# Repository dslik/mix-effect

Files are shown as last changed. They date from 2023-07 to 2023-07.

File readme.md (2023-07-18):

## Project Overview
An open-hardware moduar control surface for vision mixers, such as OBS and ATEM.

Modules include:

* 2810A/2811A Source Selectors
* 2820A/2821A Transtion Controllers
* 2850A/2851A Source Meters
* 2860A Level Controller
* 2880A Touch Screen Controller
* 2890A Power Controller

All modules fit into a standard Eurorack chassis (but do not use Eurorack power), allowing you to create your own layouts with as many sources and M/E channels as needed. This also allows additional custom and use-specific modules are easily added.

## Project Goals
* Modular: Combine functional blocks that way you need and the way you want.
* Extensible: Easy to add new functionality and modules.
* Open source: Available for use and extension with minimal restrictions. See the [license](./license.md) for more details.
* Low-cost: Each module's BOM costs under $100, with some modules costing under $50.

## Components

Part # | Name | Status | BOM Cost | OSHWA | Cert # |
|-|-|-|-|-|-|
| 2810A v1.4 | Four-channel Source Selector | Coming Soon | | Not OSHWA Certified | |
| 2811A v1.4 | Two-channel Source Selector with Shift | Coming Soon | | Not OSHWA Certified | |
| 2820A v0.2 | Transition Controller | Coming Soon | | Not OSHWA Certified | |
| 2821A v0.1 | Transition Controller Expansion | Coming Soon | | Not OSHWA Certified | |
| 2850A v1.0 | Four-channel Source Meters | Coming Soon | | Not OSHWA Certified | |
| 2851A v1.0 | Two-channel Source Meters with Shift | Coming Soon | | Not OSHWA Certified | |
| 2860A v0.2 | Source Level Controller | Coming Soon | | Not OSHWA Certified | |
| 2880A v0.2 | Touch Screen Controller | Coming Soon | | Not OSHWA Certified | |
| 2890A v0.1 | Power Controller | Coming Soon | | Not OSHWA Certified | |

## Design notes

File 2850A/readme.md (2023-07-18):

# Source Meters Module

Four-channel program audio monitor for input sources.

Initial features include:
- Four source inputs
- Stereo PPM meters per input source
- Select/mute button for source audio control
- Channel gain adjust when used with 2850A
- Compatible with mixers and DAWs that support Mackie Control Universal over MIDI

The many small LEDs on the 2850-0301 LED board are difficult to reliably hand-assembly, so this board is best ordered pre-assembled from your PCB house. BOM and component placement files are provided for this board (2850-0301).

Full assembly instructions will be uploaded soon.

# Build Journal

_Feel free to ask questions by opening an issue!_

## 2023-07-18

Here's what this module looks like fuly assembled:



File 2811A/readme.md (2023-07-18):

The 2811A uses the same boards as the 2810A, with the exception of the front panel.

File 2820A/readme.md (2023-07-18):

The Transition Controller is not fully completed or tested.

Specifically, the 2820-0401 board has known errata and needs to be updated.

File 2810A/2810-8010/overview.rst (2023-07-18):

********
Overview
********

This document describes the materials, processes, outcomes and verifications required to successfully assemble and test a 2810A Source Selector module, a sub-component of the Eurorack Mix/Effects Control Surface.

A first-time reader should carefully review section 2 - prerequisites, and section 3 - preparation before beginning the assembly process.

This document serves both as instructions and as a record of the assembly of the product. When you finish each step in this document, sign your name (or apply your stamp) in the "Signature/Stamp" box on the right to provide a record of completion.

When things go wrong, this document provides guidance for common issues that have been encountered in the past. When this document does not provide guidance, please contact your quality management representative, who will help you fill out an exception report. These reports help improve process quality and product quality, and these reports are incorporated into future revisions of this document.

Always remember: If you are unable to successfully complete these instructions, that means the processes supporting you (including this document) have failed you. Our processes are built for your success, and by improving our processes, we help everyone succeed.

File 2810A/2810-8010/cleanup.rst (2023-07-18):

********
Clean-up
********

Consumables
***********

This packaging process takes 5 minutes.

.. tabularcolumns:: |>{\raggedright\arraybackslash}\Y{0.10}
                    |>{\raggedright\arraybackslash}\Y{0.70}
                    |>{\raggedright\arraybackslash}\Y{0.20}|

.. _tbl_2810_cleanup_consumables:

.. list-table:: Consumables cleanup
    :class: longtable
    :header-rows: 1
    :align: center 

    * - Step #
      - Description
      - Signature
    * - 7.1.1
      - If the ESD gloves have contacted solder paste, or are soiled, they shall be disposed of in the standard waste bin.
      - 
        .. raw:: latex

          \includegraphics[align=t,scale=1]{../../images/doc_stamp.pdf}
    * - 7.1.2
      - If there is unused solder paste in the syringe, it shall be returned to stores.
      - 
        .. raw:: latex

          \includegraphics[align=t,scale=1]{../../images/doc_stamp.pdf}
    * - 7.1.3
      - If there is unused solder wire on the spool, it shall be returned to stores.
      - 
        .. raw:: latex

          \includegraphics[align=t,scale=1]{../../images/doc_stamp.pdf}
    * - 7.1.4
      - The Scott shop title shall be disposed of in the standard waste bin.
      - 
        .. raw:: latex

          \includegraphics[align=t,scale=1]{../../images/doc_stamp.pdf}
    * - 7.1.5
      - Reel tape cuttings and loose component packaging shall be disposed of in the standard waste bin.
      - 
        .. raw:: latex

          \includegraphics[align=t,scale=1]{../../images/doc_stamp.pdf}

Tools
*****

This cleanup process takes 5 minutes.

.. tabularcolumns:: |>{\raggedright\arraybackslash}\Y{0.10}
                    |>{\raggedright\arraybackslash}\Y{0.70}
                    |>{\raggedright\arraybackslash}\Y{0.20}|

.. _tbl_2810_cleanup_tools:

.. list-table:: Tools cleanup
    :class: longtable
    :header-rows: 1
    :align: center 

    * - Step #
      - Description
      - Signature
    * - 7.2.1
      - All tools shall be returned to the "M/E Assembly Tools" container, and returned to the stores supply shelf.

        .. raw:: latex

          \vspace*{1ex}

        If any tools are damaged or worn, return the container to stores, and let the manager know which tool is damaged or worn.
      - 
        .. raw:: latex

          \includegraphics[align=t,scale=1]{../../images/doc_stamp.pdf}
    * - 7.2.2
      - Remove this document from the springback binder.
      - 
        .. raw:: latex

          \includegraphics[align=t,scale=1]{../../images/doc_stamp.pdf}
    * - 7.2.3
      - Print a new copy of this document, and insert it into the springback binder that this document was originally in.
      - 
        .. raw:: latex

          \includegraphics[align=t,scale=1]{../../images/doc_stamp.pdf}
    * - 7.2.4
      - Return the springback binder with the newly printed document to the 2810A section of the store supply shelf.
      - 
        .. raw:: latex

          \includegraphics[align=t,scale=1]{../../images/doc_stamp.pdf}

.. raw:: latex

          \newpage

Workspace
*********

This packaging process takes 5 minutes.

.. tabularcolumns:: |>{\raggedright\arraybackslash}\Y{0.10}
                    |>{\raggedright\arraybackslash}\Y{0.70}
                    |>{\raggedright\arraybackslash}\Y{0.20}|

.. _tbl_2810_cleanup_workspace:

.. list-table:: Workspace cleanup
    :class: longtable
    :header-rows: 1
    :align: center 

    * - Step #
      - Description
      - Signature
    * - 7.3.1
      - Make sure that the workspace is clean and as it was when you started the assembly.

        .. raw:: latex

          \vspace*{1ex}

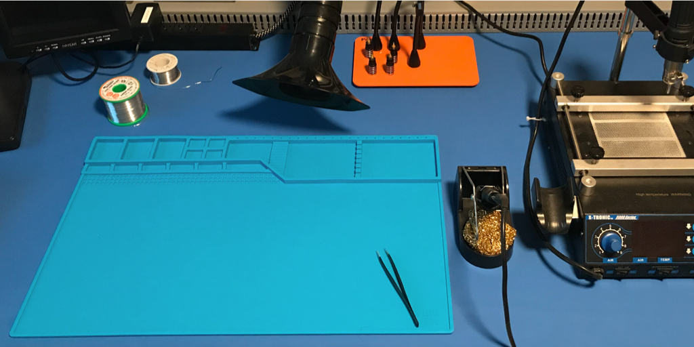
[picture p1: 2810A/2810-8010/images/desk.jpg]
        
           
            Clean assembly workstation
      - 
        .. raw:: latex

          \includegraphics[align=t,scale=1]{../../images/doc_stamp.pdf}

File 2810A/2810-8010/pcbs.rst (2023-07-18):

**********************
Printed Circuit Boards
**********************

2810-0101 PCB
--------------

.. tabularcolumns:: |>{\raggedright\arraybackslash}\Y{1}|

.. _tbl_pcb_2810_0101:

.. list-table:: 2810-0101 PCB
    :class: longtable
    :header-rows: 1
    :align: center 

    * - 2810-0101 PCB
    * - 
        .. _fig_2810_0101_front:

        

            2810-0101 PCB Front
    * - 
        .. _fig_2810_0101_rear:

        

            2810-0101 PCB Rear

.. raw:: latex

          \newpage

2810-0201 PCB
--------------

.. tabularcolumns:: |>{\raggedright\arraybackslash}\Y{1}|

.. _tbl_pcb_2810_0201:

.. list-table:: 2810-0201 PCB
    :class: longtable
    :header-rows: 1
    :align: center 

    * - 2810-0201 PCB
    * - 
        .. _fig_2810_0201_front:

        

            2810-0201 PCB Front
    * - 
        .. _fig_2810_0201_rear:

        

            2810-0201 PCB Rear

.. raw:: latex

          \newpage

2810-0301 PCB
--------------

.. tabularcolumns:: |>{\raggedright\arraybackslash}\Y{1}|

.. _tbl_pcb_2810_0301:

.. list-table:: 2810-0301 PCB
    :class: longtable
    :header-rows: 1
    :align: center 

    * - 2810-0301 PCB
    * - 
        .. _fig_2810_0301_front:

        

            2810-0301 PCB Front
    * - 
        .. _fig_2810_0301_rear:

        

            2810-0301 PCB Rear

.. raw:: latex

          \newpage

2810-0401 PCB
--------------

.. tabularcolumns:: |>{\raggedright\arraybackslash}\Y{1}|

.. _tbl_pcb_2810_0401:

.. list-table:: 2810-0401 PCB
    :class: longtable
    :header-rows: 1
    :align: center 

    * - 2810-0401 PCB
    * - 
        .. _fig_2810_0401_front:

        

            2810-0401 PCB Front
    * - 
        .. _fig_2810_0401_rear:

        

            2810-0401 PCB Rear

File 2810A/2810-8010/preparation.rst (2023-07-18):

***********
Preparation
***********

Workspace
*********

Before starting assembly, check out an assembly desk for a minimum of two hours. A single unit can be assembled in two hours, with an additional hour per additional unit.

.. _fig_assembly_desk:


   
    Assembly Desk

.. tabularcolumns:: |>{\raggedright\arraybackslash}\Y{0.10}
                    |>{\raggedright\arraybackslash}\Y{0.70}
                    |>{\raggedright\arraybackslash}\Y{0.20}|

.. _tbl_prep_workspace:

.. list-table:: Prepare workspace
    :class: longtable
    :header-rows: 1
    :align: center 

    * - Step
      - Description
      - Signature/Stamp
    * - 3.1.1
      - Verify that the workspace has a clean assembly mat and anti-static mat, and that the cleaning record has been signed since last use.
      - 
        .. raw:: latex

          \includegraphics[align=t,scale=1]{../../images/doc_stamp.pdf}

    * - 3.1.2
      - Verify that the HEPA fume extractor turns on, and you can feel air suction from the nozzle.
      - 
        .. raw:: latex

          \includegraphics[align=t,scale=1]{../../images/doc_stamp.pdf}

    * - 3.1.3
      - Verify that the 5040-XTS rework station soldering iron tip is not worn down. If it is worn down, obtain a new 900M-T-I tip from the stores department.
      - 
        .. raw:: latex

          \includegraphics[align=t,scale=1]{../../images/doc_stamp.pdf}

Project consumables
*******************

Obtain each of the below consumable items from the stores department:

.. tabularcolumns:: |>{\raggedright\arraybackslash}\Y{0.10}
                    |>{\raggedright\arraybackslash}\Y{0.70}
                    |>{\raggedright\arraybackslash}\Y{0.20}|

.. _tbl_2810_consumables:

.. list-table:: Assembly consumables
    :class: longtable
    :header-rows: 1
    :align: center 

    * - Item #
      - Description
      - Signature/Stamp
    * - 3.2.1
      - 
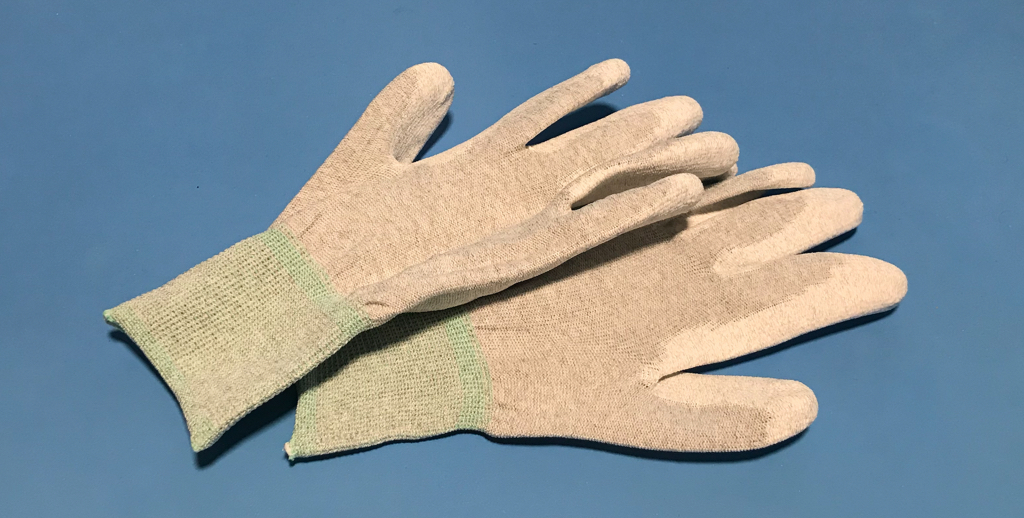
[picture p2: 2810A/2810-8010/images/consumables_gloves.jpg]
        
           
            1 pair ESD gloves

        If you prefer to use your own pair of ESD gloves, make sure they are tested before use.
      - 
        .. raw:: latex

          \raisebox{15\height}{\includegraphics[align=t,scale=1]{../../images/doc_stamp.pdf}}

    * - 3.2.2
      - 
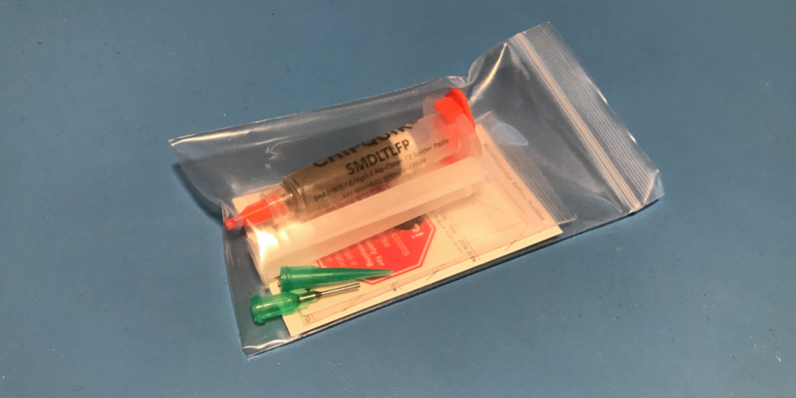
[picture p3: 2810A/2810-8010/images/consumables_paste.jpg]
        
           
            1 syringe of Chip Quik SMDLTLFP Solder Paste Sn42/Bi57.6/Ag0.4 No-Clean Lead Free
      - 
        .. raw:: latex

          \raisebox{15\height}{\includegraphics[align=t,scale=1]{../../images/doc_stamp.pdf}}

    * - 3.2.3
      - 
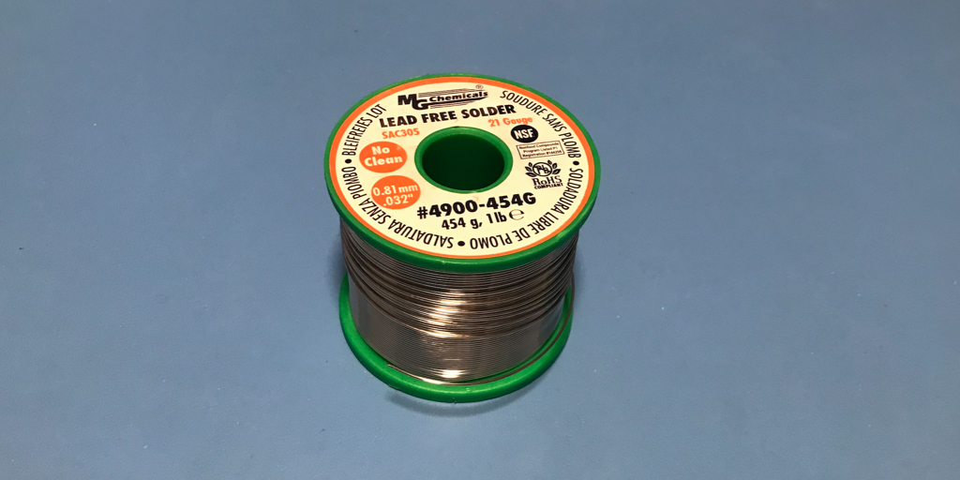
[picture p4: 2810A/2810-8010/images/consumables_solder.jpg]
        
           
            1 spool MG Chemicals 4900 Lead Free No-Clean Wire Solder Sn96.2Ag2.8Cu0.4 (96.2/2.8/0.4) 20 AWG
      - 
        .. raw:: latex

          \raisebox{15\height}{\includegraphics[align=t,scale=1]{../../images/doc_stamp.pdf}}

    * - 3.2.4
      - 
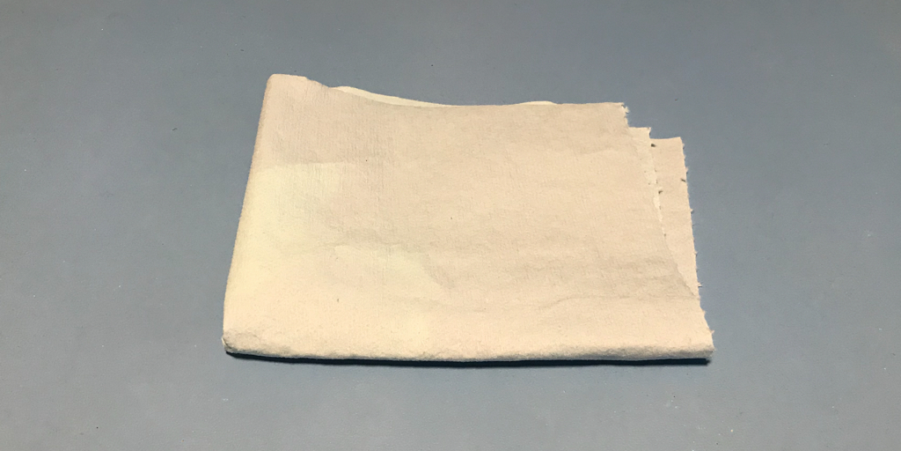
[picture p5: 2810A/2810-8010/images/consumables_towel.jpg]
        
           
            1 square of Scott Shop Towel
      - 
        .. raw:: latex

          \raisebox{15\height}{\includegraphics[align=t,scale=1]{../../images/doc_stamp.pdf}}

.. raw:: latex

          \newpage

Project tools
*************

Obtain a tools container labelled "28XX Assembly Tools" from the 28XX section of the stores supply shelf. At your assembly desk, use :numref:`tbl_2810_tools` to verify that all the required tools are present.

If any required tools are missing, return all tools and the tools container to the stores department, and obtain another tools container.

.. _fig_assembly_tools:

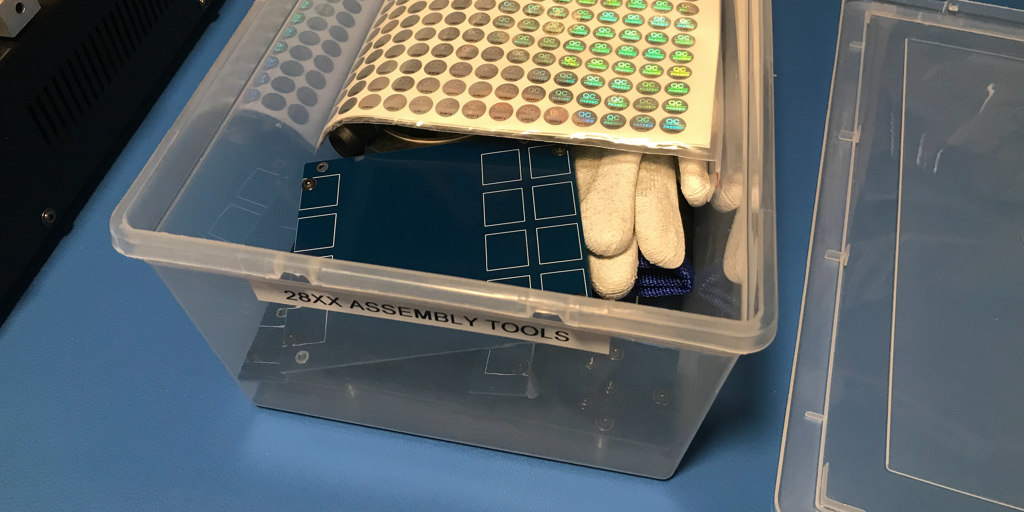
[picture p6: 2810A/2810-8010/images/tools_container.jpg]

   
    Tools Container

Remove each of the following tools from the tools container, and place them on the anti-static mat of the assembly desk:

.. tabularcolumns:: |>{\raggedright\arraybackslash}\Y{0.10}
                    |>{\raggedright\arraybackslash}\Y{0.70}
                    |>{\raggedright\arraybackslash}\Y{0.20}|

.. _tbl_2810_tools:

.. list-table:: Assembly tools
    :class: longtable
    :header-rows: 1
    :align: center 

    * - Item #
      - Description
      - Signature/Stamp
    * - 3.3.1
      - 
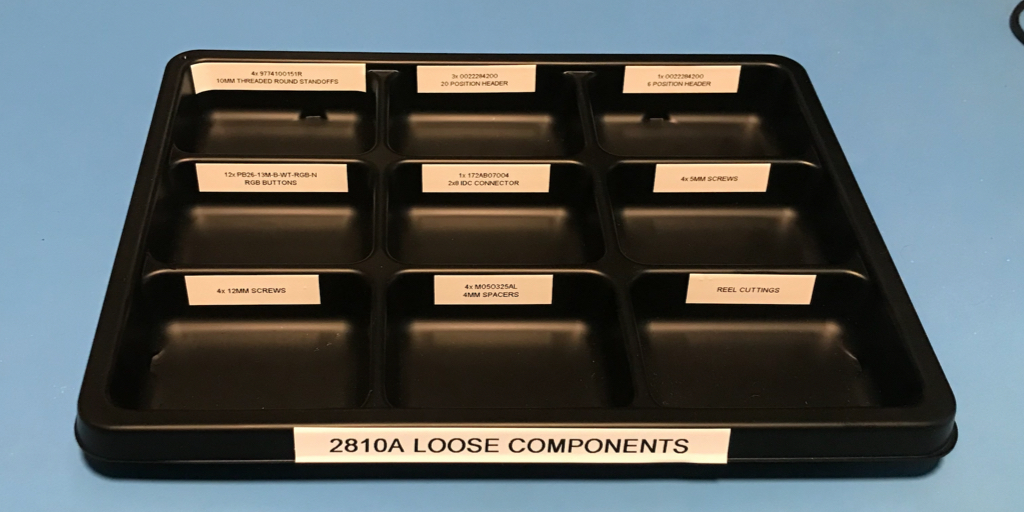
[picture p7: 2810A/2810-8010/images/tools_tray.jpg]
        
           
            Hozan F-23 components tray
      - 
        .. raw:: latex

          \raisebox{15\height}{\includegraphics[align=t,scale=1]{../../images/doc_stamp.pdf}}
    * - 3.3.2
      - 
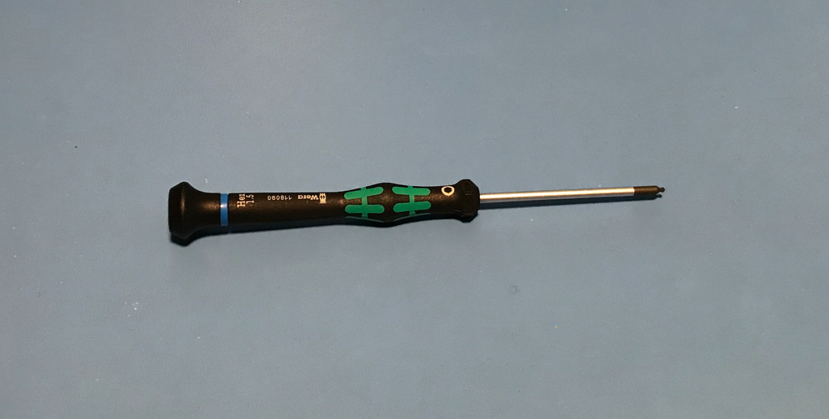
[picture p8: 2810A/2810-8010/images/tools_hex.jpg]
        
           
            1.5mm Hex screwdriver
      - 
        .. raw:: latex

          \raisebox{15\height}{\includegraphics[align=t,scale=1]{../../images/doc_stamp.pdf}}
    * - 3.3.3
      - 
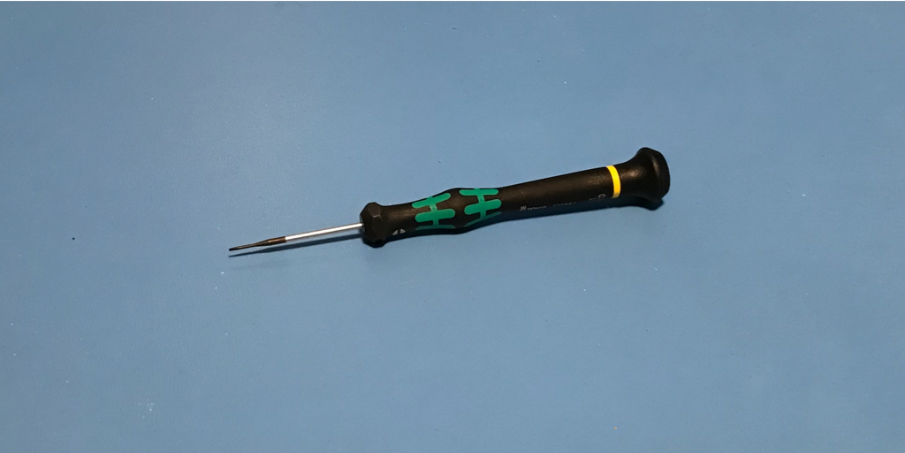
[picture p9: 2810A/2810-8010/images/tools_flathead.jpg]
        
           
            1mm flat-head screwdriver
      - 
        .. raw:: latex

          \raisebox{15\height}{\includegraphics[align=t,scale=1]{../../images/doc_stamp.pdf}}
    * - 3.3.4
      - 
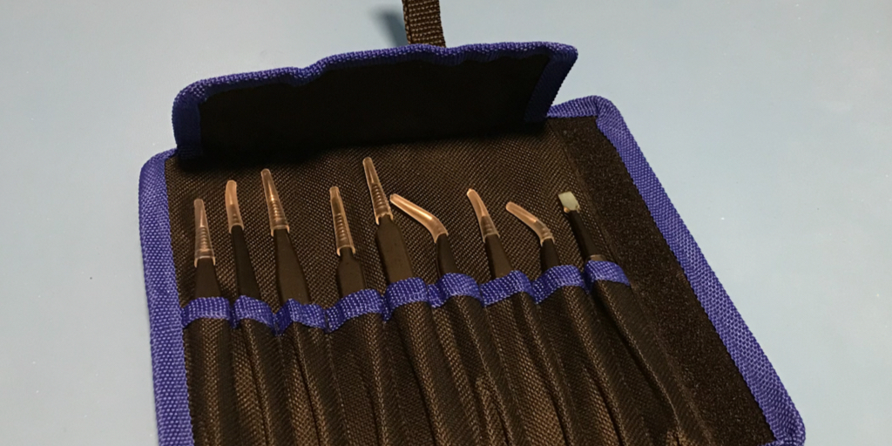
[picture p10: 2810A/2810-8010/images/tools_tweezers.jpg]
        
           
            ESD tweezers
      - 
        .. raw:: latex

          \raisebox{15\height}{\includegraphics[align=t,scale=1]{../../images/doc_stamp.pdf}}
    * - 3.3.5
      - 
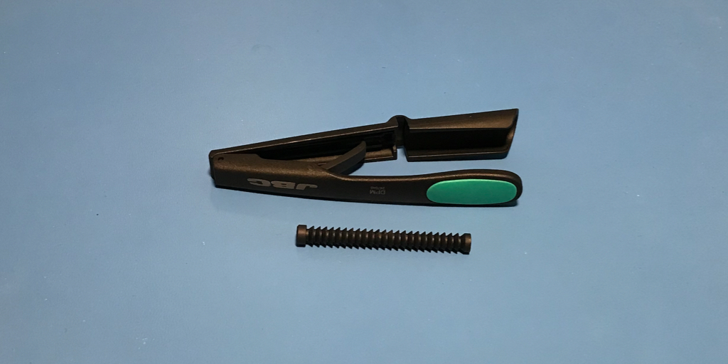
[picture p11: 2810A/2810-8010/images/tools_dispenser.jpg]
        
           
            Solder paste dispenser
      - 
        .. raw:: latex

          \raisebox{15\height}{\includegraphics[align=t,scale=1]{../../images/doc_stamp.pdf}}
    * - 3.3.6
      - 
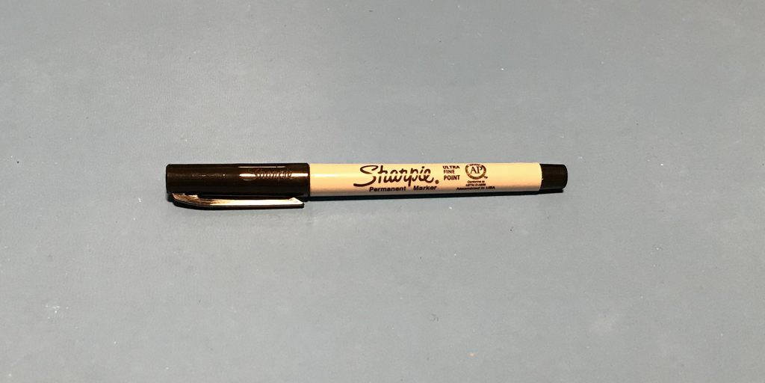
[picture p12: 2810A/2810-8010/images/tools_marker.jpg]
        
           
            Fine-tipped Sharpie marker
      - 
        .. raw:: latex

          \raisebox{15\height}{\includegraphics[align=t,scale=1]{../../images/doc_stamp.pdf}}
    * - 3.3.7
      - 
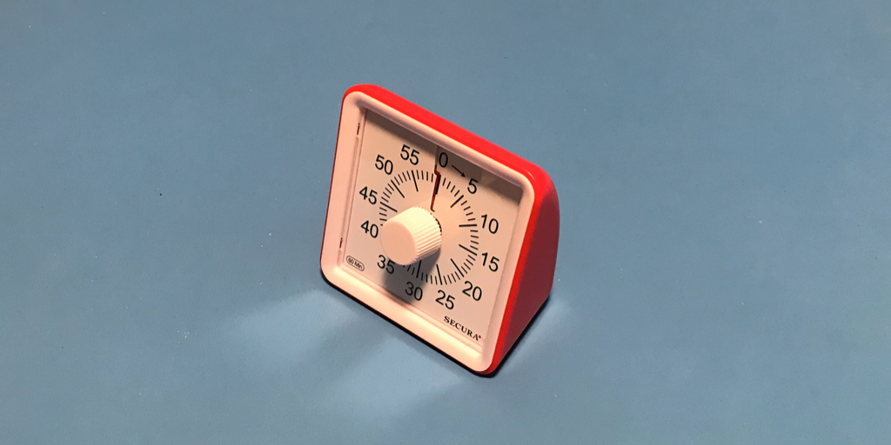
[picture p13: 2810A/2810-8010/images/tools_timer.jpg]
        
           
            Countdown timer
      - 
        .. raw:: latex

          \raisebox{15\height}{\includegraphics[align=t,scale=1]{../../images/doc_stamp.pdf}}
    * - 3.3.8
      - 
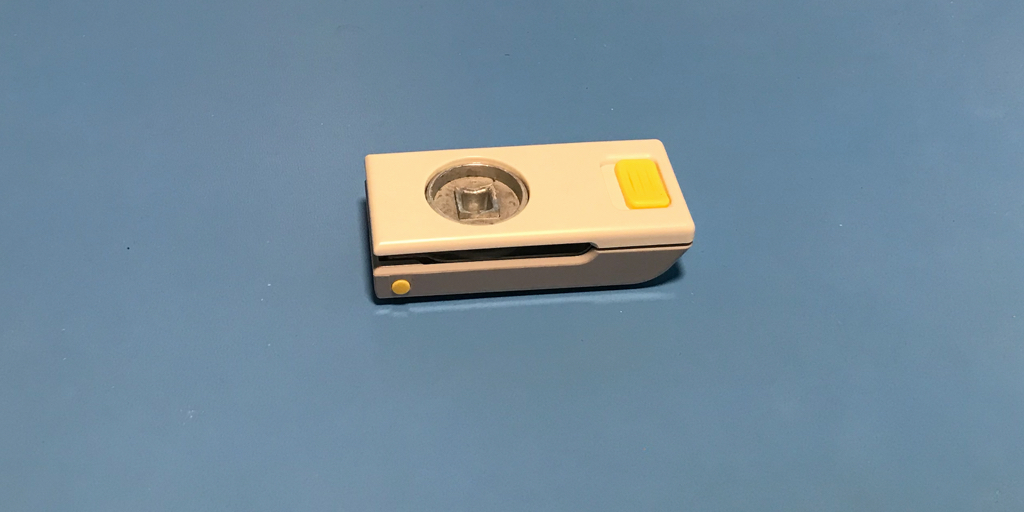
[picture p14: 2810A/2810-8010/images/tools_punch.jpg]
        
           
            Button label cutter
      - 
        .. raw:: latex

          \raisebox{15\height}{\includegraphics[align=t,scale=1]{../../images/doc_stamp.pdf}}
    * - 3.3.9
      - 
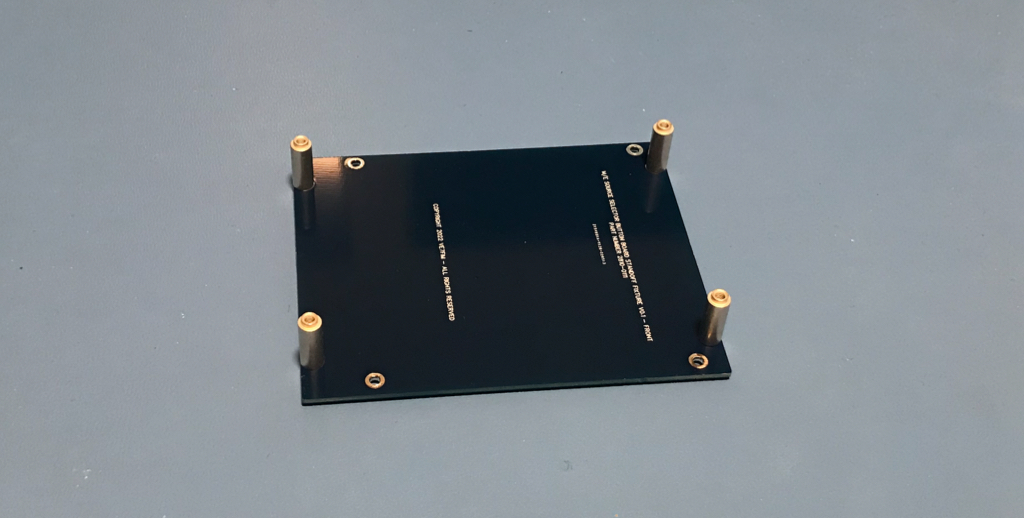
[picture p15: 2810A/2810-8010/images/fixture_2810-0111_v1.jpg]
        
           
            2810-0111 v0.2 fixture
      - 
        .. raw:: latex

          \raisebox{15\height}{\includegraphics[align=t,scale=1]{../../images/doc_stamp.pdf}}
    * - 3.3.10
      - 
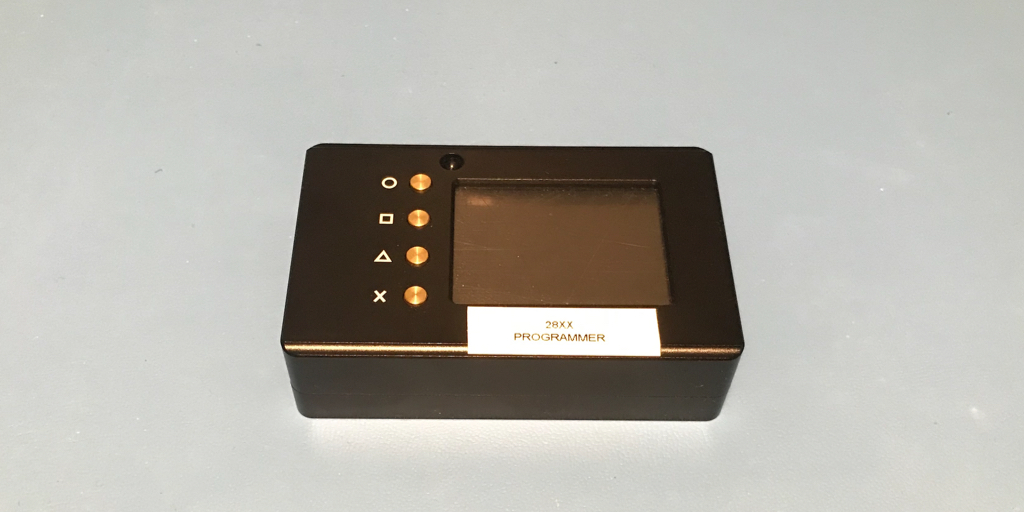
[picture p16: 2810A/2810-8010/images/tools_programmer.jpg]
        
           
            28XX programmer
      - 
        .. raw:: latex

          \raisebox{15\height}{\includegraphics[align=t,scale=1]{../../images/doc_stamp.pdf}}
    * - 3.3.11
      - 
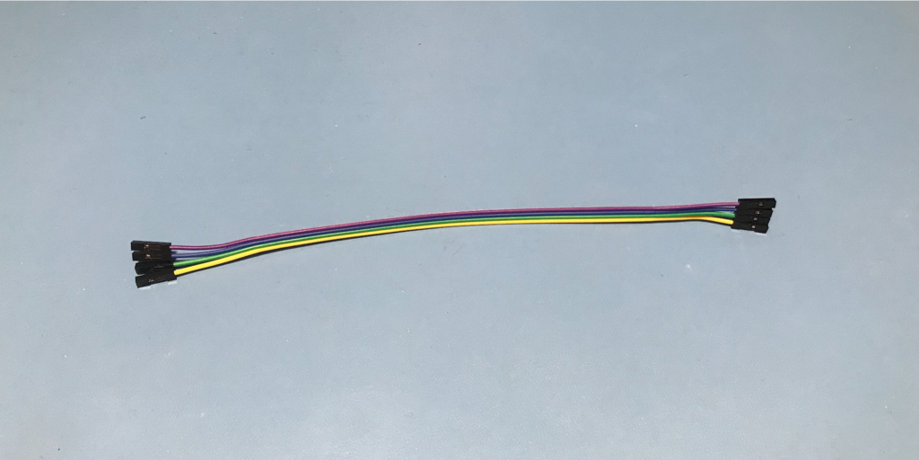
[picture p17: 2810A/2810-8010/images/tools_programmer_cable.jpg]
        
           
            28XX programmer power cable
      - 
        .. raw:: latex

          \raisebox{15\height}{\includegraphics[align=t,scale=1]{../../images/doc_stamp.pdf}}
    * - 3.3.12
      - 
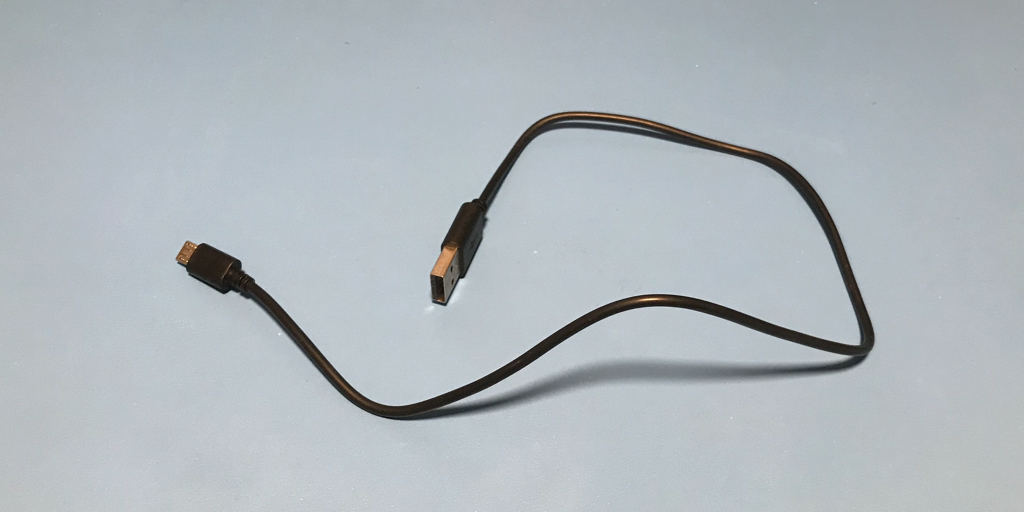
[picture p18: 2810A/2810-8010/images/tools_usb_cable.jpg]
        
           
            USB to Micro USB cable
      - 
        .. raw:: latex

          \raisebox{15\height}{\includegraphics[align=t,scale=1]{../../images/doc_stamp.pdf}}
    * - 3.3.13
      - 
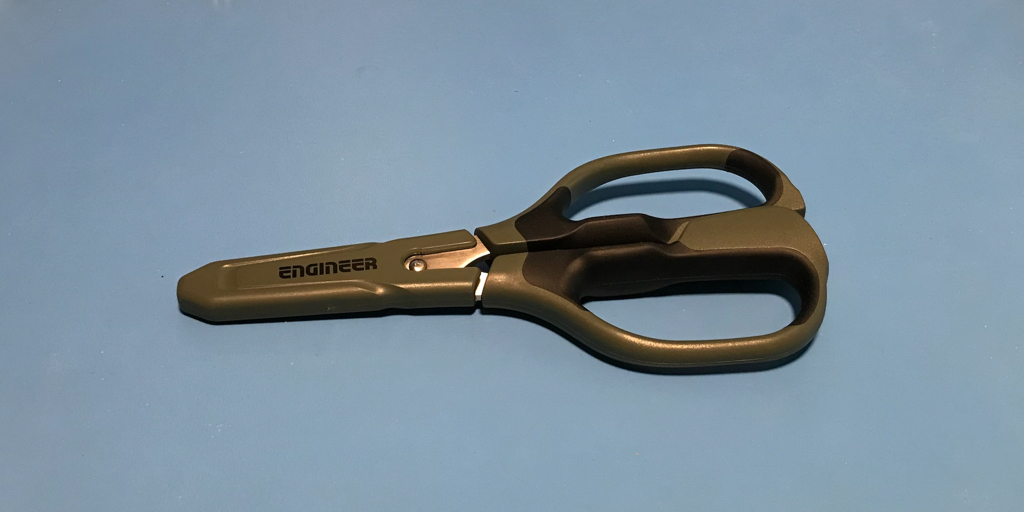
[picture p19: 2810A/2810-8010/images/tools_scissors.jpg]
        
           
            Sissors
      - 
        .. raw:: latex

          \raisebox{15\height}{\includegraphics[align=t,scale=1]{../../images/doc_stamp.pdf}}

.. raw:: latex

          \newpage

Parts preparation
*****************

PCBs and PCBAs
--------------

NOTICE: All PCBs and PCBAs must be handled with gloves to prevent marking with skin oils.

NOTICE: PCBs are removed from manufacturer packaging only when needed.

.. tabularcolumns:: |>{\raggedright\arraybackslash}\Y{0.10}
                    |>{\raggedright\arraybackslash}\Y{0.70}
                    |>{\raggedright\arraybackslash}\Y{0.20}|

.. _tbl_2810_pcbs:

.. list-table:: PCBs and PCBAs
    :class: longtable
    :header-rows: 1
    :align: center 

    * - Item #
      - Description
      - Signature/Stamp
    * - 3.4.1.1
      - No marking required

        .. raw:: latex

          \vspace*{1ex}

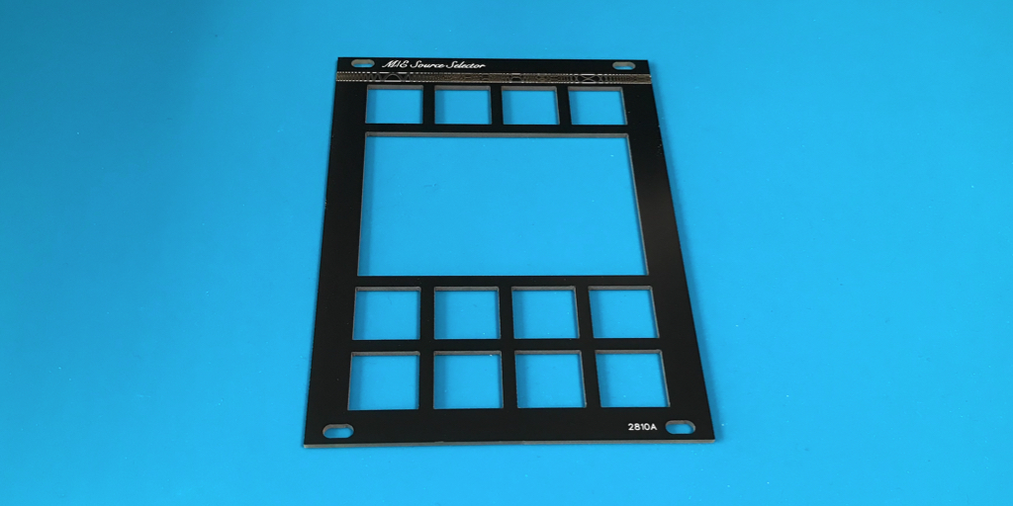
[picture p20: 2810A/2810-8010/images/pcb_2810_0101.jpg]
        
           
            1x 2810-0101 v1.2 - Front Panel PCB
      - 
        .. raw:: latex

          \includegraphics[align=t,scale=1]{../../images/doc_stamp.pdf}
    * - 3.4.1.2
      - No marking required

        .. raw:: latex

          \vspace*{1ex}

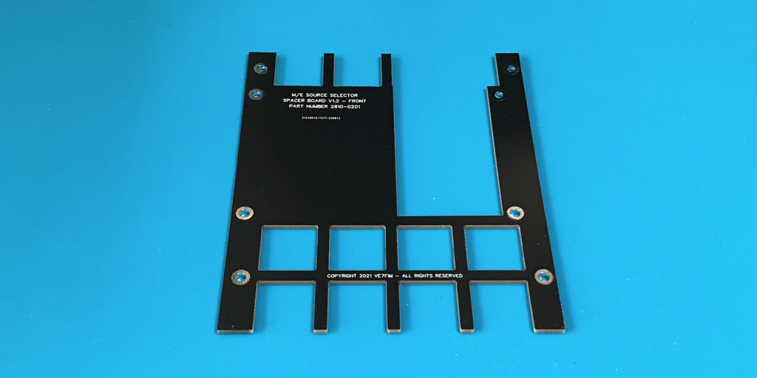
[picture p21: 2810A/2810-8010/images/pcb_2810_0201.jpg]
        
           
            1x 2810-0201 v1.2 - Button Spacer PCB
      - 
        .. raw:: latex

          \includegraphics[align=t,scale=1]{../../images/doc_stamp.pdf}
    * - 3.4.1.3
      - No marking required

        .. raw:: latex

          \vspace*{1ex}

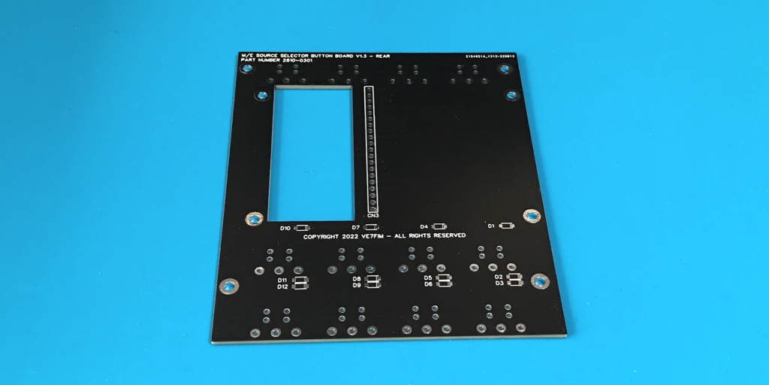
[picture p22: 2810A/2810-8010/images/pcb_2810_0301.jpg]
        
           
            1x 2810-0301 v1.3 - Button Board PCB
      - 
        .. raw:: latex

          \includegraphics[align=t,scale=1]{../../images/doc_stamp.pdf}
    * - 3.4.1.4
      - No marking required

        .. raw:: latex

          \vspace*{1ex}

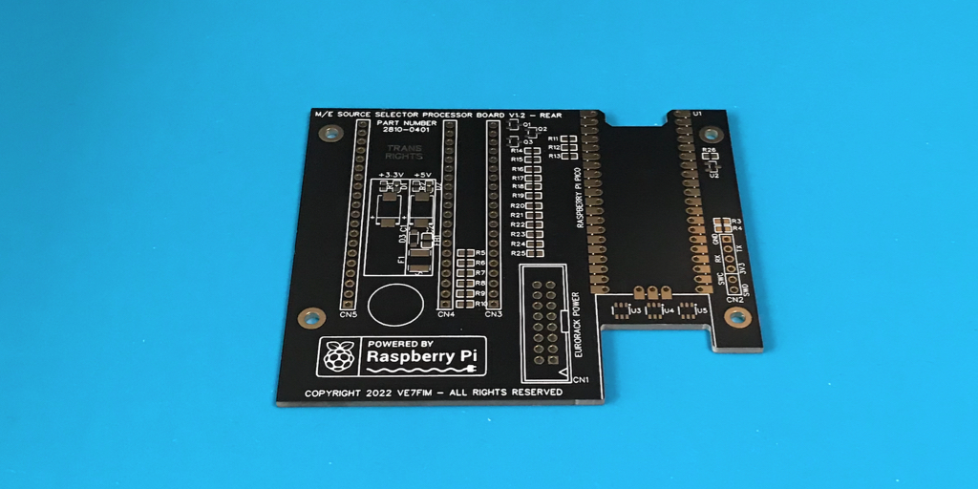
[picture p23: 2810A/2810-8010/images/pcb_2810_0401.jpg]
        
           
            1x 2810-0401 v1.2 - Processor PCB
      - 
        .. raw:: latex

          \includegraphics[align=t,scale=1]{../../images/doc_stamp.pdf}
    * - 3.4.1.5
      - No marking required

        .. raw:: latex

          \vspace*{1ex}

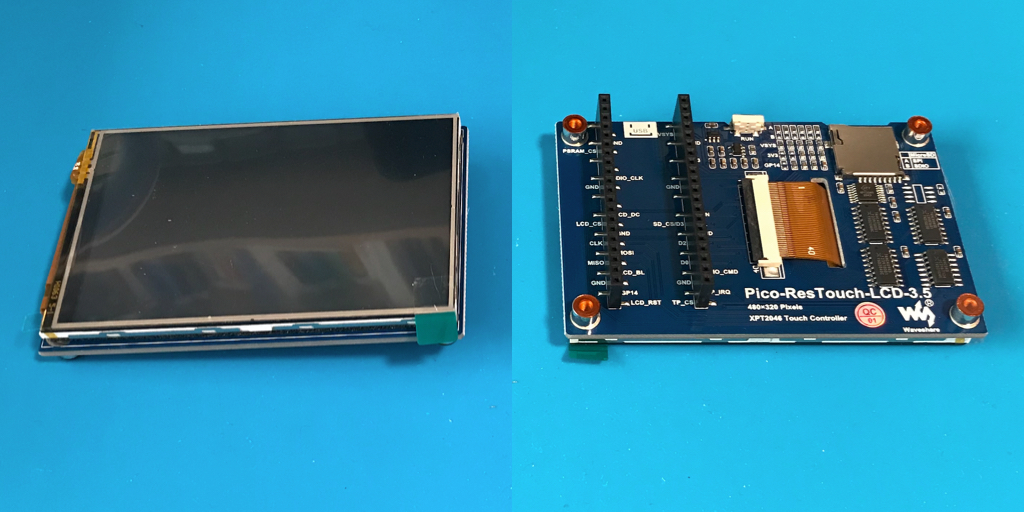
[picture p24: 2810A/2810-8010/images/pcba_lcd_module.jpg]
        
           
            1x Pico-ResTouch-LCD-3.5 - LCD Module
      - 
        .. raw:: latex

          \includegraphics[align=t,scale=1]{../../images/doc_stamp.pdf}

.. raw:: latex

          \newpage

Reel cuttings
-------------

All reels are stored in the bin labelled "28XX Reels" on the shelf labelled "28XX Components". As this is a manually assembled product (no automated pick-and-place), tape should be cut off as needed for the number of units being assembled, and placed in the assembly tray.

.. _fig_assembly_reels:


   
    Reels Container

Cut off the indicated number of parts (multipled by the number of units to be assembled), and mark them with the value:

.. tabularcolumns:: |>{\raggedright\arraybackslash}\Y{0.10}
                    |>{\raggedright\arraybackslash}\Y{0.70}
                    |>{\raggedright\arraybackslash}\Y{0.20}|

.. _tbl_2810_reels:

.. list-table:: Assembly reels
    :class: longtable
    :header-rows: 1
    :align: center 

    * - Reel #
      - Description
      - Signature/Stamp
    * - 3.4.2.1
      - Mark with "330R"

        .. raw:: latex

          \vspace*{1ex}

        
           
            12x 330 Ohm 0603 resistors
      - 
        .. raw:: latex

          \includegraphics[align=t,scale=1]{../../images/doc_stamp.pdf}
    * - 3.4.2.2
      - Mark with "649R"

        .. raw:: latex

          \vspace*{1ex}

        (Cut off a minimum of 4 to have enough room to label)

        
           
            1x 649 Ohm 0603 resistors
      - 
        .. raw:: latex

          \includegraphics[align=t,scale=1]{../../images/doc_stamp.pdf}
    * - 3.4.2.3
      - Mark with "1KR"

        .. raw:: latex

          \vspace*{1ex}

        (Cut off a minimum of 4 to have enough room to label)

        
           
            3x 1K Ohm 0603 resistors
      - 
        .. raw:: latex

          \includegraphics[align=t,scale=1]{../../images/doc_stamp.pdf}
    * - 3.4.2.4
      - Mark with "2KR"

        .. raw:: latex

          \vspace*{1ex}

        (Cut off a minimum of 4 to have enough room to label)

        
           
            1x 2K Ohm 0603 resistors
      - 
        .. raw:: latex

          \includegraphics[align=t,scale=1]{../../images/doc_stamp.pdf}
    * - 3.4.2.5
      - Mark with "4KR"

        .. raw:: latex

          \vspace*{1ex}

        (Cut off a minimum of 4 to have enough room to label)

        
           
            1x 4.02K Ohm 0603 resistors
      - 
        .. raw:: latex

          \includegraphics[align=t,scale=1]{../../images/doc_stamp.pdf}
    * - 3.4.2.6
      - Mark with "8KR"

        .. raw:: latex

          \vspace*{1ex}

        (Cut off a minimum of 4 to have enough room to label)

        
           
            1x 8.06K Ohm 0603 resistors
      - 
        .. raw:: latex

          \includegraphics[align=t,scale=1]{../../images/doc_stamp.pdf}
    * - 3.4.2.7
      - Mark with "10KR"

        .. raw:: latex

          \vspace*{1ex}

        
           
            6x 10K Ohm 0603 resistors
      - 
        .. raw:: latex

          \includegraphics[align=t,scale=1]{../../images/doc_stamp.pdf}
    * - 3.4.2.8
      - No marking required

        .. raw:: latex

          \vspace*{1ex}

        
           
            13x 1N4148W-7-F diodes
      - 
        .. raw:: latex

          \includegraphics[align=t,scale=1]{../../images/doc_stamp.pdf}
    * - 3.4.2.9
      - No marking required

        .. raw:: latex

          \vspace*{1ex}

        
           
            3x MMBT3906LT1 transistors
      - 
        .. raw:: latex

          \includegraphics[align=t,scale=1]{../../images/doc_stamp.pdf}
    * - 3.4.2.10
      - Mark with "FB"

        .. raw:: latex

          \vspace*{1ex}

        (Cut off a minimum of 4 to have enough room to label)

        
           
            1x GZ2012D601TF ferrite beads
      - 
        .. raw:: latex

          \includegraphics[align=t,scale=1]{../../images/doc_stamp.pdf}
    * - 3.4.2.11
      - No marking required

        .. raw:: latex

          \vspace*{1ex}

        
           
            2x TPSD226K025R0200 tantalum capacitors
      - 
        .. raw:: latex

          \includegraphics[align=t,scale=1]{../../images/doc_stamp.pdf}
    * - 3.4.2.12
      - No marking required

        .. raw:: latex

          \vspace*{1ex}

        
           
            1x MINISMDC050F-2 self-resetting fuse
      - 
        .. raw:: latex

          \includegraphics[align=t,scale=1]{../../images/doc_stamp.pdf}
    * - 3.4.2.13
      - No marking required

        .. raw:: latex

          \vspace*{1ex}

        
           
            2x SML-LXT0805GW-TR green LED
      - 
        .. raw:: latex

          \includegraphics[align=t,scale=1]{../../images/doc_stamp.pdf}
    * - 3.4.2.14
      - No marking required

        .. raw:: latex

          \vspace*{1ex}

        
           
            1x SC0915 Pi Pico module
      - 
        .. raw:: latex

          \includegraphics[align=t,scale=1]{../../images/doc_stamp.pdf}
    * - 3.4.2.15
      - No marking required

        .. raw:: latex

          \vspace*{1ex}

        
           
            1x LM4040BIM3-3.0 voltage reference
      - 
        .. raw:: latex

          \includegraphics[align=t,scale=1]{../../images/doc_stamp.pdf}
    * - 3.4.2.16
      - No marking required

        .. raw:: latex

          \vspace*{1ex}

        
           
            3x UDT26A05L05 ESD protection
      - 
        .. raw:: latex

          \includegraphics[align=t,scale=1]{../../images/doc_stamp.pdf}

Be sure to return the 28XX Reels bin as soon as you have finished cutting off the required parts.

.. raw:: latex

          \newpage

Loose components
----------------

All loose components are stored on the shelf labelled "28XX Components". Take the components tray and obtain the following quanities of the folloiwng parts:

.. tabularcolumns:: |>{\raggedright\arraybackslash}\Y{0.10}
                    |>{\raggedright\arraybackslash}\Y{0.70}
                    |>{\raggedright\arraybackslash}\Y{0.20}|

.. _tbl_2810_loose_parts:

.. list-table:: Loose components
    :class: longtable
    :header-rows: 1
    :align: center 

    * - Item #
      - Description
      - Signature/Stamp
    * - 3.4.3.1
      - No marking required

        .. raw:: latex

          \vspace*{1ex}

        
           
            4x 9774100151R - 10mm Threaded Round Standoffs
      - 
        .. raw:: latex

          \includegraphics[align=t,scale=1]{../../images/doc_stamp.pdf}
    * - 3.4.3.2
      - No marking required

        .. raw:: latex

          \vspace*{1ex}

        
           
            3x 0022284200 - 20 Position Header
      - 
        .. raw:: latex

          \includegraphics[align=t,scale=1]{../../images/doc_stamp.pdf}
    * - 3.4.3.3
      - No marking required

        .. raw:: latex

          \vspace*{1ex}

        
           
            1x 0022284200 - 6 Position Header
      - 
        .. raw:: latex

          \includegraphics[align=t,scale=1]{../../images/doc_stamp.pdf}
    * - 3.4.3.4
      - No marking required

        .. raw:: latex

          \vspace*{1ex}

        
           
            12x PB26­-13M-­B-­WT-RGB-­N - RGB Buttons
      - 
        .. raw:: latex

          \includegraphics[align=t,scale=1]{../../images/doc_stamp.pdf}
    * - 3.4.3.5
      - No marking required

        .. raw:: latex

          \vspace*{1ex}

        
           
            1x 0172­A­B07­004 - 2x8 IDC Connector
      - 
        .. raw:: latex

          \includegraphics[align=t,scale=1]{../../images/doc_stamp.pdf}
    * - 3.4.3.6
      - No marking required

        .. raw:: latex

          \vspace*{1ex}

        
           
            4x 5mm Screws

        Use the Scott towel to remove any machining oil that is left on the screws before placing it in the components tray.
      - 
        .. raw:: latex

          \includegraphics[align=t,scale=1]{../../images/doc_stamp.pdf}
    * - 3.4.3.7
      - No marking required

        .. raw:: latex

          \vspace*{1ex}

        
           
            4x 12mm Screws

        Use the Scott towel to remove any machining oil that is left on the screws before placing it in the components tray.
      - 
        .. raw:: latex

          \includegraphics[align=t,scale=1]{../../images/doc_stamp.pdf}
    * - 3.4.3.8
      - No marking required

        .. raw:: latex

          \vspace*{1ex}

        
           
            4x M0503­25­AL - 4mm Spacers
      - 
        .. raw:: latex

          \includegraphics[align=t,scale=1]{../../images/doc_stamp.pdf}
    * - 3.4.3.9
      - No marking required

        .. raw:: latex

          \vspace*{1ex}

        
           
            Reel cuttings
      - 
        .. raw:: latex

          \includegraphics[align=t,scale=1]{../../images/doc_stamp.pdf}

.. raw:: latex

          \newpage

Packaging materials
-------------------

All packaging materials are stored on the shelf labelled "28XX Components". Take the packaging box and obtain the following quanities of the folloiwng materials:

.. tabularcolumns:: |>{\raggedright\arraybackslash}\Y{0.10}
                    |>{\raggedright\arraybackslash}\Y{0.70}
                    |>{\raggedright\arraybackslash}\Y{0.20}|

.. _tbl_2810_packaging_materials:

.. list-table:: Packaging materials
    :class: longtable
    :header-rows: 1
    :align: center 

    * - Item #
      - Description
      - Signature/Stamp
    * - 3.4.4.1
      - No marking required

        .. raw:: latex

          \vspace*{1ex}

        
           
            1x QC Sticker
      - 
        .. raw:: latex

          \includegraphics[align=t,scale=1]{../../images/doc_stamp.pdf}
    * - 3.4.4.2
      - No marking required

        .. raw:: latex

          \vspace*{1ex}

        
           
            1x Medium size anti-static bag
      - 
        .. raw:: latex

          \includegraphics[align=t,scale=1]{../../images/doc_stamp.pdf}
    * - 3.4.4.3
      - No marking required

        .. raw:: latex

          \vspace*{1ex}

        
           
            1x Small size anti-static bag
      - 
        .. raw:: latex

          \includegraphics[align=t,scale=1]{../../images/doc_stamp.pdf}
    * - 3.4.4.4
      - No marking required

        .. raw:: latex

          \vspace*{1ex}

        
           
            1x Packing box with foam inserts
      - 
        .. raw:: latex

          \includegraphics[align=t,scale=1]{../../images/doc_stamp.pdf}
    * - 3.4.4.5
      - No marking required

        .. raw:: latex

          \vspace*{1ex}

        
           
            2x 2810A Stickers
      - 
        .. raw:: latex

          \includegraphics[align=t,scale=1]{../../images/doc_stamp.pdf}
    * - 3.4.4.6
      - No marking required

        .. raw:: latex

          \vspace*{1ex}

        
           
            Roll of packing tape
      - 
        .. raw:: latex

          \includegraphics[align=t,scale=1]{../../images/doc_stamp.pdf}

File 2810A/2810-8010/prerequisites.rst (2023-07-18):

*************
Prerequisites
*************

Required safety training
************************

The following safety training units must be completed before assembling this product.

By signing (or applying your stamp) on the right, you indicate that you have completed the following training:

.. tabularcolumns:: |>{\raggedright\arraybackslash}\Y{0.10}
                    |>{\raggedright\arraybackslash}\Y{0.70}
                    |>{\raggedright\arraybackslash}\Y{0.20}|

.. _tbl_safety_training:

.. list-table:: Safety training
    :class: longtable
    :header-rows: 1
    :align: center 

    * - Item #
      - Description
      - Signature/Stamp
    * - 2.1.1
      - 0102-0100 - Safety reporting policies and procedures training

        .. raw:: latex

          \vspace*{1ex}

        Key topics: Understanding policies and procedures around how to identify, contain and report a safety-related issue in the workplace, including damaged or malfunctioning equipment, leaks, spills, and other occupational hazards.
      - 
        .. raw:: latex

          \includegraphics[align=t,scale=1]{../../images/doc_stamp.pdf}

    * - 2.1.2
      - 0102-0101 - Material safety data sheets training

        .. raw:: latex

          \vspace*{1ex}

        Key topics: Understanding how to read material safety data sheets (MSDS) for materials you will be handling during product assembly, how they can affect your health and the health of the enviroment, how to safely handle and dispose of them, and what to do if there is a spill or accidential exposure.
      - 
        .. raw:: latex

          \includegraphics[align=t,scale=1]{../../images/doc_stamp.pdf}

    * - 2.1.3
      - 0102-0102 - Solder handling and disposal policies and procedures training

        .. raw:: latex

          \vspace*{1ex}

        Key topics: Understanding policies and procedures related to handling solder and solder paste, stencil cleaning, and solder disposal.
      - 
        .. raw:: latex

          \includegraphics[align=t,scale=1]{../../images/doc_stamp.pdf}

    * - 2.1.4
      - 0102-0105 - Electro-static discharge controls policies and procedures training

        .. raw:: latex

          \vspace*{1ex}

        Key topics: Understanding policies and procedures related to protecting equipment and components fromm electro-static discharge, including clothing, protective equipment, material handling and labelling.
      - 
        .. raw:: latex

          \includegraphics[align=t,scale=1]{../../images/doc_stamp.pdf}

Required skills training
************************

The following skills training units must be completed before assembling this product.

By signing (or applying your stamp) on the right, you indicate that you have completed the following training:

.. tabularcolumns:: |>{\raggedright\arraybackslash}\Y{0.10}
                    |>{\raggedright\arraybackslash}\Y{0.70}
                    |>{\raggedright\arraybackslash}\Y{0.20}|

.. _tbl_skills_training:

.. list-table:: Skills training
    :class: longtable
    :header-rows: 1
    :align: center 

    * - Item #
      - Description
      - Signature/Stamp
    * - 2.2.1
      - 0103-0202 - ANSI/ESD S20.20 Electro-static discharge controls

        .. raw:: latex

          \vspace*{1ex}

        Key topics: Understanding of ESD safety, the ESD control program, equipment and personnel grounding, EPAs, packaging and marking.
      - 
        .. raw:: latex

          \includegraphics[align=t,scale=1]{../../images/doc_stamp.pdf}

    * - 2.2.2
      - 0103-0203 - General components handling

        .. raw:: latex

          \vspace*{1ex}

        Key topics: Understanding of safe component handling, including reeled components, components in JEDEC trays, and loose components. Includes avoiding contamination, moisture control, and component inventory management.
      - 
        .. raw:: latex

          \includegraphics[align=t,scale=1]{../../images/doc_stamp.pdf}

    * - 2.2.3
      - 0103-0204 - SMD Reel Handling

        .. raw:: latex

          \vspace*{1ex}

        Key topics: Understanding of reel handling, including labeling, component counting, leader management, moisture sensitivity levels, and component inventory management.
      - 
        .. raw:: latex

          \includegraphics[align=t,scale=1]{../../images/doc_stamp.pdf}

    * - 2.2.4
      - 0103-0409 - SMT Caddy manual pick and place machine

        .. raw:: latex

          \vspace*{1ex}

        Key topics: Safe and effective use of the SMT Caddy manual pick-and-place machine, including setup, reel mounting, component dispensing, eurgonomic use, startup, shutdown, board mounting and component placement.
      - 
        .. raw:: latex

          \includegraphics[align=t,scale=1]{../../images/doc_stamp.pdf}

    * - 2.2.5
      - 0103-0414 - 5040-XTS reflow station

        .. raw:: latex

          \vspace*{1ex}

        Key topics: Safe and effective use of the 5040-XTS reflow station, including use of the pre-heater, the hot air system, and the soldering iron. Covers inspection and verification, cleaning, preferred settings and best practice techniques.
      - 
        .. raw:: latex

          \includegraphics[align=t,scale=1]{../../images/doc_stamp.pdf}

    * - 2.2.6
      - 0103-0301 - IPC-A-610G - Acceptability of electronic assemblies

        .. raw:: latex

          \vspace*{1ex}

        Key topics: Covers visual acceptability requirements for electronic assemblies, including handling considerations, hardware installation, component placement, soldering, terminal connections, wiring, marking and cleanliness.
      - 
        .. raw:: latex

          \includegraphics[align=t,scale=1]{../../images/doc_stamp.pdf}

    * - 2.2.7
      - 0103-0302 - IPC-J-STD-001F - Soldered electrical connections

        .. raw:: latex

          \vspace*{1ex}

        Key topics: Covers soldering materials, general soldering and assembly requirements, wire and terminal connections, through-hole mounting, surface mounting of components, cleaning process requirements, PCB requirements, coatings and product assurance.
      - 
        .. raw:: latex

          \includegraphics[align=t,scale=1]{../../images/doc_stamp.pdf}

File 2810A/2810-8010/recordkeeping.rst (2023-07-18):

**************
Record keeping
**************

2810A record keeping
********************

This packaging process takes 1 minutes.

.. tabularcolumns:: |>{\raggedright\arraybackslash}\Y{0.10}
                    |>{\raggedright\arraybackslash}\Y{0.70}
                    |>{\raggedright\arraybackslash}\Y{0.20}|

.. _tbl_2810_record_keeping:

.. list-table:: 2810A record keeping
    :class: longtable
    :header-rows: 1
    :align: center 

    * - Step #
      - Description
      - Signature/Stamp
    * - 8.1.1
      - Write the serial number, the date, and your first and last name in large print on the bottom of the front cover of this document.

        .. raw:: latex

          \vspace*{1ex}

        
           
            Example of serial number on document cover
      - 
        .. raw:: latex

          \includegraphics[align=t,scale=1]{../../images/doc_stamp.pdf}
    * - 8.1.2
      - Create a new folder under the 1510A folder, named with the serial number.
      - 
        .. raw:: latex

          \includegraphics[align=t,scale=1]{../../images/doc_stamp.pdf}
    * - 8.1.3
      - Copy all photos taken during the assebly process into the newly created folder in step #2.
      - 
        .. raw:: latex

          \includegraphics[align=t,scale=1]{../../images/doc_stamp.pdf}
    * - 8.1.4
      - Remove this document from the binding clamps, scan the document, and save the scanned PDF into the newly created folder in step #2, with the name "1510A-SNAAAAAA.pdf", where AAAAAA is replaced with the serial number.
      - 
        .. raw:: latex

          \includegraphics[align=t,scale=1]{../../images/doc_stamp.pdf}
    * - 8.1.5
      - Three-hole punch the document, then file it at the end of the current month's assembly records binder.
      - 
        .. raw:: latex

          \includegraphics[align=t,scale=1]{../../images/doc_stamp.pdf}
    * - 8.1.6
      - Add an entry to the assembly records binder, "<Date> - 2810A - SN# AAAAAA - <Your Name>", where <Date> is replaced with today's date in ISO-8601 YYYY-MM-DD, where AAAAAA is replaced with the serial number of the 2810A, and where <Your Name> is replaced with your first and last name.
      - 
        .. raw:: latex

          \includegraphics[align=t,scale=1]{../../images/doc_stamp.pdf}

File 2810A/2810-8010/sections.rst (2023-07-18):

2810A assembly instructions
===========================

.. toctree::

  overview.rst
  prerequisites.rst
  preparation.rst
  assembly.rst
  test.rst
  packaging.rst
  cleanup.rst
  recordkeeping.rst
  improvement.rst

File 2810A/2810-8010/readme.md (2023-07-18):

# 2810A Assembly Manual

This repository contains the source files used to build document number 2810-8010, the 2810A Assembly manual.

The document is written using reStructuredText, and built using Sphinx (http://www.sphinx-doc.org/en/master/) to generate a PDF via LaTeX.

Build Instructions for Macintosh 10.15
======================================

Installing Sphinx
-----------------

1. Install xcode from the Macintosh App Store
2. From the Mac Terminal, run `xcode-select --install` to install the xcode Command Line Tools
3. From the Mac Finder, run the xcode application to accept the license
4. Download macports from https://www.macports.org/install.php
5. From the Mac Finder, run the macports Installer application
6. From the Mac Terminal, run `sudo port install py36-sphinx` to install sphinx
7. From the Mac Terminal, run `sudo port select --set python python36` to set python 3.6 as default
8. From the Mac Terminal, run `sudo port select --set sphinx py36-sphinx` to set python 3.6 as the default for Sphinx
9. From the Mac Terminal, run `sudo port install py36-sphinxcontrib-bibtex` to install the bibtex bibliography extension to sphinx

The following additional pacakges may be required:

* `sudo port install py36-sphinxcontrib-qthelp`
* `sudo port install py36-sphinxcontrib-serializinghtml`
* `sudo port install py36-sphinxcontrib-htmlhelp`
* `sudo port install py36-sphinxcontrib-jsmath`
* `sudo port install py36-sphinxcontrib-devhelp`
* `sudo port install py36-sphinxcontrib-applehelp`

Installing LaTeX
----------------

9. From the Mac Terminal, run `sudo port install texlive-latex` to install latex
10. From the Mac Terminal, run `sudo port install texlive-xetex` to install xelatex
11. From the Mac Terminal, run `sudo port install latexmk` to install latexmk
12. From the Mac Terminal, run `sudo port install texlive` to install texlive
13. From the Mac Terminal, run `sudo port install texlive-latex-extra` to install texlive extras

Building the Document
---------------------

14. Download the .zip archive of this repository
15. From the Mac Terminal, in the 2810A-master directory, cd into the docs/assembly directory
16. Run `make latexpdf` to build the document
16. Run `open _build/latex/2810-8010.pdf` to open the newly built PDF

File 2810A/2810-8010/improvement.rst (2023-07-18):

*******************
Process improvement
*******************

Feedback
********

Please submit an issue to the `2810A Issue Repository <http://www.github.com/dslik/mix-effect/2810A/>`_ (http://www.github.com/dslik/mix-effect/2810A/) if you encounter any of the below situations:

* Error in this document
* Unclear directions
* Suggested process improvements
* Results of QC failure investigations
* Tool change suggestions

Qualtiy processes and documentation is a team effort. This document would not exist without the participation and contributions of the entire assebly team.

Thank you for reading this assembly instructions document.

End of document.

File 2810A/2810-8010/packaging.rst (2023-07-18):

*********
Packaging
*********

2810A packing
*************

This packaging process takes 3 minutes.

.. tabularcolumns:: |>{\raggedright\arraybackslash}\Y{0.10}
                    |>{\raggedright\arraybackslash}\Y{0.70}
                    |>{\raggedright\arraybackslash}\Y{0.20}|

.. _tbl_2810_packaging:

.. list-table:: 2810A packaging
    :class: longtable
    :header-rows: 1
    :align: center 

    * - Step #
      - Description
      - Signature
    * - 6.1.1
      - Place the 2810A module in the anti-static bag.

        .. raw:: latex

          \vspace*{1ex}

        
           
            2810A in anti-static bag.
      - 
        .. raw:: latex

          \includegraphics[align=t,scale=1]{../../images/doc_stamp.pdf}
    * - 6.1.2
      - Seal the anti-static bag with a 2810A sticker.

        .. raw:: latex

          \vspace*{1ex}

        
           
            2810A in anti-static bag with sticker.
      - 
        .. raw:: latex

          \includegraphics[align=t,scale=1]{../../images/doc_stamp.pdf}
    * - 6.1.3
      - Using the Sharpie pen, Write down the serial number of the 2810A on the sticker, at the end of the line listing the 2810A.

        .. raw:: latex

          \vspace*{1ex}

        
           
            Example photographs of the sealed box
      - 
        .. raw:: latex

          \includegraphics[align=t,scale=1]{../../images/doc_stamp.pdf}
    * - 6.1.4
      - Place 2810A bag in the box on top of the bottom foam padding.

        .. raw:: latex

          \vspace*{1ex}

        
           
            2810A in box.
      - 
        .. raw:: latex

          \includegraphics[align=t,scale=1]{../../images/doc_stamp.pdf}
    * - 6.1.5
      - Take a photograph of the 2810A in the box.
      - 
        .. raw:: latex

          \includegraphics[align=t,scale=1]{../../images/doc_stamp.pdf}
    * - 6.1.6
      - Close the box and Affix a 2810A sticker to the lid of the box.

        .. raw:: latex

          \vspace*{1ex}

        
           
            2810A in box with sticker.
      - 
        .. raw:: latex

          \includegraphics[align=t,scale=1]{../../images/doc_stamp.pdf}
    * - 6.1.7
      - Using the Sharpie pen, Write down the serial number of the 2810A on the sticker, at the end of the line listing the 2810A.

        .. raw:: latex

          \vspace*{1ex}

        
           
            2810A in box with sticker with serial number.
      - 
        .. raw:: latex

          \includegraphics[align=t,scale=1]{../../images/doc_stamp.pdf}
    * - 6.1.8
      - Using the ESD tape, seal the lid of the box.

        .. raw:: latex

          \vspace*{1ex}

        
           
            2810A in box, taped.
      - 
        .. raw:: latex

          \includegraphics[align=t,scale=1]{../../images/doc_stamp.pdf}
    * - 6.1.9
      - Take a photograph of the sealed 2810A box.
      - 
        .. raw:: latex

          \includegraphics[align=t,scale=1]{../../images/doc_stamp.pdf}

FIXME - Add screws and hex key

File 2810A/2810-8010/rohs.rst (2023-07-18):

********************************
Reduction of Hazardous Materials
********************************

Compliance declarations, in BOM order.

.. raw:: latex

          \newpage

MG Chemicals 4900
-----------------

.. tabularcolumns:: |>{\raggedright\arraybackslash}\Y{1}|

.. _tbl_rohs_mgchem_4900:

.. list-table:: MG Chemicals 4900 RoHS Compliance
    :class: longtable
    :header-rows: 1
    :align: center 

    * - Declaration for MG Chemicals 4900 - https://www.mgchemicals.com/downloads/msds/01%20English%20Can-USA%20SDS/sds-4900-4917.pdf
    * - 
        .. _fig_rohs_mgchem_4900:

        

JLC lead-free PCB
-----------------

.. tabularcolumns:: |>{\raggedright\arraybackslash}\Y{1}|

.. _tbl_rohs_jlcpcb:

.. list-table:: JLC PCB RoHS Compliance
    :class: longtable
    :header-rows: 1
    :align: center 

    * - Declaration for JLCPCB lead-free PCBs - https://s3.amazonaws.com/helpscout.net/docs/assets/59f1de7804286313cffbb22c/images/5d4d09562c7d3a036965d6a3/ROHS-Certificate-of-Compliance.jpg
    * - 
        .. _fig_rohs_jlcpcb:

        

Würth 9774100151R
-----------------

.. tabularcolumns:: |>{\raggedright\arraybackslash}\Y{1}|

.. _tbl_rohs_wurth_9774100151R:

.. list-table:: Würth 9774100151R RoHS Compliance
    :class: longtable
    :header-rows: 1
    :align: center 

    * - Declaration for Würth 9774100151R - https://www.we-online.com/web/fr/index.php/show/media/07_electronic_components/download_center_1/reach___rohs/rohs/Certificate_of_Compliance_ROHS_DecaBDE.pdf
    * - 
        .. _fig_rohs_wurth_9774100151R:

        

Molex 0022284200
----------------

.. tabularcolumns:: |>{\raggedright\arraybackslash}\Y{1}|

.. _tbl_rohs_molex_0022284200:

.. list-table:: Molex 0022284200 RoHS Compliance
    :class: longtable
    :header-rows: 1
    :align: center 

    * - Declaration for Molex 0022284200 - https://www.molex.com/datasheets/rohspdf/0022284200_rohs.pdf
    * - 
        .. _fig_rohs_molex_0022284200:

        

Diodes, Inc. 1N4148W-7-F
------------------------

.. tabularcolumns:: |>{\raggedright\arraybackslash}\Y{1}|

.. _tbl_rohs_diodes_1N4148W7F:

.. list-table:: Diodes, Inc. 1N4148W-7-F RoHS Compliance
    :class: longtable
    :header-rows: 1
    :align: center 

    * - Declaration for Diodes, Inc. 1N4148W-7-F - https://www.diodes.com/assets/Quality-Reliability-Docs/Master_CofC.pdf
    * - 
        .. _fig_rohs_diodes_1N4148W7F:

        

Molex 0022284060
----------------

.. tabularcolumns:: |>{\raggedright\arraybackslash}\Y{1}|

.. _tbl_rohs_molex_0022284060:

.. list-table:: Molex 0022284060 RoHS Compliance
    :class: longtable
    :header-rows: 1
    :align: center 

    * - Declaration for Molex 0022284060 - https://www.molex.com/datasheets/rohspdf/0022284060_rohs.pdf
    * - 
        .. _fig_rohs_molex_0022284060:

        

RAF M0503-25-AL
---------------

.. tabularcolumns:: |>{\raggedright\arraybackslash}\Y{1}|

.. _tbl_rohs_raf_m050325al:

.. list-table:: RAF M0503-25-AL RoHS Compliance
    :class: longtable
    :header-rows: 1
    :align: center 

    * - Declaration for RAF M0503-25-AL - https://mwi-production-app-storage.s3.us-east-1.amazonaws.com/MW-Components-RAF-RoHS-Compliant.pdf
    * - 
        .. _fig_rohs_raf_m050325al:



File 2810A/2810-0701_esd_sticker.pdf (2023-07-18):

2810A PACKAGE CONTENTS:; 1x 2810A M/E SOURCE SELECTOR MODULE


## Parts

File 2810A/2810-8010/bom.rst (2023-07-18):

*****************
Bill of materials
*****************

2810-0101A PCBA
---------------

The parts required to assemble a 2810-0101A PCB Assembly are listed in :numref:`tbl_2810-0101_parts`.

.. tabularcolumns:: |>{\raggedright\arraybackslash}\Y{0.15}
                    |>{\raggedright\arraybackslash}\Y{0.06}
                    |>{\raggedright\arraybackslash}\Y{0.23}
                    |>{\raggedright\arraybackslash}\Y{0.15}
                    |>{\raggedright\arraybackslash}\Y{0.22}
                    |>{\raggedright\arraybackslash}\Y{0.10}
                    |>{\raggedright\arraybackslash}\Y{0.09}|

.. _tbl_2810-0101_parts:

.. list-table:: 2810-0101A parts
    :class: longtable
    :header-rows: 1
    :align: center 

    * - Reference Designation
      - Qty
      - Description
      - Manufacturer
      - Manufacturer Part Number
      - Supplier
      - Cost
    * - 2810-0101 v1.1
      - 1
      - Front Panel PCB
      - JLCPCB
      - Y138-2154951A
      - `JLCPCB <https://jlcpcb.com/>`_
      - $3.44 CAD
    * - SN1 - SN4
      - 4
      - Round Standoff Threaded M2.5x0.45 Steel 0.394" (10.00mm)
      - Würth Elektronik
      - 9774100151R
      - `Digikey <https://www.digikey.ca/en/products/detail/würth-elektronik/9774100151R/5320660>`_
      - $5.76 CAD
    * - Total
      - 
      - 
      - 
      - 
      - 
      - $9.20 CAD

2810-0301A PCBA
---------------

The parts required to assemble a 2810-0301A PCB Assembly are listed in :numref:`tbl_2810-0301_parts`.

.. tabularcolumns:: |>{\raggedright\arraybackslash}\Y{0.15}
                    |>{\raggedright\arraybackslash}\Y{0.06}
                    |>{\raggedright\arraybackslash}\Y{0.23}
                    |>{\raggedright\arraybackslash}\Y{0.15}
                    |>{\raggedright\arraybackslash}\Y{0.22}
                    |>{\raggedright\arraybackslash}\Y{0.10}
                    |>{\raggedright\arraybackslash}\Y{0.09}|

.. _tbl_2810-0301_parts:

.. list-table:: 2810-0301A parts
    :class: longtable
    :header-rows: 1
    :align: center 

    * - Reference Designation
      - Qty
      - Description
      - Manufacturer
      - Manufacturer Part Number
      - Supplier
      - Cost
    * - 2810-0201 v1
      - 1
      - Button Spacer PCB
      - JLCPCB
      - Y110-2154951A
      - `JLCPCB <https://jlcpcb.com/>`_
      - $1.40 CAD
    * - 2810-0301 v1
      - 1
      - Button Board PCB
      - JLCPCB
      - Y127-2154951A
      - `JLCPCB <https://jlcpcb.com/>`_
      - $1.39 CAD
    * - CN3
      - 1
      - Connector Header Through Hole 20 position 0.100" (2.54mm)
      - Molex
      - 0022284200
      - `Digikey <https://www.digikey.ca/en/products/detail/molex/0022284200/313805>`_
      - $1.04 CAD
    * - D1-D12
      - 12
      - Diode Standard 100 V 300mA (DC) Surface Mount SOD-123
      - Diodes Incorporated
      - 1N4148W-7-F
      - `Digikey <https://www.digikey.ca/en/products/detail/diodes-incorporated/1N4148W-7-F/814371>`_
      - $3.00 CAD
    * - S1-S12
      - 12
      - SPST RGB LED pushbutton switch
      - Honyone Electrical Co.
      - PB26-13M-B-WT-RGB-N
      - 
      - $59.88 CAD
    * - LB1-LB12
      - 12
      - Transparency sheet with pushbutton Labels
      - Manufactured in-house
      - 
      - 
      - 
    * - Total
      - 
      - 
      - 
      - 
      - 
      - $66.71 CAD

2810-0401A PCBA
---------------

The parts required to assemble a 2810-0401A PCB Assembly are listed in :numref:`tbl_2810-0401_parts`.

.. tabularcolumns:: |>{\raggedright\arraybackslash}\Y{0.15}
                    |>{\raggedright\arraybackslash}\Y{0.06}
                    |>{\raggedright\arraybackslash}\Y{0.23}
                    |>{\raggedright\arraybackslash}\Y{0.15}
                    |>{\raggedright\arraybackslash}\Y{0.22}
                    |>{\raggedright\arraybackslash}\Y{0.10}
                    |>{\raggedright\arraybackslash}\Y{0.09}|

.. _tbl_2810-0401_parts:

.. list-table:: 2810-0401A parts
    :class: longtable
    :header-rows: 1
    :align: center 

    * - Reference Designation
      - Qty
      - Description
      - Manufacturer
      - Manufacturer Part Number
      - Supplier
      - Cost
    * - 2810-0401 v1
      - 1
      - Processor PCB
      - JLCPCB
      - Y126-2154951A
      - `JLCPCB <https://jlcpcb.com/>`_
      - $1.97 CAD
    * - CN1
      - 1
      - 2x8 2.54mm IDC connector (Eurorack power connector)
      - Boom Precision Electronics
      - 0172-A-B07-004
      - `LCSC <https://lcsc.com/product-detail/Header-Connectors_2-54mm-2-8P-Straight-IDC-Box_C3406.html>`_
      - $0.13 CAD
    * - CN2
      - 1
      - Connector Header Through Hole 6 position 0.100" (2.54mm)
      - Molex
      - 0022284060
      - `Digikey <https://www.digikey.ca/en/products/detail/molex/0022284060/313791>`_
      - $0.36 CAD
    * - CN4,CN5
      - 2
      - Connector Header Through Hole 20 position 0.100" (2.54mm)
      - Molex
      - 0022284200
      - `Digikey <https://www.digikey.ca/en/products/detail/molex/0022284200/313805>`_
      - $2.08 CAD
    * - C1,C2
      - 2
      - 22 µF Molded Tantalum Capacitors 25 V 2917 (7343 Metric) 200mOhm
      - Kyocera AVX
      - TPSD226K025R0200
      - `Digikey <https://www.digikey.ca/en/products/detail/kyocera-avx/TPSD226K025R0200/563886>`_
      - $4.84 CAD
    * - FB1
      - 1
      - 500mA 1 300mΩ 600Ω@100MHz ±25% 0805 Ferrite Bead
      - Sunlord
      - GZ2012D601TF
      - `LCSC <https://www.lcsc.com/product-detail/Ferrite-Beads_Sunlord-GZ2012D601TF_C1017.html>`_
      - $0.026 CAD
    * - D1,D2
      - 2
      - Green LED Indication - Discrete 2V 0805 (2012 Metric)
      - Lumex Opto Components Inc.
      - SML-LXT0805GW-TR
      - `Digikey <https://www.digikey.ca/en/products/detail/lumex-opto-components-inc/SML-LXT0805GW-TR/304367>`_
      - $1.14 CAD
    * - D3
      - 1
      - Diode Standard 100 V 300mA (DC) Surface Mount SOD-123
      - Diodes Incorporated
      - 1N4148W-7-F
      - `Digikey <https://www.digikey.ca/en/products/detail/diodes-incorporated/1N4148W-7-F/814371>`_
      - $0.25 CAD
    * - F1
      - 1
      - Polymeric PTC Resettable Fuse 24V 500 mA Ih Surface Mount 1812 (4532 Metric), Concave
      - Littelfuse Inc.
      - MINISMDC050F-2
      - `Digikey <https://www.digikey.ca/en/products/detail/littelfuse-inc/MINISMDC050F-2/1045893>`_
      - $0.54 CAD
    * - R1
      - 1
      - 649 Ohms ±1% 0.1W, 1/10W Chip Resistor 0603 (1608 Metric)
      - Stackpole Electronics Inc
      - RMCF0603FT649R
      - `Digikey <https://www.digikey.ca/en/products/detail/stackpole-electronics-inc/RMCF0603FT649R/1760899>`_
      - $0.15 CAD
    * - R2,R5,R6,R26
      - 4
      - 1 kOhms ±5% 0.1W, 1/10W Chip Resistor 0603 (1608 Metric)
      - TE Connectivity
      - CRGCQ0603J1K0
      - `Digikey <https://www.digikey.ca/en/products/detail/te-connectivity-passive-product/CRGCQ0603J1K0/8576693>`_
      - $0.60 CAD
    * - R3,R4,R10-R13
      - 6
      - 10 kOhms ±1% 0.1W, 1/10W Chip Resistor 0603 (1608 Metric)
      - TE Connectivity
      - CRGCQ0603F10K
      - `Digikey <https://www.digikey.ca/en/products/detail/te-connectivity-passive-product/CRGCQ0603F10K/8576302>`_
      - $0.90 CAD
    * - R7
      - 1
      - 2 kOhms ±1% 0.1W, 1/10W Chip Resistor 0603 (1608 Metric)
      - Stackpole Electronics Inc
      - RMCF0603FT2K00
      - `Digikey <https://www.digikey.ca/en/products/detail/stackpole-electronics-inc/RMCF0603FT2K00/1761334>`_
      - $0.15 CAD
    * - R8
      - 1
      - 4.02 kOhms ±1% 0.1W, 1/10W Chip Resistor 0603 (1608 Metric)
      - Stackpole Electronics Inc
      - RMCF0603FT4K02
      - `Digikey <https://www.digikey.ca/en/products/detail/stackpole-electronics-inc/RMCF0603FT4K02/1761048>`_
      - $0.15 CAD
    * - R9
      - 1
      - 8.06 kOhms ±1% 0.1W, 1/10W Chip Resistor 0603 (1608 Metric)
      - Stackpole Electronics Inc
      - RMCF0603FT8K06
      - `Digikey <https://www.digikey.ca/en/products/detail/stackpole-electronics-inc/RMCF0603FT8K06/1761244>`_
      - $0.15 CAD
    * - R14-R25
      - 12
      - 330 Ohms ±1% 0.1W, 1/10W Chip Resistor 0603 (1608 Metric)
      - TE Connectivity
      - CRGCQ0603F330R
      - `Digikey <https://www.digikey.ca/en/products/detail/te-connectivity-passive-product/CRGCQ0603F330R/8576284>`_
      - $1.80 CAD
    * - Q1-Q3
      - 3
      - Bipolar (BJT) Transistor PNP 40 V 200 mA 250MHz 250 mW Surface Mount SOT-23-3 (TO-236)
      - Motorola
      - MMBT3906LT1 (PMBT3906,215 Substitute)
      - `Digikey <https://www.digikey.ca/en/products/detail/nexperia-usa-inc/PMBT3906215/763516>`_
      - $0.54 CAD
    * - U1
      - 1
      - RP2040 Raspberry Pi Pico series ARM® Cortex®-M0+ MCU 32-Bit Embedded Evaluation Board
      - Raspberry Pi
      - SC0915
      - `Digikey <https://www.digikey.ca/en/products/detail/raspberry-pi/SC0915/13624793>`_
      - $5.53 CAD
    * - U2
      - 1
      - Shunt Voltage Reference IC Fixed 3.0V V ±0.2% 15 mA 
      - Texas Instruments
      - LM4040BIM3-2.5
      - `Digikey <https://www.digikey.ca/en/products/detail/texas-instruments/LM4040BIM3-3-0-NOPB/3527236>`_
      - $2.99 CAD
    * - U3-U5
      - 3
      - 16V Clamp 5A (8/20µs) Ipp Tvs Diode Surface Mount SOT-23-6L
      - YAGEO
      - UDT26A05L05-LC1
      - `Digikey <https://www.digikey.ca/en/products/detail/yageo/UDT26A05L05-LC1/13689608>`_
      - $8.73 CAD
    * - Total
      - 
      - 
      - 
      - 
      - 
      - $33.03 CAD

2810A
-----

The parts required to assemble a 2810A are listed in :numref:`tbl_2810A_parts`.

.. tabularcolumns:: |>{\raggedright\arraybackslash}\Y{0.15}
                    |>{\raggedright\arraybackslash}\Y{0.06}
                    |>{\raggedright\arraybackslash}\Y{0.23}
                    |>{\raggedright\arraybackslash}\Y{0.15}
                    |>{\raggedright\arraybackslash}\Y{0.22}
                    |>{\raggedright\arraybackslash}\Y{0.10}
                    |>{\raggedright\arraybackslash}\Y{0.09}|

.. _tbl_2810A_parts:

.. list-table:: 2810A parts
    :class: longtable
    :header-rows: 1
    :align: center 

    * - Reference Designation
      - Qty
      - Description
      - Manufacturer
      - Manufacturer Part Number
      - Supplier
      - Cost
    * - 2810-0101A
      - 1
      - Front Panel PCBA
      - In-house Assembly
      - 
      - 
      - $9.20 CAD
    * - 2810-0301A
      - 1
      - Button Board PCBA
      - In-house Assembly
      - 
      - 
      - $66.71 CAD
    * - 2810-0401A
      - 1
      - Processor Board PCBA
      - In-house Assembly
      - 
      - 
      - $32.88 CAD
    * - LCD1
      - 1
      - 3.5 Inch LCD Module
      - Waveshare
      - Pico-ResTouch-LCD-3.5
      - `Waveshare <https://www.waveshare.com/pico-restouch-lcd-3.5.htm>`_
      - $19.99 USD
    * - MP1-MP4
      - 4
      - Screw - M2.5 5mm 10.9 Black Alloy Steel Hex Socket Button Head
      - Order By Description
      - 
      - 
      - $0.274 CAD
    * - MP5-MP8
      - 4
      - Screw - M2.5 12mm 10.9 Black Alloy Steel Hex Socket Button Head
      - Order By Description
      - 
      - 
      - $0.274 CAD
    * - SN5-SN8
      - 4
      - Round Spacer Unthreaded Aluminum 0.157" (4.00mm)
      - RAF Electronic Hardware
      - M0503-25-AL
      - `Digikey <https://www.digikey.ca/en/products/detail/raf-electronic-hardware/M0503-25-AL/7681279>`_
      - $2.48 CAD
    * - SK1
      - 1
      - QC Sticker
      - Order by Description
      - 
      - 
      - $0.0094 CAD
    * - Total
      - 
      - 
      - 
      - 
      - 
      - $131.97 CAD

FIXME - Add M3 screws and hex wrench

2810A Packaging
---------------

The parts required to package a 2810 are listed in :numref:`tbl_2810A_packing_parts`.

.. tabularcolumns:: |>{\raggedright\arraybackslash}\Y{0.15}
                    |>{\raggedright\arraybackslash}\Y{0.06}
                    |>{\raggedright\arraybackslash}\Y{0.23}
                    |>{\raggedright\arraybackslash}\Y{0.15}
                    |>{\raggedright\arraybackslash}\Y{0.22}
                    |>{\raggedright\arraybackslash}\Y{0.10}
                    |>{\raggedright\arraybackslash}\Y{0.09}|

.. _tbl_2810A_packing_parts:

.. list-table:: 2810 packing parts
    :class: longtable
    :header-rows: 1
    :align: center 

    * - Reference Designation
      - Qty
      - Description
      - Manufacturer
      - Manufacturer Part Number
      - Supplier
      - Cost
    * - N/A
      - 1
      - Static Shielding Bag 5" X 7"
      - SCS
      - 81757
      - `Digikey <https://www.digikey.ca/en/products/detail/scs/81757/9606831>`_
      - $0.31 CAD
    * - N/A
      - 1
      - Static Shielding Bag 1.5" X 2.8" Ziplock
      - Order by Description
      - 
      - 
      - $0.06 CAD
    * - N/A
      - 1
      - CORREC-PAK SHIPPER 7 X 5 X 1.5" ID
      - Conductive Containers, Inc.
      - 3080-1
      - `Digikey <https://www.digikey.ca/en/products/detail/conductive-containers-inc/3080-1/9922400>`_
      - $8.67 CAD
    * - 1031-7001
      - 2
      - 2810A ESD Sticker
      - Jukebox Print
      - 
      - 
      - $4.00 CAD
    * - Total
      - 
      - 
      - 
      - 
      - 
      - $13.04 CAD

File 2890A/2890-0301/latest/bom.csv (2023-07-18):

ID | Name | Designator | Footprint | Quantity | Manufacturer Part | Manufacturer | Supplier | Supplier Part | Price
1 | LED-SMD_4P-L1.5-W1.5-BL | D31,D16,D17,D18,D19,D20,D21,D22,D23,D24,D25,D26,D27,D28,D29,D30,D15,D14,D13,D12,D11,D10,D9,D8,D7,D6,D5,D4,D3,D2,D1 | LED-SMD_4P-L1.5-W1.5-BL | 31 | SK6805-EC15 | 欧思科光电 | LCSC | C2890035 | 0.182
2 | C0603 | C9 | C0603 | 1 | CL10C101JB8NNNC | SAMSUNG(三星) | LCSC | C14858 | 0.004
3 | HDR-TH_4P-P2.00-V-M | J1 | HDR-TH_4P-P2.00-V-M | 1

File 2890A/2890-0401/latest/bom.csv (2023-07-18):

ID | Name | Designator | Footprint | Quantity | Manufacturer Part | Manufacturer | Supplier | Supplier Part | Price
1 | C0402_NEW | C20,C10,C17,C19,C18,C7,C16,C13,C12,C11,C14,C15 | C0402_NEW | 12 | CL05B104KO5NNNC | SAMSUNG | LCSC | C1525 | 0.001
2 | R0603 | R7,R10,R11,R12,R9,R8 | R0603 | 6 | 0603WAF2001T5E | UNI-ROYAL(厚声) | LCSC | C22975 | 0.001
3 | LED0603-R-RD | D1,D4,D5,D6,D3,D2 | LED0603-R-RD | 6 | 19-217/GHC-YR1S2/3T | EVERLIGHT(亿光) | LCSC | C72043 | 0.027
4 | R0603 | R1,R2,R3,R4,R5,R6 | R0603 | 6 | 0603WAF5100T5E | UNI-ROYAL(厚声) | LCSC | C23193 | 0.001
5 | C0603 | C3,C2,C6,C5,C4,C1 | C0603 | 6 | CL10C101JB8NNNC | SAMSUNG(三星) | LCSC | C14858 | 0.004
6 | C0402 | C9,C8 | C0402 | 2 | CL05A225MQ5NSNC | SAMSUNG(三星) | LCSC | C12530 | 0.003
7 | CRYSTAL-SMD_4P-L3.2-W2.5-BL | X1 | CRYSTAL-SMD_4P-L3.2-W2.5-BL | 1 | CO32H4-12.000-WPJHPSN | HCI(杭晶) | LCSC | C2848216 | 0.539
8 | LQFN-56_L7.0-W7.0-P0.4-EP | U7 | LQFN-56_L7.0-W7.0-P0.4-EP | 1 | RP2040 | Raspberry Pi(树莓派) | LCSC | C2040 | 1.05
9 | USON-8_L3.0-W2.0-P0.50-BL-EP | U8 | USON-8_L3.0-W2.0-P0.50-BL-EP | 1 | W25Q16JVUXIQ | WINBOND(华邦) | LCSC | C2843335 | 0.652
10 | LED-SMD_4P-L1.5-W1.5-BL | D7 | LED-SMD_4P-L1.5-W1.5-BL | 1 | SK6805-EC15 | 欧思科光电 | LCSC | C2890035 | 0.182
11 | CONN-SMD_SM03B-SRSS-TB-LF-SN-P | J6,J7 | CONN-SMD_SM03B-SRSS-TB-LF-SN-P | 2 | SM03B-SRSS-TB(LF)(SN) | JST | LCSC | C160403 | 0.137

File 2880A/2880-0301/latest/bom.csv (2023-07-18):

ID | Name | Designator | Footprint | Quantity | Manufacturer Part | Manufacturer | Supplier | Supplier Part | Price
1 | LED-SMD_4P-L1.5-W1.5-BL | D1,D2,D3,D4,D5,D6,D7,D8,D9,D10,D11,D12,D13,D14,D15,D30,D29,D28,D27,D26,D25,D24,D23,D22,D21,D20,D19,D18,D17,D16,D46,D47,D48,D49,D50,D51,D52,D53,D54,D55,D56,D57,D58,D59,D60,D45,D44,D43,D42,D41,D40,D39,D38,D37,D36,D35,D34,D33,D32,D31,D61,D62,D63,D64,D65,D66,D67,D68,D69,D70,D71,D72,D73,D74,D75,D90,D89,D88,D87,D86,D85,D84,D83,D82,D81,D80,D79,D78,D77,D76 | LED-SMD_4P-L1.5-W1.5-BL | 90 | SK6805-EC15 | 欧思科光电 | LCSC | C2890035 | 0.182
2 | HDR-TH_4P-P2.00-V-M | J1,J2 | HDR-TH_4P-P2.00-V-M | 2 | DZ200R-11-04-39 | DEALON(德艺隆) | LCSC | C2935903 | 0.019

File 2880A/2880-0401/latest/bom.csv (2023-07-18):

ID | Name | Designator | Footprint | Quantity | Manufacturer Part | Manufacturer | Supplier | Supplier Part | Price
1 | CAP-SMD_L7.3-W4.3-R-RD | C21 | CAP-SMD_L7.3-W4.3-R-RD | 1 | TPSD226K025R0200 | Kyocera AVX | LCSC | C284839 | 0.546
2 | LED0603-R-RD | D1 | LED0603-R-RD | 1 | 19-217/GHC-YR1S2/3T | EVERLIGHT(亿光) | LCSC | C72043 | 0.027
3 | R0603 | R19 | R0603 | 1 | 0603WAF1501T5E | UNI-ROYAL(厚声) | LCSC | C22843 | 0.001
4 | R0603 | R17,R18 | R0603 | 2 | 0603WAF1002T5E | UNI-ROYAL(厚声) | LCSC | C25804 | 0.001
5 | SOIC-28_L17.9-W7.5-P1.27-LS10.3-BL | U1 | SOIC-28_L17.9-W7.5-P1.27-LS10.3-BL | 1 | MCP23017T-E/SO | MICROCHIP(美国微芯) | LCSC | C629440 | 2.32
6 | R0603 | R2,R1,R3,R4,R6,R5,R8,R7 | R0603 | 8 | 0603WAF1001T5E | UNI-ROYAL(厚声) | LCSC | C21190 | 0.001
7 | C0603 | C1 | C0603 | 1 | CL10C101JB8NNNC | SAMSUNG(三星) | LCSC | C14858 | 0.004
8 | SOT-23-6_L2.9-W1.6-P0.95-LS2.8-BL | U3,U4 | SOT-23-6_L2.9-W1.6-P0.95-LS2.8-BL | 2 | USBLC6-2SC6 | ST(意法半导体) | LCSC | C7519 | 0.118

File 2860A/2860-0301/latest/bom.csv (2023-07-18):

ID | Name | Designator | Footprint | Quantity | Manufacturer Part | Manufacturer | Supplier | Supplier Part | Price
1 | C0402 | C2,C3,C4,C5,C6,C7,C8,C9,C10,C11,C12,C13,C14,C15,C16,C17,C18,C19,C20,C21,C22,C23,C24,C25,C26,C27,C1 | C0402 | 27 | CL05B104KO5NNNC | SAMSUNG(三星) | LCSC | C1525 | 0.001
2 | A | D3,D4,D5,D6,D7,D8,D9,D10,D11,D12,D13,D14,D15,D16,D17,D18,D19,D20,D21,D22,D23,D24,D25,D26,D27,D28,D1,D2 | LED-SMD_4P-L1.5-W1.5-BL | 28 | SK6805-EC15 | 欧思科光电 | LCSC | C2890035 | 0.182
3 | HDR-TH_4P-P2.00-V-M | J1 | HDR-TH_4P-P2.00-V-M | 1 | DZ200R-11-04-39 | DEALON(德艺隆) | LCSC | C2935903 | 0.019

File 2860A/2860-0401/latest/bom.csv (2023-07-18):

ID | Name | Designator | Footprint | Quantity | Manufacturer Part | Manufacturer | Supplier | Supplier Part | Price
1 | SOIC-14_L8.7-W3.9-P1.27-LS6.0-BL | U1 | SOIC-14_L8.7-W3.9-P1.27-LS6.0-BL | 1 | 74HC14D,653 | Nexperia(安世) | LCSC | C5605 | 0.136
2 | SOD-123_L2.8-W1.8-LS3.7-RD | D2,D1 | SOD-123_L2.8-W1.8-LS3.7-RD | 2 | 1N4148W-7-F | DIODES | LCSC | C83528 | 0.01
3 | R0603 | R1,R3,R2 | R0603 | 3 | 0603WAF1001T5E | UNI-ROYAL(厚声) | LCSC | C21190 | 0.001

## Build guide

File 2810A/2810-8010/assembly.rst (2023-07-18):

********
Assembly
********

2810-0101 sub-assembly
**********************

This assembly step takes 15 minutes.

.. tabularcolumns:: |>{\raggedright\arraybackslash}\Y{0.10}
                    |>{\raggedright\arraybackslash}\Y{0.70}
                    |>{\raggedright\arraybackslash}\Y{0.20}|

.. _tbl_2810-0101_assembly:

.. list-table:: 2810-0101 assembly steps
    :class: longtable
    :header-rows: 1
    :align: center 

    * - Step #
      - Description
      - Signature/Stamp
    * - 4.1.1
      - Mount the 2810-0101 PCB rear-side up on the 5040-XTS pre-heater.

        .. raw:: latex

          \vspace*{1ex}

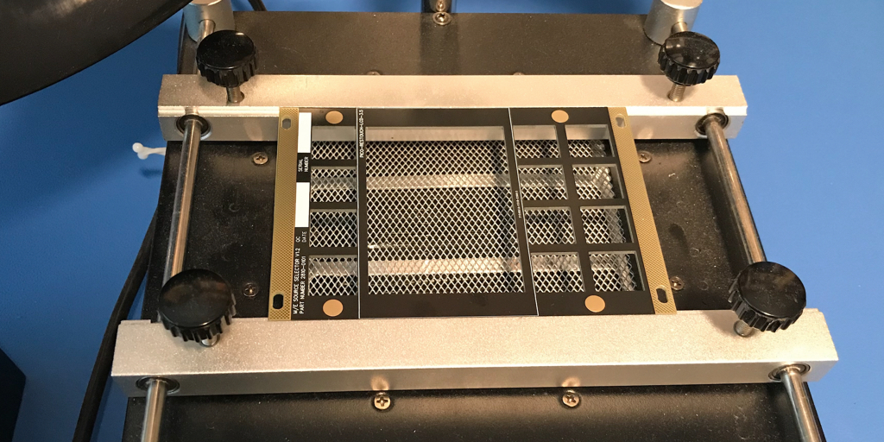
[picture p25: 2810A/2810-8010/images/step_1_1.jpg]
        
           
            2810-0101 PCB mounted on 5040-XTS pre-heater
      - 
        .. raw:: latex

          \includegraphics[align=t,scale=1]{../../images/doc_stamp.pdf}
    * - 4.1.2
      - Dispense one squeeze of solder paste onto the centre of each of the four front panel attachment pads.

        .. raw:: latex

          \vspace*{1ex}

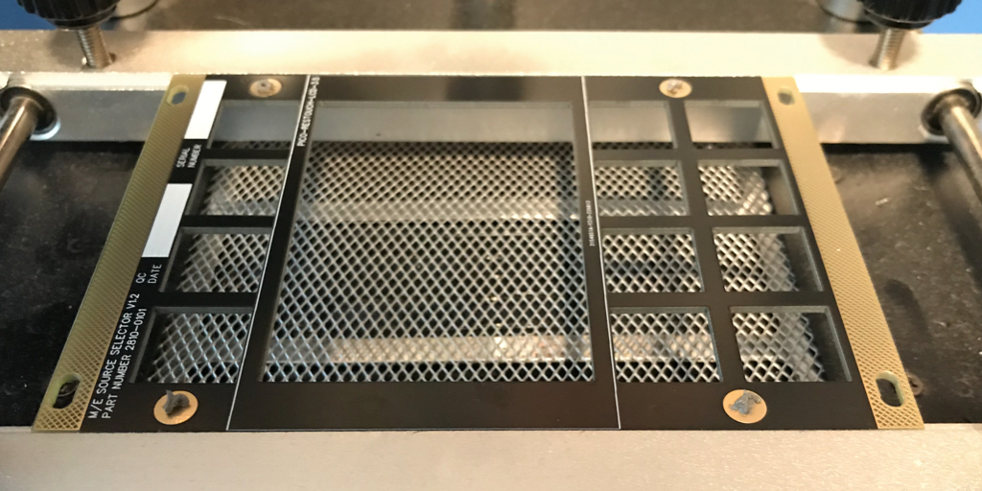
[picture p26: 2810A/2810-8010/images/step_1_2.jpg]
        
           
            Front Panel attachment pads with solder paste
      - 
        .. raw:: latex

          \includegraphics[align=t,scale=1]{../../images/doc_stamp.pdf}
    * - 4.1.3
      - Using the 5mm screws, attach all four 10mm standoffs to the 2810-0111 v0.1 fixture

        .. raw:: latex

          \vspace*{1ex}

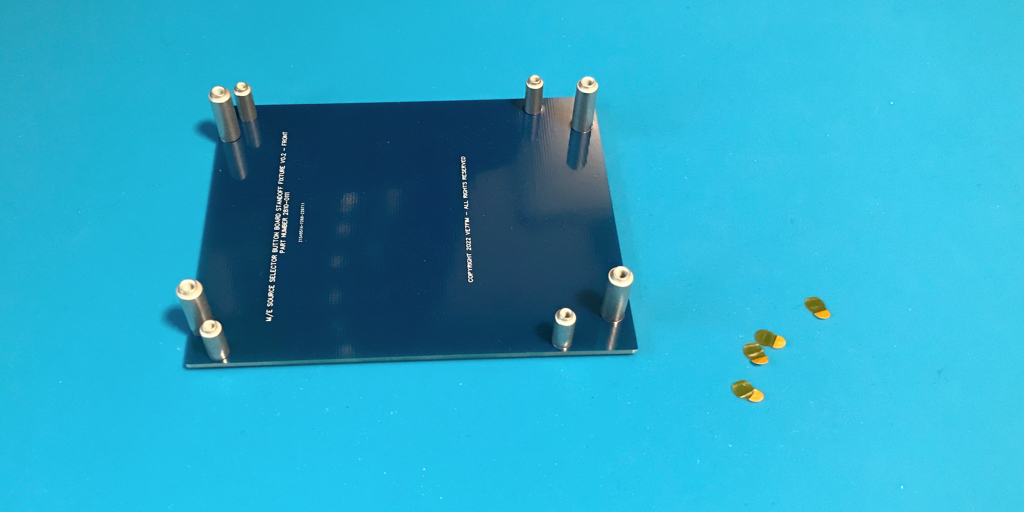
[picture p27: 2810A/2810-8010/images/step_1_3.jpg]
        
           
            2810-0111 v0.1 fixture with standoffs attached
      - 
        .. raw:: latex

          \includegraphics[align=t,scale=1]{../../images/doc_stamp.pdf}
    * - 4.1.4
      - Gently lower fixture on to 2810-0101 PCB, making sure there is no side-to-side motion.

        .. raw:: latex

          \vspace*{1ex}

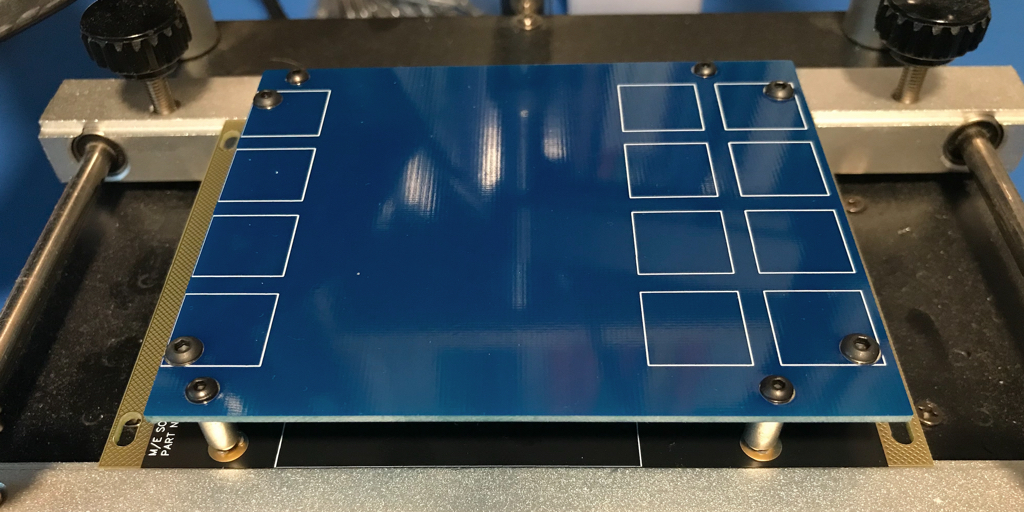
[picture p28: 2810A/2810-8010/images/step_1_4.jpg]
        
           
            2810-0111 v0.1 fixture being lowered
      - 
        .. raw:: latex

          \includegraphics[align=t,scale=1]{../../images/doc_stamp.pdf}
    * - 4.1.5
      - Place the fixture weight on top of the fixture.

        .. raw:: latex

          \vspace*{1ex}

        
           
            2810-0111 v0.1 fixture being lowered
      - 
        .. raw:: latex

          \includegraphics[align=t,scale=1]{../../images/doc_stamp.pdf}
    * - 4.1.6
      - Turn on the pre-heater to 240 degrees C, and heat for 10 minutes using the countdown timer. It will take 5 minutes for the set temperature to be reached.

        .. raw:: latex

          \vspace*{1ex}

        Once the timer finishes, turn the pre-heater off, and allow to cool for 5 minutes using the countdown timer.

        .. raw:: latex

          \vspace*{1ex}

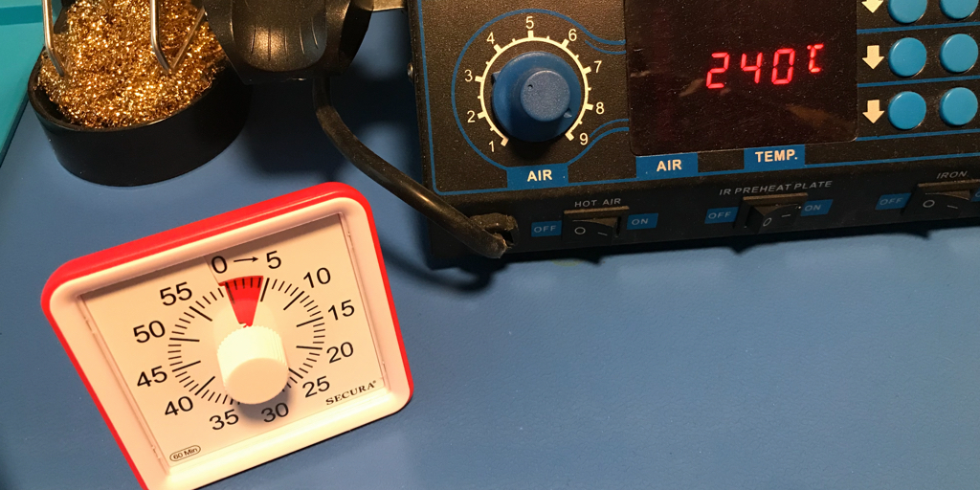
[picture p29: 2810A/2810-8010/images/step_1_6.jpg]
        
           
            2810-0101 on heater
      - 
        .. raw:: latex

          \includegraphics[align=t,scale=1]{../../images/doc_stamp.pdf}
    * - 4.1.7
      - Remove the fixture weight, then remove the 2810-0101 PCB from the 5040 using tweezers, and place it on the assembly mat. Unscrew the fixture from the four 10m standoffs.

        .. raw:: latex

          \vspace*{1ex}

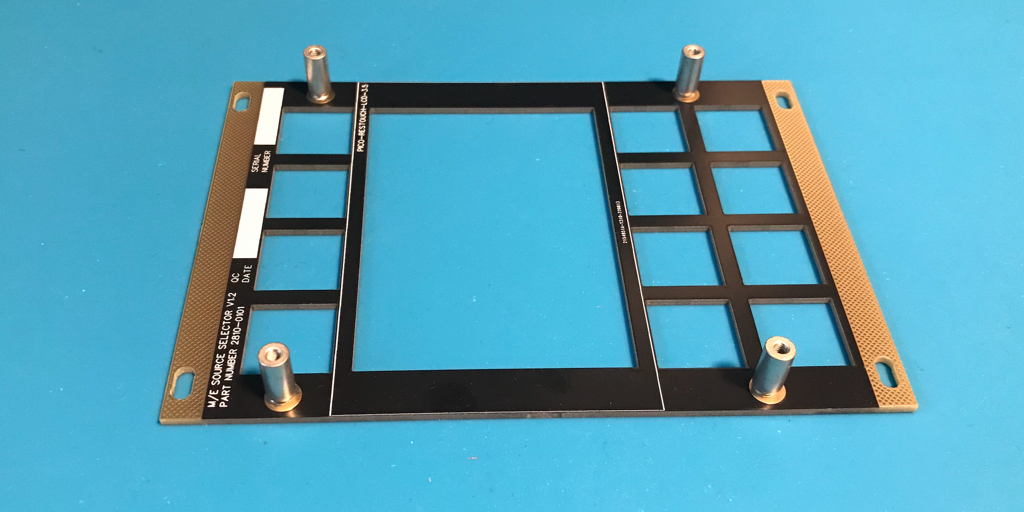
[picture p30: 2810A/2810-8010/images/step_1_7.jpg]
        
           
            Completed 2810-0101 assembly
      - 
        .. raw:: latex

          \includegraphics[align=t,scale=1]{../../images/doc_stamp.pdf}

.. raw:: latex

          \newpage

2810-0301 sub-assembly
**********************

This assembly step takes 15 minutes.

.. tabularcolumns:: |>{\raggedright\arraybackslash}\Y{0.10}
                    |>{\raggedright\arraybackslash}\Y{0.70}
                    |>{\raggedright\arraybackslash}\Y{0.20}|

.. _tbl_2810-0301_assembly:

.. list-table:: 2810-0301 assembly steps
    :class: longtable
    :header-rows: 1
    :align: center 

    * - Step #
      - Description
      - Signature/Stamp
    * - 4.2.1
      - Cut out the 2810A button labels using the button label cutter.

        .. raw:: latex

          \vspace*{1ex}

        
           
            Cut out button labels
      - 
        .. raw:: latex

          \includegraphics[align=t,scale=1]{../../images/doc_stamp.pdf}
    * - 4.2.2
      - Gently pop off the lid of the buttons using the 1mm flat-head screwdriver.

        .. raw:: latex

          \vspace*{1ex}

        
           
            Process of removing button lid
      - 
        .. raw:: latex

          \includegraphics[align=t,scale=1]{../../images/doc_stamp.pdf}
    * - 4.2.3
      - Place cut labels in button lid.

        .. raw:: latex

          \vspace*{1ex}

        
           
            Button lid with label
      - 
        .. raw:: latex

          \includegraphics[align=t,scale=1]{../../images/doc_stamp.pdf}
    * - 4.2.4
      - Snap button on to lid. Be careful to ensure correct alignment — Bottom of text is on the side with the three gold connectors.

        .. raw:: latex

          \vspace*{1ex}

        
           
            Button with label
      - 
        .. raw:: latex

          \includegraphics[align=t,scale=1]{../../images/doc_stamp.pdf}
    * - 4.2.5
      - Solder the 12 diodes onto the 2810-0301 PCB.

        .. raw:: latex

          \vspace*{1ex}

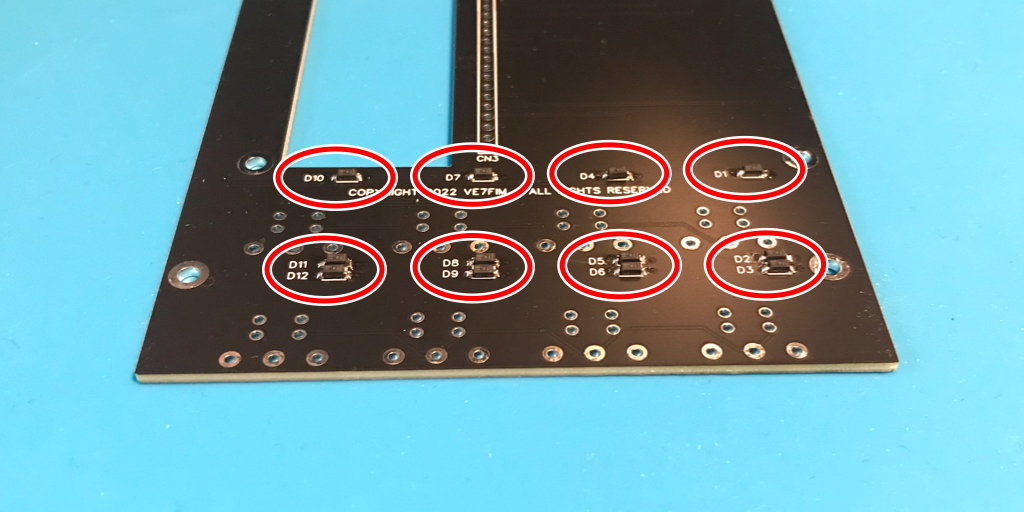
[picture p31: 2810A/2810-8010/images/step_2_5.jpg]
        
           
            2810-0301 PCB with diodes
      - 
        .. raw:: latex

          \includegraphics[align=t,scale=1]{../../images/doc_stamp.pdf}
    * - 4.2.6
      - Solder the 20 pin connector onto the 2810-0301 PCB.

        .. raw:: latex

          \vspace*{1ex}

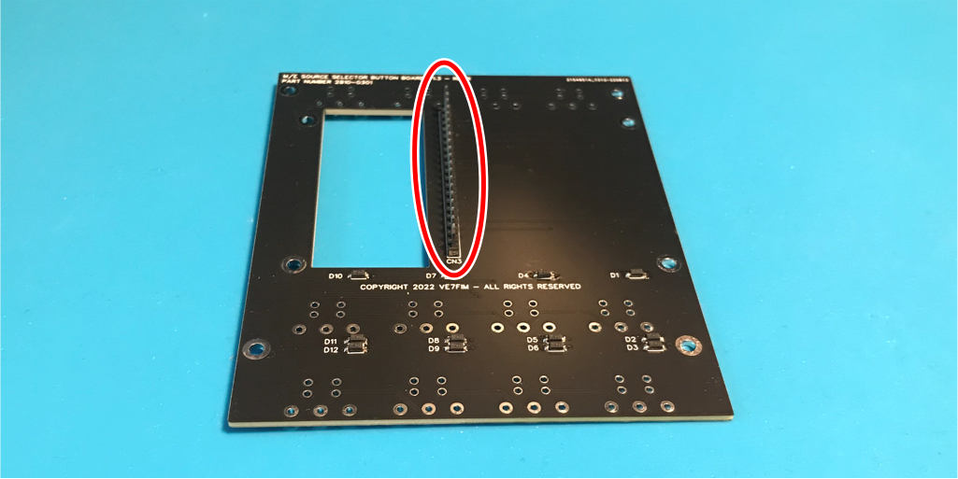
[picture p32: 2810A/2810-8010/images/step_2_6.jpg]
        
           
            2810-0301 PCB with 20 pin connector
      - 
        .. raw:: latex

          \includegraphics[align=t,scale=1]{../../images/doc_stamp.pdf}
    * - 4.2.7
      - Place the 2810-0201 PCB on top of the 2810-0301 PCB.

        .. raw:: latex

          \vspace*{1ex}

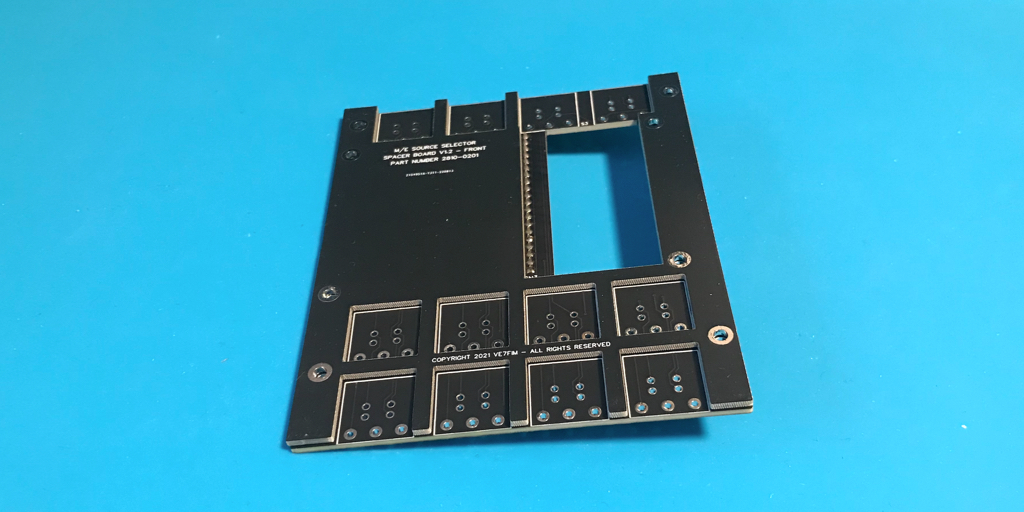
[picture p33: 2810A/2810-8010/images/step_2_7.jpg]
        
           
            2810-0301 PCB with 2810-0201 PCB
      - 
        .. raw:: latex

          \includegraphics[align=t,scale=1]{../../images/doc_stamp.pdf}
    * - 4.2.8
      - Gently insert the 12 RGB buttons onto the 2810-0301 PCB through the holes in the 2810-0201 PCB. If custom labels are to be used, Make sure that the buttons with labels are oriented and placed correctly.

        .. raw:: latex

          \vspace*{1ex}

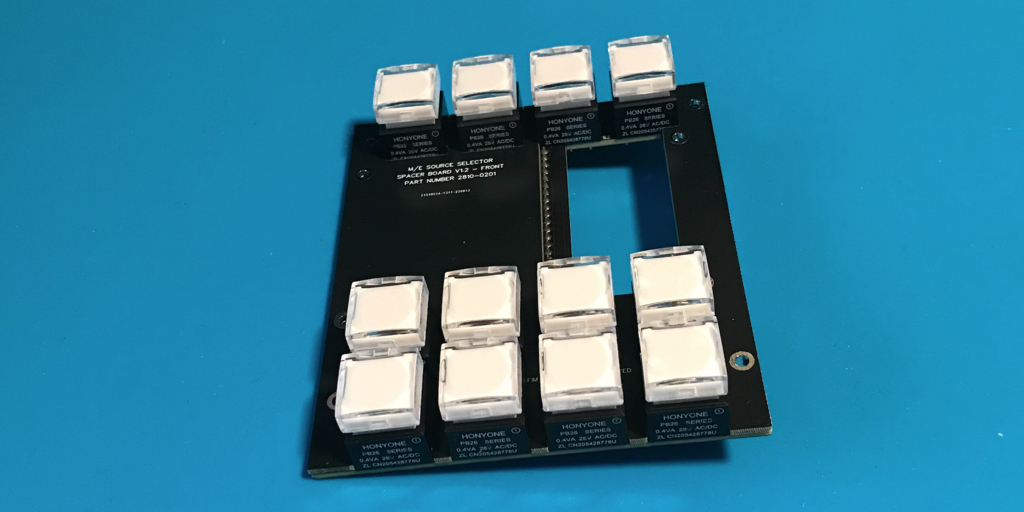
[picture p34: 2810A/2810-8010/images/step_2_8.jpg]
        
           
            2810-0301 PCB with buttons
      - 
        .. raw:: latex

          \includegraphics[align=t,scale=1]{../../images/doc_stamp.pdf}
    * - 4.2.9
      - Flip the PCB over, and solder the 12 buttons. Make sure that all of the buttons are fully inserted by pressing down on the board before starting to solder. Place the completed assembly beside the assembly mat.

        .. raw:: latex

          \vspace*{1ex}

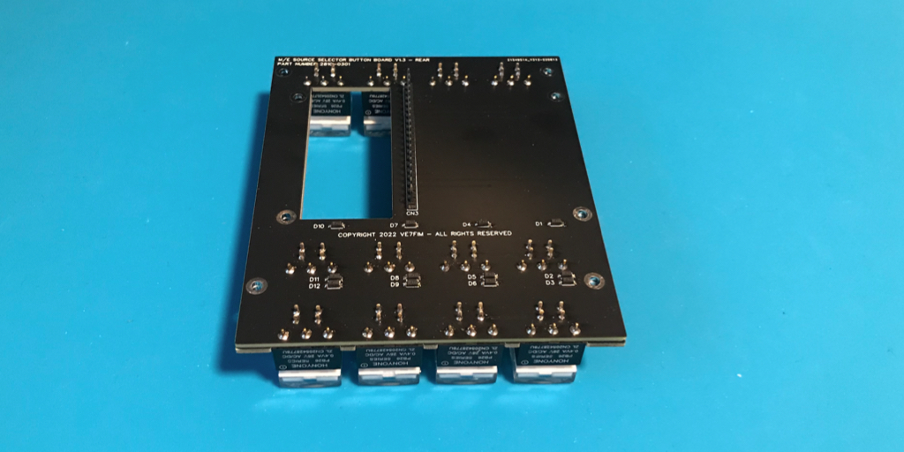
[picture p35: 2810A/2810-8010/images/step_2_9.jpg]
        
           
            Completed 2810-0301 assembly
      - 
        .. raw:: latex

          \includegraphics[align=t,scale=1]{../../images/doc_stamp.pdf}

.. raw:: latex

          \newpage

2810-0401 sub-assembly
**********************

This assembly step takes 45 minutes.

.. tabularcolumns:: |>{\raggedright\arraybackslash}\Y{0.10}
                    |>{\raggedright\arraybackslash}\Y{0.70}
                    |>{\raggedright\arraybackslash}\Y{0.20}|

.. _tbl_2810-0401_assembly:

.. list-table:: 2810-0401 assembly steps
    :class: longtable
    :header-rows: 1
    :align: center 

    * - Step #
      - Description
      - Signature/Stamp
    * - 4.3.1
      - Bring the 2810-0401 PCB, the solder paste dispenser, the parts tray, and a pair of tweezers over to the stencil workstation.

        .. raw:: latex

          \vspace*{1ex}

        
           
            Stencil workstation
      - 
        .. raw:: latex

          \includegraphics[align=t,scale=1]{../../images/doc_stamp.pdf}
    * - 4.3.2
      - Pull the 2810-0401 v1.2 Stencil from the stencil library.

        .. raw:: latex

          \vspace*{1ex}

        
           
            2810-0401 v1 stencil
      - 
        .. raw:: latex

          \includegraphics[align=t,scale=1]{../../images/doc_stamp.pdf}
    * - 4.3.3
      - Mount the stencil on the stencil machine

        .. raw:: latex

          \vspace*{1ex}

        
           
            Mounted stencil
      - 
        .. raw:: latex

          \includegraphics[align=t,scale=1]{../../images/doc_stamp.pdf}
    * - 4.3.4
      - Mount the 2810-0401 PCB rear-side up on the stencil machine.

        .. raw:: latex

          \vspace*{1ex}

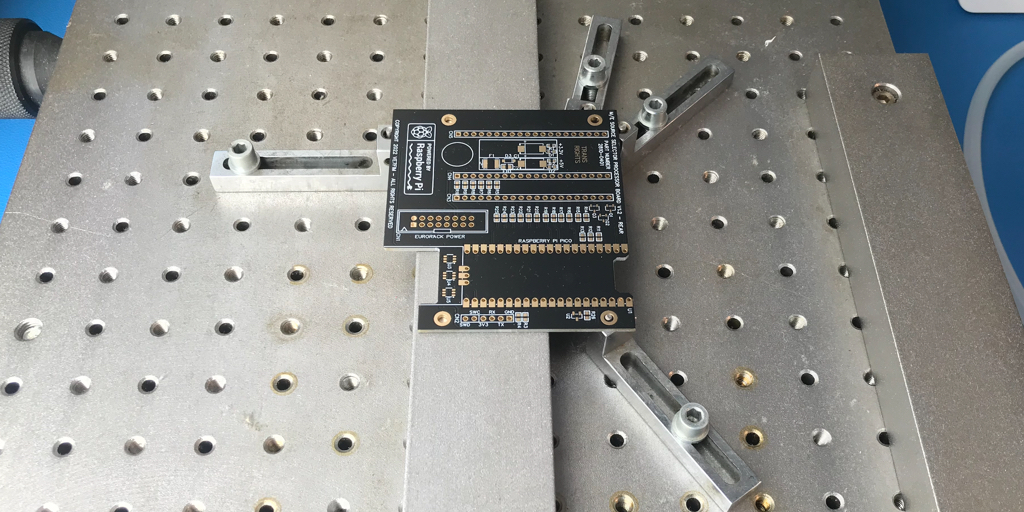
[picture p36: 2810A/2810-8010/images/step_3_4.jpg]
        
           
            2810-0401 PCB mounted on stencil machine 
      - 
        .. raw:: latex

          \includegraphics[align=t,scale=1]{../../images/doc_stamp.pdf}
    * - 4.3.5
      - Align it with the stencil with the PCB.

        .. raw:: latex

          \vspace*{1ex}

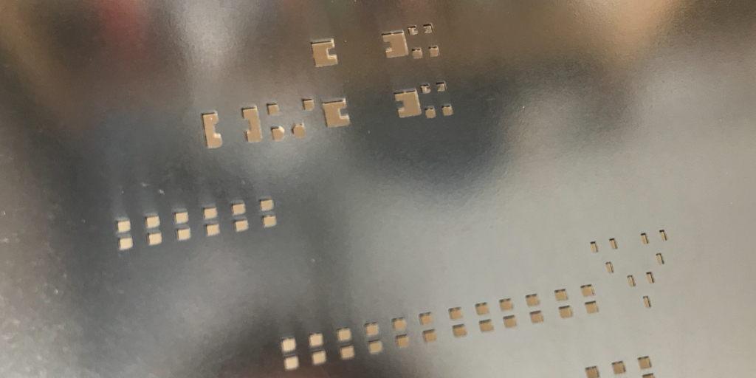
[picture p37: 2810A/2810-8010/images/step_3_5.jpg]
        
           
            2810-0401 PCB pads aligned with stencil openings
      - 
        .. raw:: latex

          \includegraphics[align=t,scale=1]{../../images/doc_stamp.pdf}
    * - 4.3.6
      - Apply 20 squeezes of solder paste in a line at the bottom of the stencil.

        .. raw:: latex

          \vspace*{1ex}

        
           
            Solder paste on the stencil
      - 
        .. raw:: latex

          \includegraphics[align=t,scale=1]{../../images/doc_stamp.pdf}
    * - 4.3.7
      - Using the appropriately sized solder paste squeegee, align at a 45-degree angle below the line of solder paste, and drag upwards while applying moderate downwards force. Inspect for voids in stencil openings before lifting the stencil.

        .. raw:: latex

          \vspace*{1ex}

        
           
            2810-0301 PCB after solder application
      - 
        .. raw:: latex

          \includegraphics[align=t,scale=1]{../../images/doc_stamp.pdf}
    * - 4.3.8
      - Lift the stencil, remove the 2810-0401 PCB, and bring it over to the manual pick-and-place machine. Mount the board on the work surface using the magnetic board edge holders. Be careful to not drop or jar the board, or cause anyting to come into contact with the solder paste.

        .. raw:: latex

          \vspace*{1ex}

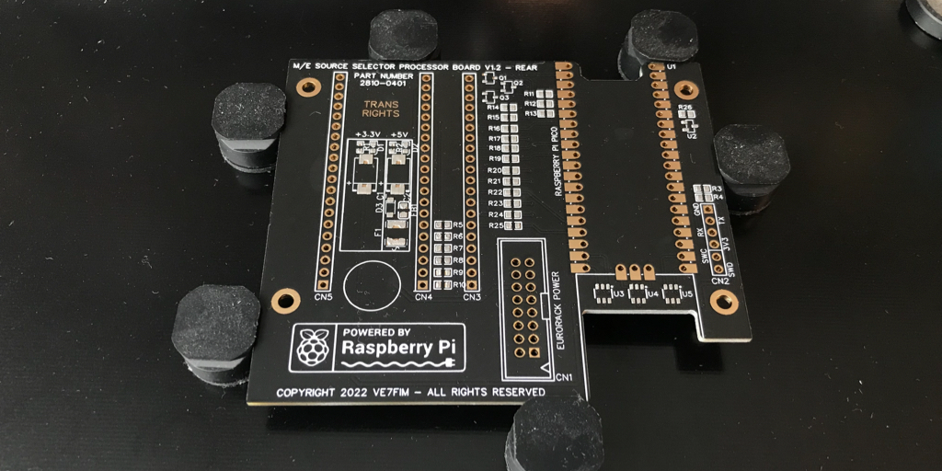
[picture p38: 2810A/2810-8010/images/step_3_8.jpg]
        
           
            2810-0401 PCB mounted in the manual pick-and-place machine
      - 
        .. raw:: latex

          \includegraphics[align=t,scale=1]{../../images/doc_stamp.pdf}
    * - 4.3.9
      - Inspect all of the pads using the manual pick-and-place machine microscope to verify corrrect solder paste application. Verify that the solder paste is aligned with the pads, and that the edges of the paste are well-defined and has not slumped.

        .. raw:: latex

          \vspace*{1ex}

        If the solder paste application fails visual inspection, wipe down the board with IPA and go back to step 4.3.4. If there isn't enough solder paste, use more paste in step 4.3.6. If the paste slumps or runs, get a new syringe of solder paste. If problems continue, contact a supervisor for assistance.

        .. raw:: latex

          \vspace*{1ex}

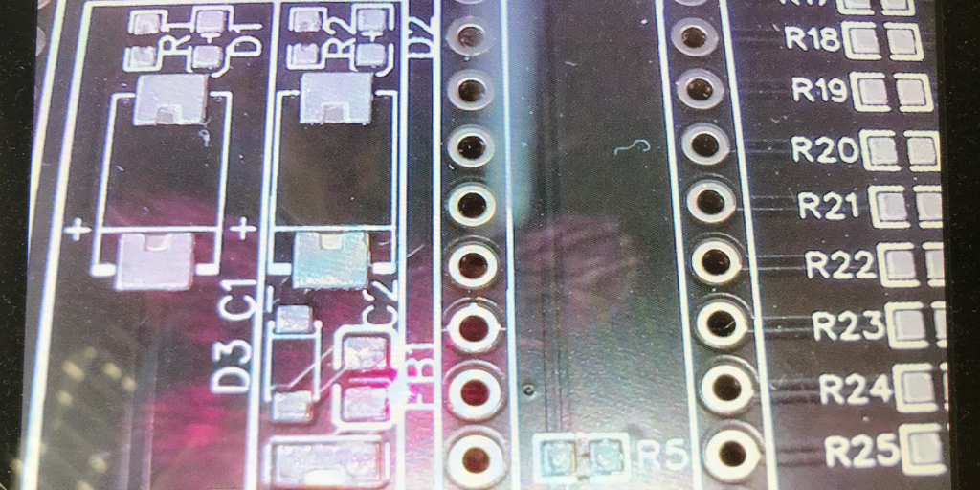
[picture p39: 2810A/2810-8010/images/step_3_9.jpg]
        
           
            Visual inspect of solder paste
      - 
        .. raw:: latex

          \includegraphics[align=t,scale=1]{../../images/doc_stamp.pdf}
    * - 4.3.10
      - Detach the stencil from the stencil machine, and put it on the "to clean" cart.

        .. raw:: latex

          \vspace*{1ex}

        
           
            Stencil on cart
      - 
        .. raw:: latex

          \includegraphics[align=t,scale=1]{../../images/doc_stamp.pdf}
    * - 4.3.11
      - Log in to the computer and pull up the 2810-0401 Interactive BoM

        .. raw:: latex

          \vspace*{1ex}

        
           
            Interactive BoM on workstation
      - 
        .. raw:: latex

          \includegraphics[align=t,scale=1]{../../images/doc_stamp.pdf}
    * - 4.3.12
      - For each surface mount component in the BoM, remove the parts from the tape onto the pick-and-place component tray and place them in the corresponidng locations on the PCB.

        .. raw:: latex

          \vspace*{1ex}

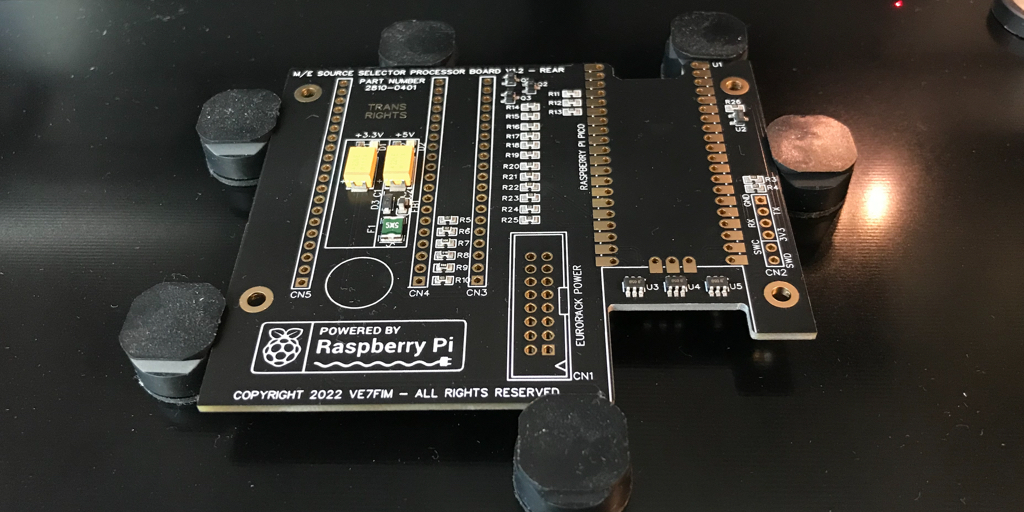
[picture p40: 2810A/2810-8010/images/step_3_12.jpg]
        
           
            2810-0401 with all components mounted
      - 
        .. raw:: latex

          \includegraphics[align=t,scale=1]{../../images/doc_stamp.pdf}
    * - 4.3.13
      - Take the 2810-0401 PCB with all SMT components mounted back to the assembly workstation (along with the parts tray and tweezers). Mount the 2810-0401 PCB rear-side up on the 5040-XTS pre-heater.

        .. raw:: latex

          \vspace*{1ex}

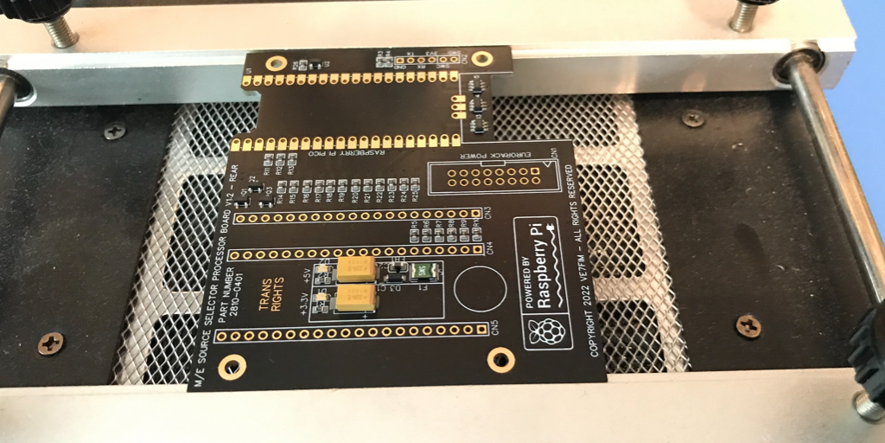
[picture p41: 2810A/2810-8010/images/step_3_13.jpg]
        
           
            2810-0401 PCB mounted on 5040-XTS pre-heater
      - 
        .. raw:: latex

          \includegraphics[align=t,scale=1]{../../images/doc_stamp.pdf}
    * - 4.3.14
      - Turn on the pre-heater to 240 degrees C, and heat for 10 minutes using the countdown timer. It will take 5 minutes for the set temperature to be reached.

        .. raw:: latex

          \vspace*{1ex}

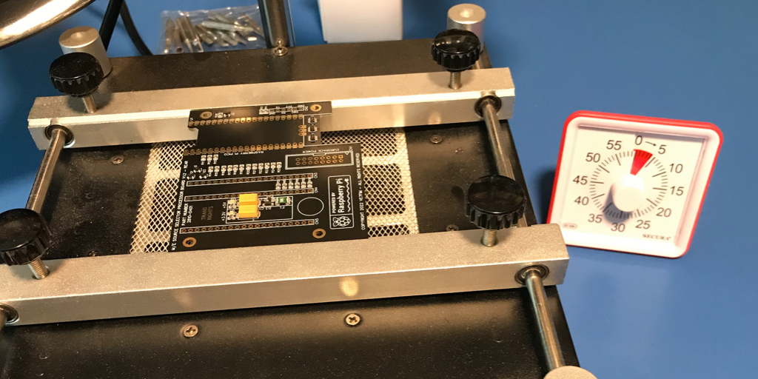
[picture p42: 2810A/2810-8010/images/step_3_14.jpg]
        
           
            2810-0401 on heater
      - 
        .. raw:: latex

          \includegraphics[align=t,scale=1]{../../images/doc_stamp.pdf}
    * - 4.3.15
      - Once the timer finishes, turn on the hot air at 300 degrees C and velocity 2.5. Holding the nozzel two inches from the board, and keeping the airflow perpendicular to the board, melt all of the solder joints. Once complete, turn off the hot air and the pre-heater, and set the timer for 5 minutes to allow the board to cool down.

        .. raw:: latex

          \vspace*{1ex}

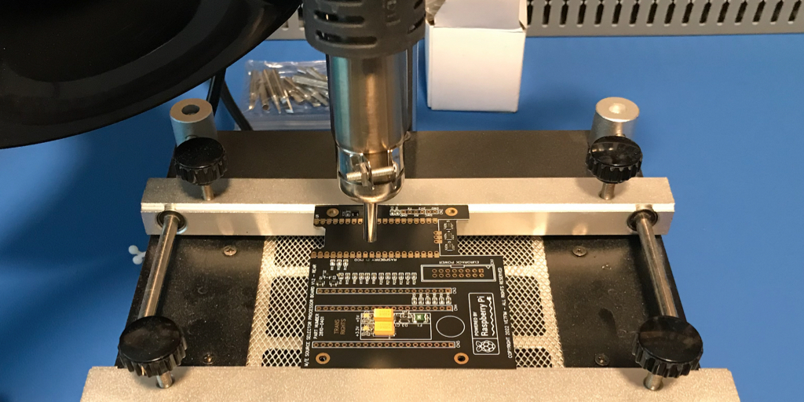
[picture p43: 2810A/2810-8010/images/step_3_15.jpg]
        
           
            Hot air application to SMT components
      - 
        .. raw:: latex

          \includegraphics[align=t,scale=1]{../../images/doc_stamp.pdf}
    * - 4.3.16
      - Once the timer finishes, remove 2810-0401 PCB with tweezers, and place beside the assembly mat. Inspect for good solder joints for complete wetting. Re-work components as required.

        .. raw:: latex

          \vspace*{1ex}

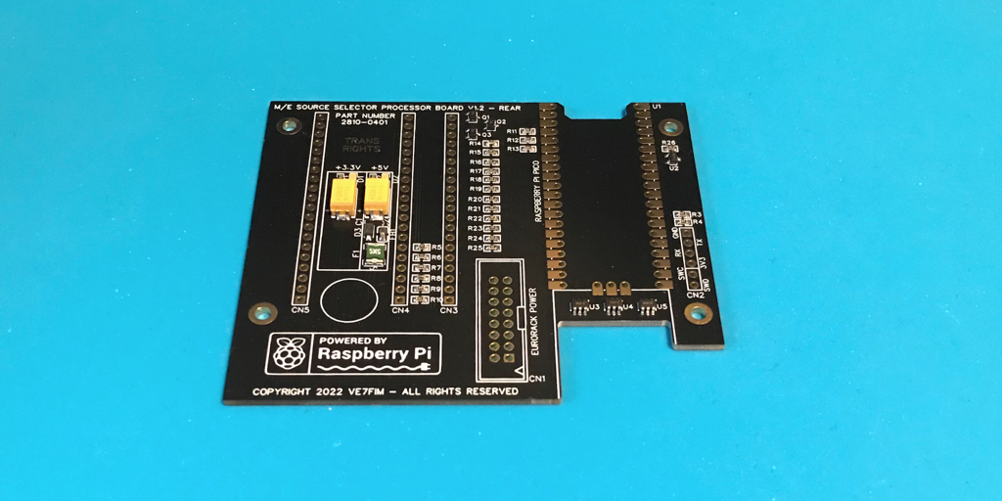
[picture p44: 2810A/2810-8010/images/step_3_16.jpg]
        
           
            2810-0401 PCB with soldered SMT components
      - 
        .. raw:: latex

          \includegraphics[align=t,scale=1]{../../images/doc_stamp.pdf}
    * - 4.3.17
      - Using the 6 pin header, place and align the Pi Pico module.

        .. raw:: latex

          \vspace*{1ex}

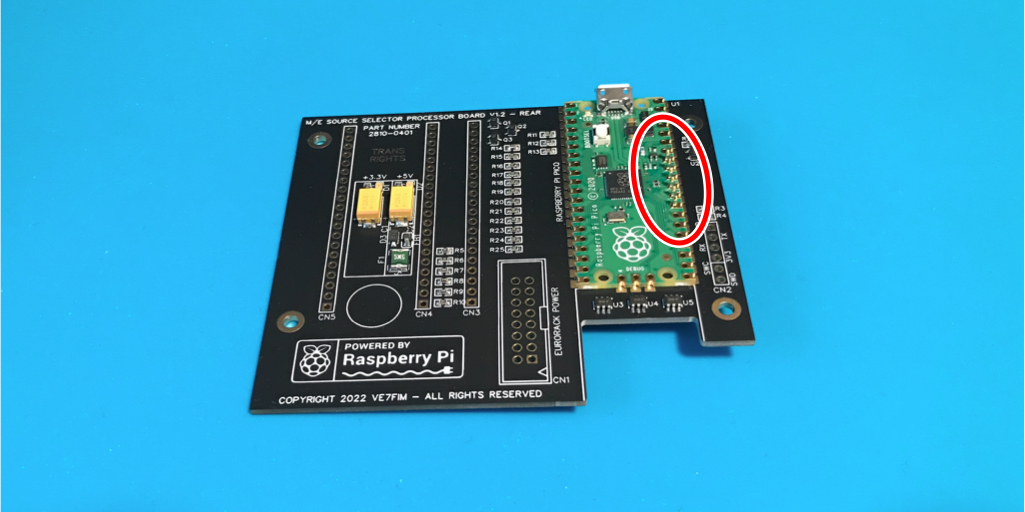
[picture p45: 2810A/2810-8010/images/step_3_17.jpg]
        
           
            Pi Pico module aligned on the 2819-0401 PCB.
      - 
        .. raw:: latex

          \includegraphics[align=t,scale=1]{../../images/doc_stamp.pdf}
    * - 4.3.18
      - Solder the center DEBUG castellated pad on the bottom of the Pi Pico module, then the two corner castellated pads on the top. 

        .. raw:: latex

          \vspace*{1ex}

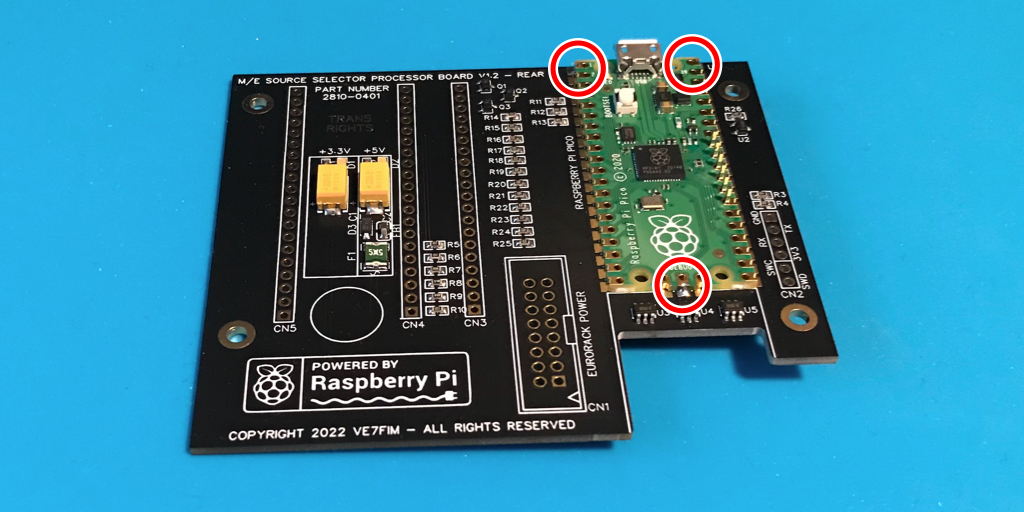
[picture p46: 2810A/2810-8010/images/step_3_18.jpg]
        
           
            2810-0401 PCB with the debug and right corners of the Pi Pico module soldered on.
      - 
        .. raw:: latex

          \includegraphics[align=t,scale=1]{../../images/doc_stamp.pdf}
    * - 4.3.19
      - Remove the 6 pin header, then solder the remainder of the castellated pads.

        .. raw:: latex

          \vspace*{1ex}

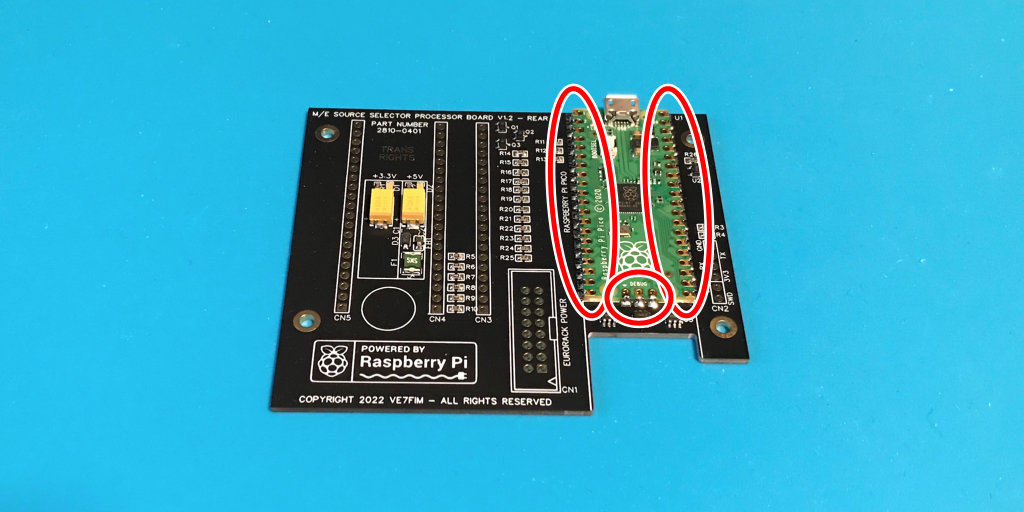
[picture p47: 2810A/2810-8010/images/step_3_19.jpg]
        
           
            2810-0401 PCB with Pi Pico module fully soldered on.
      - 
        .. raw:: latex

          \includegraphics[align=t,scale=1]{../../images/doc_stamp.pdf}
    * - 4.3.20
      - a) Insert the two 20 pin headers into CN4 and CN5 from the front of the board.

        .. raw:: latex

          \vspace*{1ex}

        b) Insert the six pin header into CN3 from the front of the board, to keep the board level. Do not solder CN3.

        .. raw:: latex

          \vspace*{1ex}

        c) Carefully flip the board, and solder one pin of CN4 and CN5, then flip the board again and sure that CN4 and CN5 are 90 degrees to the board. If not, re-align and re-solder to correct.

        .. raw:: latex

          \vspace*{1ex}

        d) Solder the remaining pins on CN4 and CN5.

        .. raw:: latex

          \vspace*{1ex}

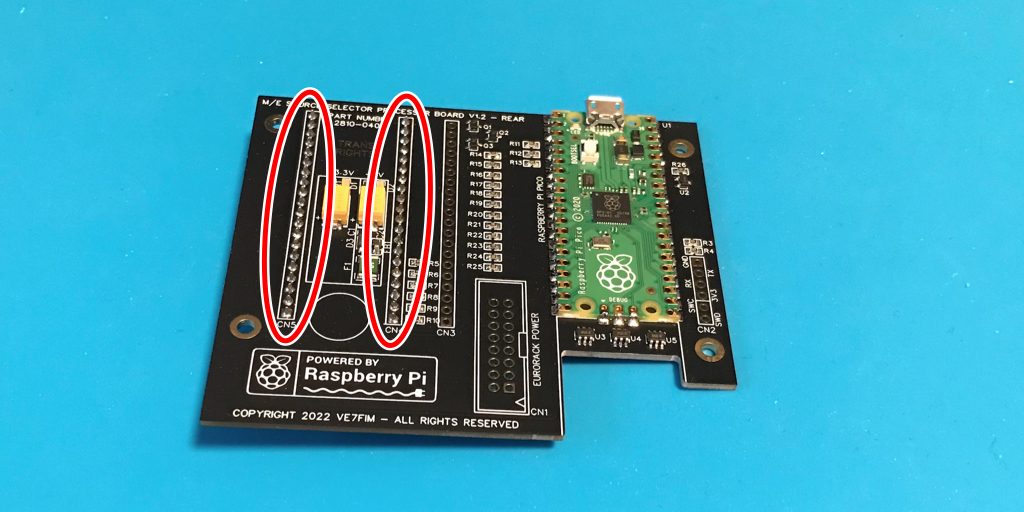
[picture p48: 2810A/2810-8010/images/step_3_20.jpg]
        
           
            2810-0401 PCB with CN4 and CN5 soldered
      - 
        .. raw:: latex

          \includegraphics[align=t,scale=1]{../../images/doc_stamp.pdf}
    * - 4.3.21
      - Solder CN1.

        .. raw:: latex

          \vspace*{1ex}

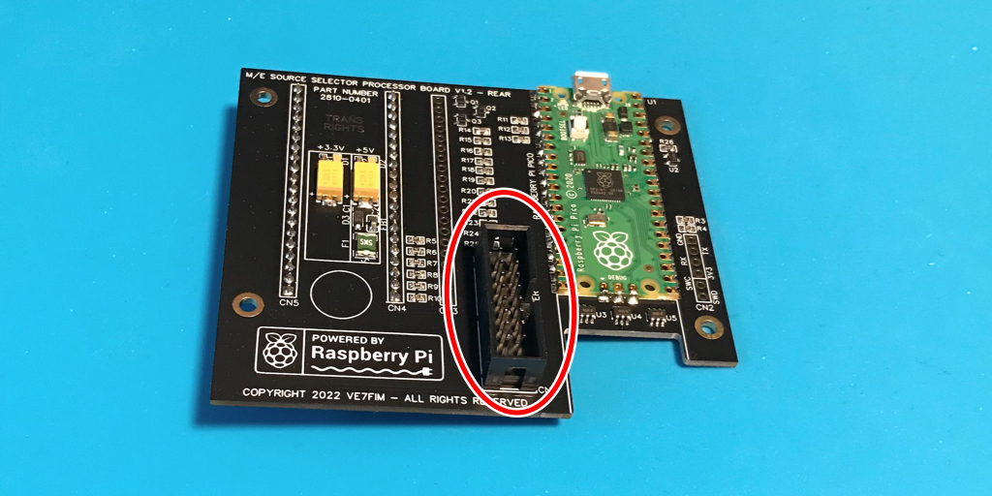
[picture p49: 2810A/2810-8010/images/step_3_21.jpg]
        
           
            2810-0401 PCB with CN1 soldered
      - 
        .. raw:: latex

          \includegraphics[align=t,scale=1]{../../images/doc_stamp.pdf}
    * - 4.3.22
      - a) Insert the six pin header into CN3 from the rear of the board.

        .. raw:: latex

          \vspace*{1ex}

        b) Carefully flip the board, and solder one pin of the header on, then lip the board again, make sure it is 90 degrees to the board. If not, re-align and re-solder to correct.

        .. raw:: latex

          \vspace*{1ex}

        c) Solder the remaining pins on CN3.

        .. raw:: latex

          \vspace*{1ex}

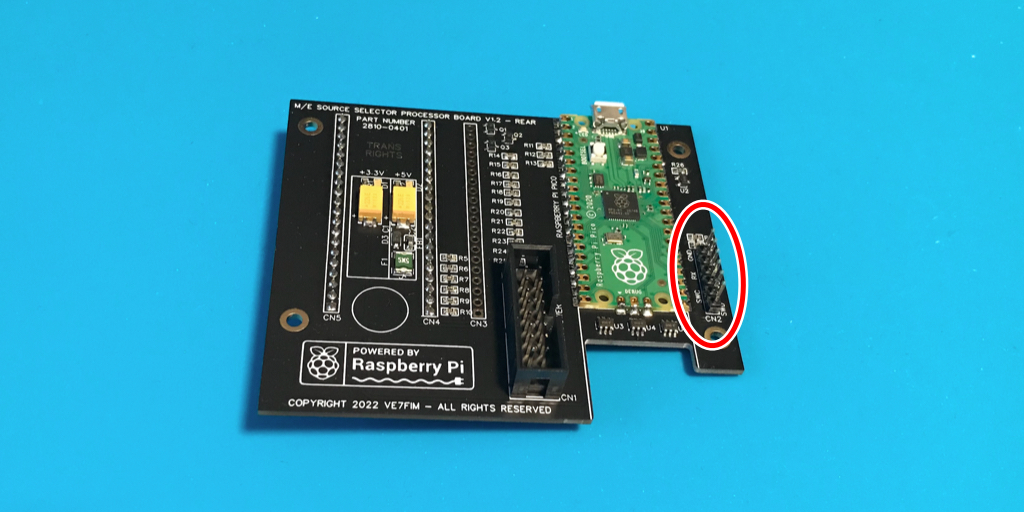
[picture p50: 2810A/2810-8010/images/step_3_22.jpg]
        
           
            2810-0401 PCB with CN3 soldered
      - 
        .. raw:: latex

          \includegraphics[align=t,scale=1]{../../images/doc_stamp.pdf}
    * - 4.3.23
      - Connect the USB to Micro USB cable to the workstation USB power adapter and the Pi Pico mounted on the 2810-0401 PCB. Verify that both power LEDs come on. Disconnect the USB cable, and place the completed assembly beside the assembly mat.

        .. raw:: latex

          \vspace*{1ex}

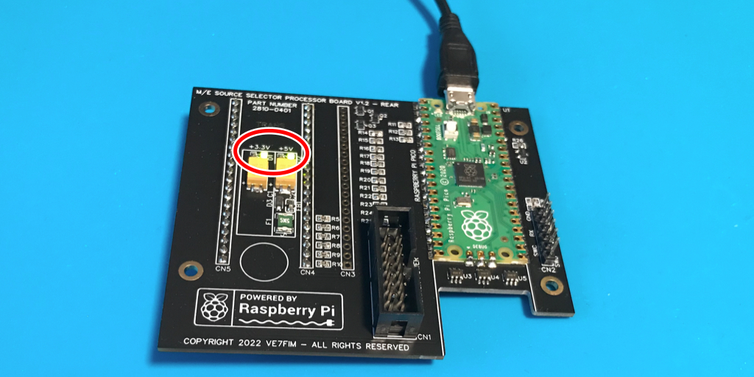
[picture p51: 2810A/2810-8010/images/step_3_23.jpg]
        
           
            Powered 2810-0401 PCB
      - 
        .. raw:: latex

          \includegraphics[align=t,scale=1]{../../images/doc_stamp.pdf}

.. raw:: latex

          \newpage

2810A assembly
**************

This assembly step takes 5 minutes.

.. tabularcolumns:: |>{\raggedright\arraybackslash}\Y{0.10}
                    |>{\raggedright\arraybackslash}\Y{0.70}
                    |>{\raggedright\arraybackslash}\Y{0.20}|

.. _tbl_2810_assembly:

.. list-table:: 2810A assembly steps
    :class: longtable
    :header-rows: 1
    :align: center 

    * - Step #
      - Description
      - Signature/Stamp
    * - 4.4.1
      - Using the tweezers, peel off the four Kapton tape protectors from the LCD module standoff.

        .. raw:: latex

          \vspace*{1ex}

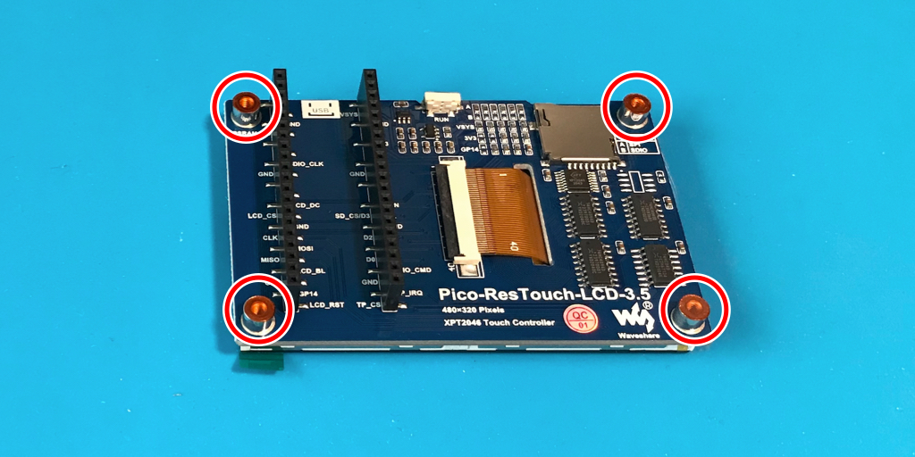
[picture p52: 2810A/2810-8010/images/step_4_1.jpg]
        
           
            LCD module Kapton tape protectors
      - 
        .. raw:: latex

          \includegraphics[align=t,scale=1]{../../images/doc_stamp.pdf}
    * - 4.4.2
      - Take the LCD module and insert it in the hole in the 2810-0301 assembly.

        .. raw:: latex

          \vspace*{1ex}

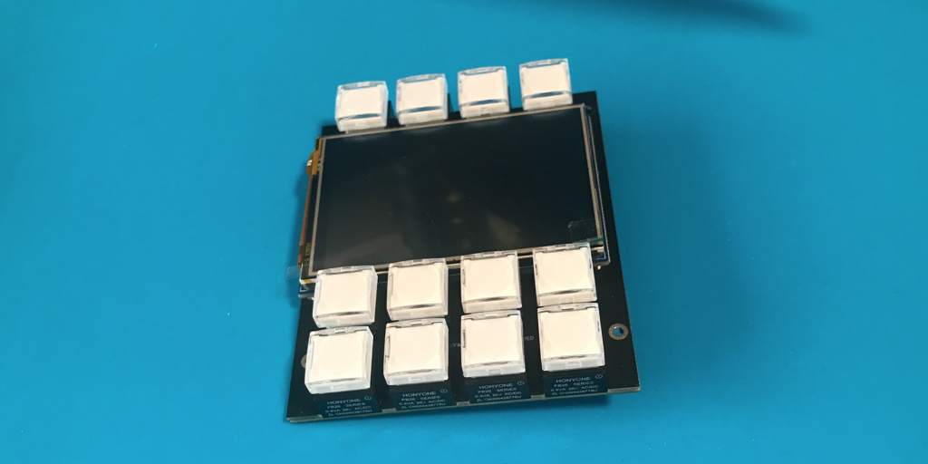
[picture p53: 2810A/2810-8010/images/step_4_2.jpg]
        
           
            LCD inserted in 2810-0301 assembly
      - 
        .. raw:: latex

          \includegraphics[align=t,scale=1]{../../images/doc_stamp.pdf}
    * - 4.4.3
      - Connect the 2810-0401 assembly to the LCD and 2810-0301 assembly.

        .. raw:: latex

          \vspace*{1ex}

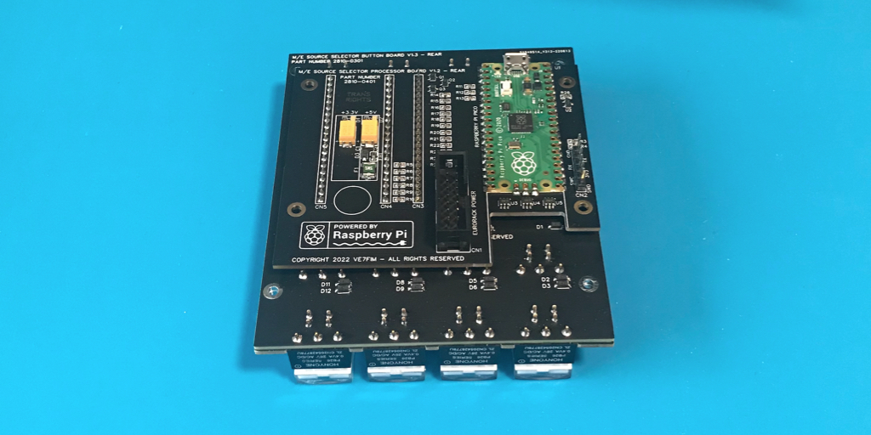
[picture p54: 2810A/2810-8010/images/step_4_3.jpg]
        
           
            2810-0401 assembly connected to 2810-0301 assembly
      - 
        .. raw:: latex

          \includegraphics[align=t,scale=1]{../../images/doc_stamp.pdf}
    * - 4.4.4
      - For each of the four holes connecting the 2810-0401 assembly to the 2810-0301 assembly and to the LCD module, gently insert the 4mm spacer from the side, then insert the 12mm screws and turn until 2mm seperates the screw head from the board. When all four spacers and screws have been attached, tighten all four screws one by one.

        .. raw:: latex

          \vspace*{1ex}

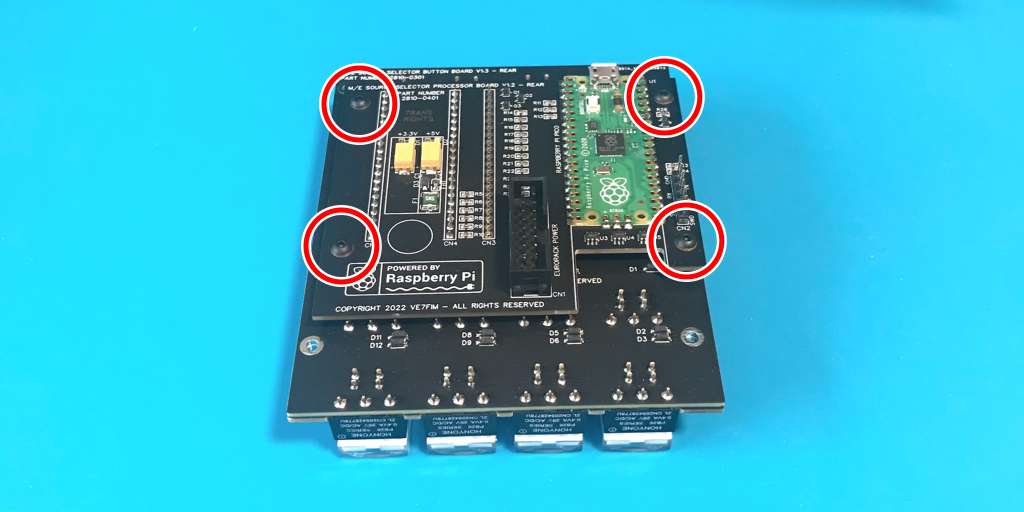
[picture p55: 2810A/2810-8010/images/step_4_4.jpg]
        
           
            Screw attachment of assemblies
      - 
        .. raw:: latex

          \includegraphics[align=t,scale=1]{../../images/doc_stamp.pdf}
    * - 4.4.5
      - Solder the CN3 connector to the 2810-0401 assembly.

        .. raw:: latex

          \vspace*{1ex}

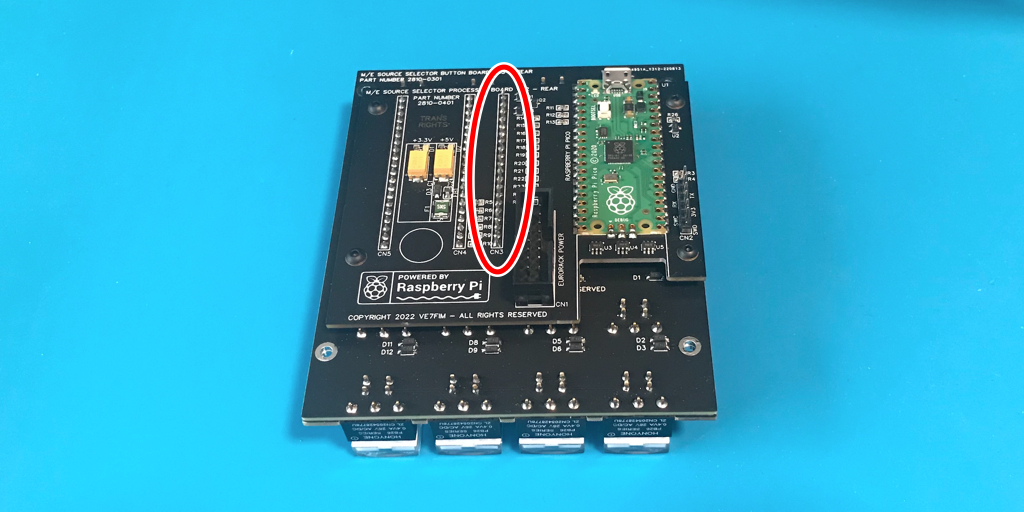
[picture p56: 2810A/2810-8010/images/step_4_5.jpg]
        
           
            CN3 connector soldered to 2810-0401 assembly.
      - 
        .. raw:: latex

          \includegraphics[align=t,scale=1]{../../images/doc_stamp.pdf}
    * - 4.4.6
      - Remove the LCD screen protector

        .. raw:: latex

          \vspace*{1ex}

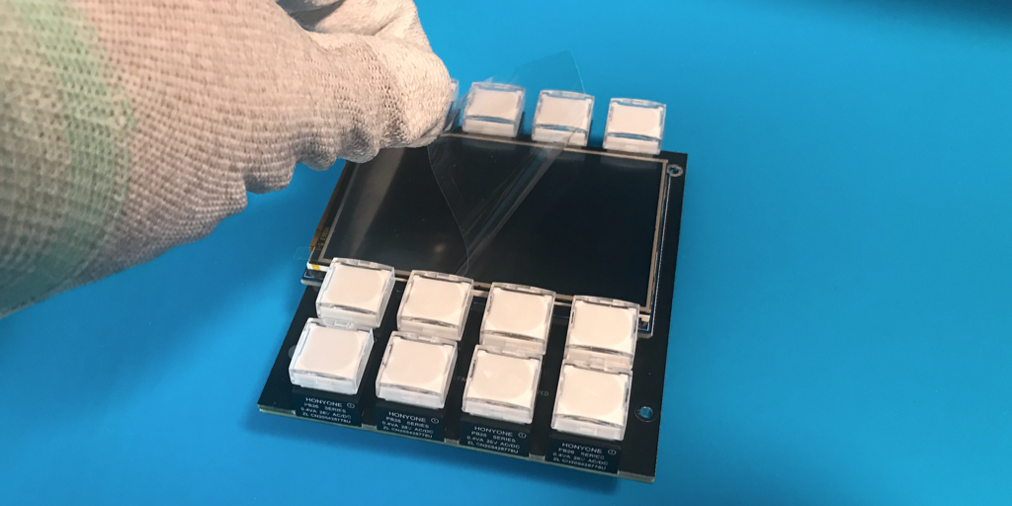
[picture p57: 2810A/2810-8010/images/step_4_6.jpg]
        
           
            Removing LCD protector
      - 
        .. raw:: latex

          \includegraphics[align=t,scale=1]{../../images/doc_stamp.pdf}
    * - 4.4.7
      - Align and attach the 2810-0101 assembly using four 5mm screws.

        .. raw:: latex

          \vspace*{1ex}

        At this point, the 2810A is fully assembled and ready to program.

        .. raw:: latex

          \vspace*{1ex}

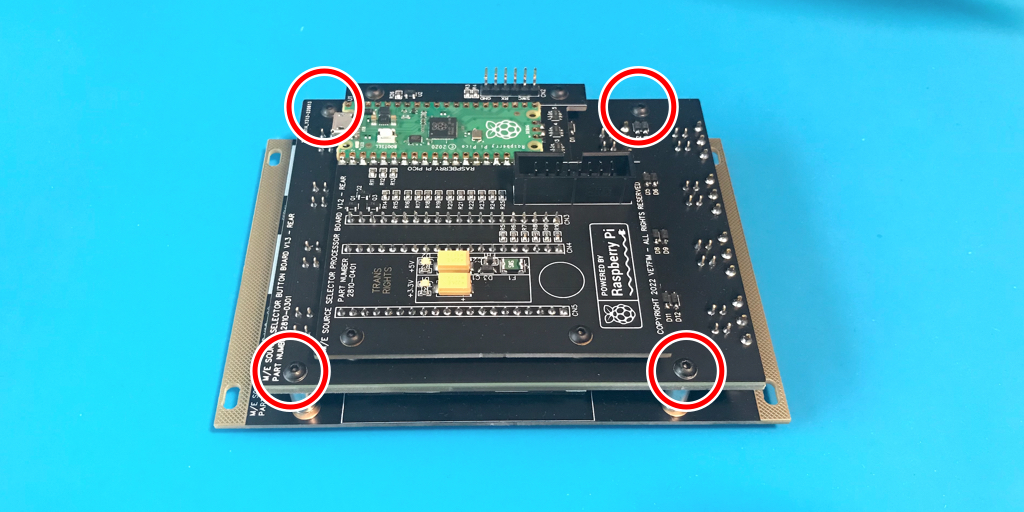
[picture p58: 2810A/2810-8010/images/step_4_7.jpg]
        
           
            Screw attachment of 2810-0101 assembly
      - 
        .. raw:: latex

          \includegraphics[align=t,scale=1]{../../images/doc_stamp.pdf}

2810A programming
*****************

This assembly step takes 5 minutes.

.. tabularcolumns:: |>{\raggedright\arraybackslash}\Y{0.10}
                    |>{\raggedright\arraybackslash}\Y{0.70}
                    |>{\raggedright\arraybackslash}\Y{0.20}|

.. _tbl_2810_programming:

.. list-table:: 2810A programming steps
    :class: longtable
    :header-rows: 1
    :align: center 

    * - Step #
      - Description
      - Signature/Stamp
    * - 4.5.1
      - Connect the programming cable connected to the 2810A programmer.

        .. raw:: latex

          \vspace*{1ex}

        
           
            Programmer connected to the 2810A assembly
      - 
        .. raw:: latex

          \includegraphics[align=t,scale=1]{../../images/doc_stamp.pdf}
    * - 4.5.2
      - Connect the USB to Micro USB cable to the workstation USB power adapter and the 2810A programmer. Verify that the screen turns on.

        .. raw:: latex

          \vspace*{1ex}

        
           
            Powered up programmer.
      - 
        .. raw:: latex

          \includegraphics[align=t,scale=1]{../../images/doc_stamp.pdf}
    * - 4.5.3
      - Wait for two minutes for the programmer to start up and program the 2810A. The 2810 will go through it's startup process, alternating through all of the button primary colours, and showing the logo and firmware version on the LCD. Record the firmware version in the "signature" column to the right:

        .. raw:: latex

          \vspace*{1ex}

        
           
            2810A starting up after being programmed.
      - 
        .. raw:: latex

          \includegraphics[align=t,scale=1]{../../images/doc_stamp.pdf}
    * - 4.5.4
      - Disconnect the power USB connector from the programmer, then disconnect the programmer from the now programmed 2810A.

        .. raw:: latex

          \vspace*{1ex}

        
           
            Programmed 2810A
      - 
        .. raw:: latex

          \includegraphics[align=t,scale=1]{../../images/doc_stamp.pdf}

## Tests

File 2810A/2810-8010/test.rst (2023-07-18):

****
Test
****

Visual inspection
*****************

This test process takes 2 minutes.

.. tabularcolumns:: |>{\raggedright\arraybackslash}\Y{0.10}
                    |>{\raggedright\arraybackslash}\Y{0.70}
                    |>{\raggedright\arraybackslash}\Y{0.20}|

.. _tbl_2810_visual_inspection:

.. list-table:: 2810A visual inspection
    :class: longtable
    :header-rows: 1
    :align: center 

    * - Step #
      - Description
      - Signature
    * - 5.1.1
      - Verify that there are no loose parts.
      - 
        .. raw:: latex

          \includegraphics[align=t,scale=1]{../../images/doc_stamp.pdf}
    * - 5.1.2
      - Verify that there are no visible fingerprints.
      - 
        .. raw:: latex

          \includegraphics[align=t,scale=1]{../../images/doc_stamp.pdf}

.. raw:: latex

          \newpage

QC final check
**************

This test process takes 2 minutes.

.. tabularcolumns:: |>{\raggedright\arraybackslash}\Y{0.10}
                    |>{\raggedright\arraybackslash}\Y{0.70}
                    |>{\raggedright\arraybackslash}\Y{0.20}|

.. _tbl_2810_qc_final:

.. list-table:: 2810A QC final check
    :class: longtable
    :header-rows: 1
    :align: center 

    * - Step #
      - Description
      - Signature
    * - 5.2.1
      - Connect the USB to Micro USB cable to the workstation USB power adapter and the Pi Pico mounted on the 2810-0401 PCB. Verify that the 2810A starts up and displays the expected "Unconfigured" screen.

        .. raw:: latex

          \vspace*{1ex}

        If test does not pass, write down the unexpected behaviour in the "signature" column on the right.

        .. raw:: latex

          \vspace*{1ex}

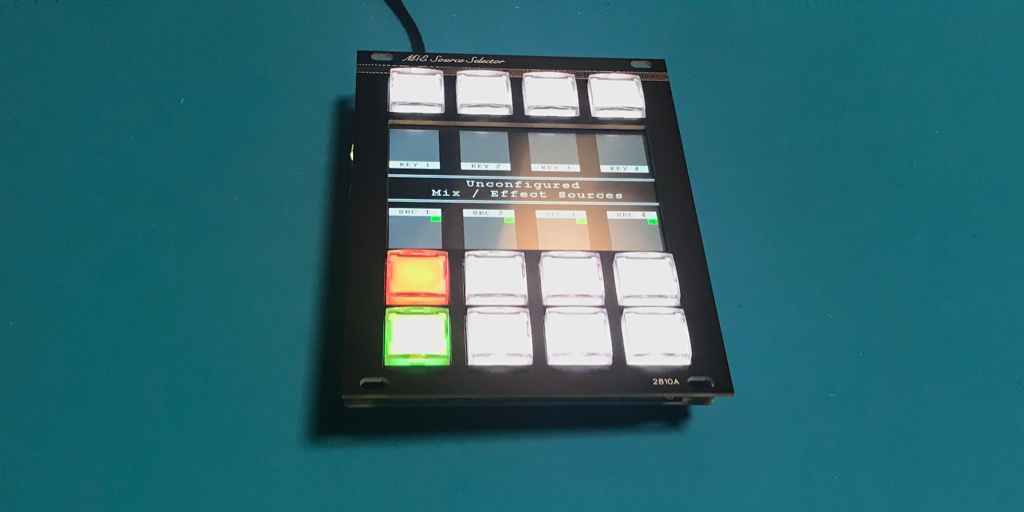
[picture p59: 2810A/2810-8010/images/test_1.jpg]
        
           
            Powered 2810-0401 PCB
      - 
        .. raw:: latex

          \includegraphics[align=t,scale=1]{../../images/doc_stamp.pdf}
    * - 5.2.2
      - While holding the bottom-left button, press the top-left button. The 2810A will enter self-test mode.

        .. raw:: latex

          \vspace*{1ex}

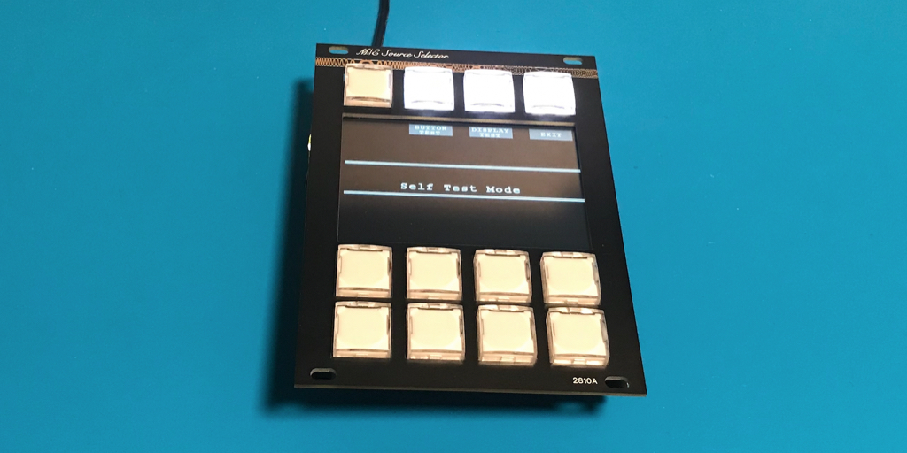
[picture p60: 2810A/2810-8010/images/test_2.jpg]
        
           
            2810A in self-test mode
      - 
        .. raw:: latex

          \includegraphics[align=t,scale=1]{../../images/doc_stamp.pdf}
    * - 5.2.3
      - Press the button labelled "Button Test". The 2810A will cycle through Red/Green/Blue for each button.

        .. raw:: latex

          \vspace*{1ex}

        If test does not pass, write down the unexpected behaviour in the "signature" column on the right.

        .. raw:: latex

          \vspace*{1ex}

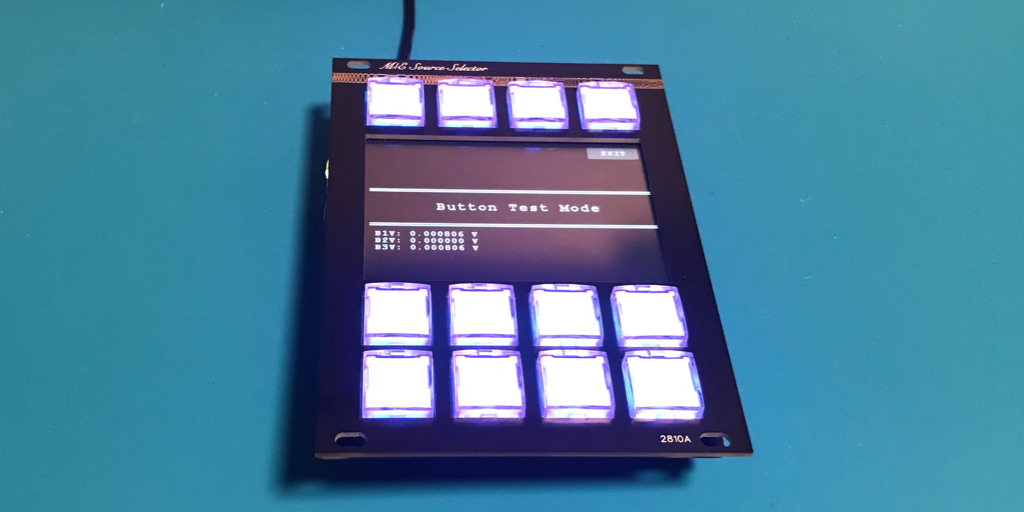
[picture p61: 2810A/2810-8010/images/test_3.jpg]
        
           
            2810A button test mode
      - 
        .. raw:: latex

          \includegraphics[align=t,scale=1]{../../images/doc_stamp.pdf}
    * - 5.2.4
      - Exit button test mode. Press the button labelled "Display Test". The 2810A will display the logo. Press the Red, Breen and Blue buttons to verify that there are no stuck pixels.

        .. raw:: latex

          \vspace*{1ex}

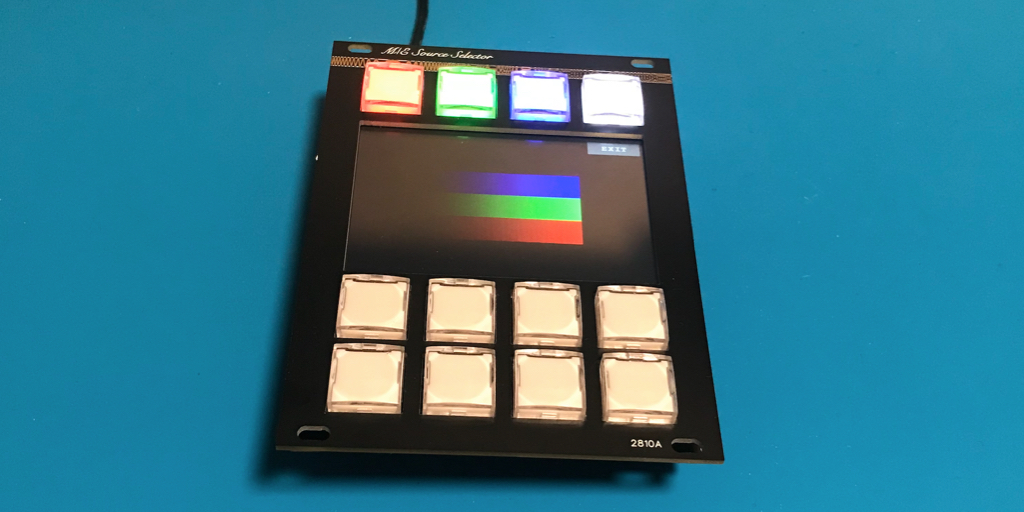
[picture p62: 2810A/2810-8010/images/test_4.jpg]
        
           
            2810A display test mode
      - 
        .. raw:: latex

          \includegraphics[align=t,scale=1]{../../images/doc_stamp.pdf}
    * - 5.2.5
      - Disconnect the USB cable
      - 
        .. raw:: latex

          \includegraphics[align=t,scale=1]{../../images/doc_stamp.pdf}

.. raw:: latex

          \newpage

QC PASS
*******

Only perform these steps if all QC checks have passed.

This test process takes 1 minutes.

.. tabularcolumns:: |>{\raggedright\arraybackslash}\Y{0.10}
                    |>{\raggedright\arraybackslash}\Y{0.70}
                    |>{\raggedright\arraybackslash}\Y{0.20}|

.. _tbl_2810_qc_approval:

.. list-table:: 2810A QC approval
    :class: longtable
    :header-rows: 1
    :align: center 

    * - Step #
      - Description
      - Signature
    * - 5.3.1
      - Using the tweezers, affix QC Passed sticker in location shown below, then write down the serial number from the QC sticker below the "Signature/Stamp" in the column to the right.

        .. raw:: latex

          \vspace*{1ex}

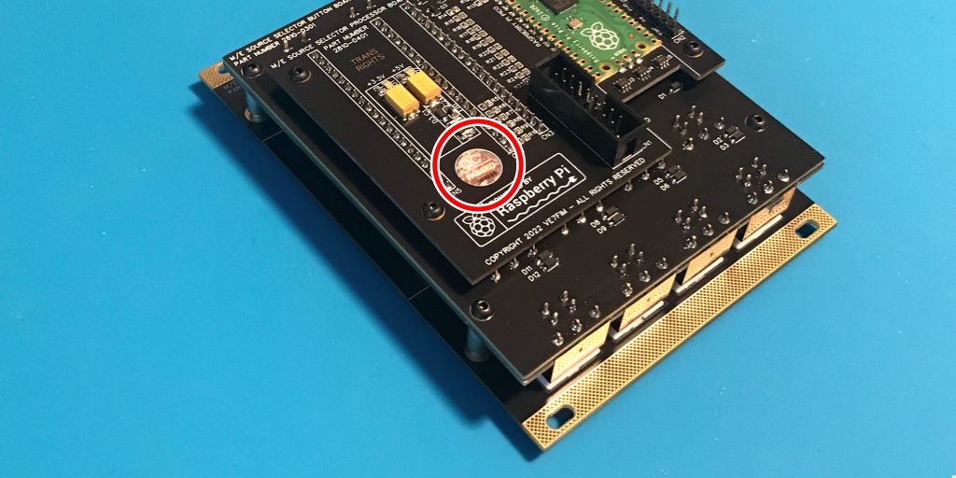
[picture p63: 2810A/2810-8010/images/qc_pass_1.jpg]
        
           
            2810A with QC Passed sticker
      - 
        .. raw:: latex

          \includegraphics[align=t,scale=1]{../../images/doc_stamp.pdf}
    * - 5.3.2
      - Detach the front panel by unscrewing the four screws that attach the 2810-0101 PCBA. Using the sharpie pen, write down the serial number from the QC sticker, and QC date, on the front panel PCB. Re-attach the 2810-0101 PCBA.

        .. raw:: latex

          \vspace*{1ex}

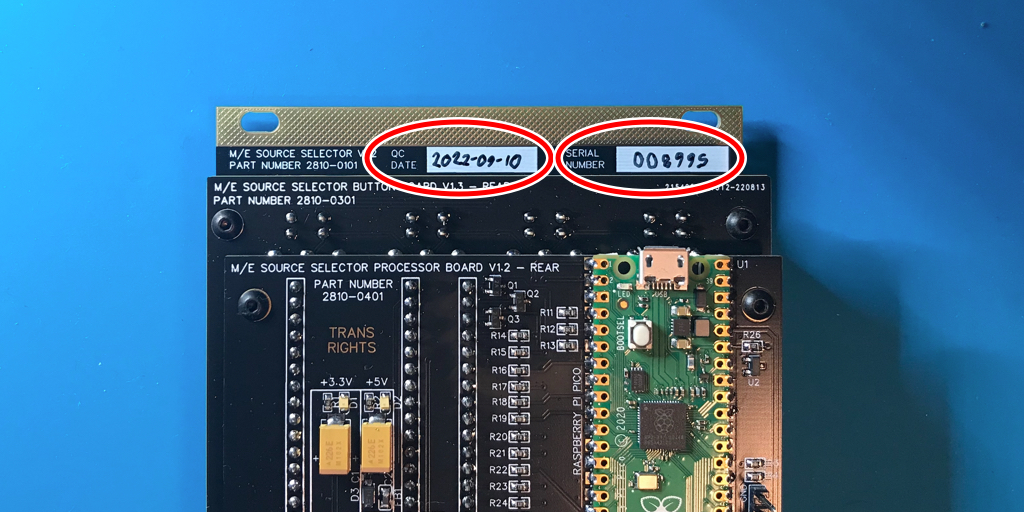
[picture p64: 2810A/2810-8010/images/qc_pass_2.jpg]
        
           
            2810A with SN and QC Date
      - 
        .. raw:: latex

          \includegraphics[align=t,scale=1]{../../images/doc_stamp.pdf}
    * - 5.3.3
      - Take two photographs, one of the front of the 2810A, and one of the back of the 2819A.
      - 
        .. raw:: latex

          \includegraphics[align=t,scale=1]{../../images/doc_stamp.pdf}

.. raw:: latex

          \newpage

QC FAIL
*******

Only perform these steps if any QC check have failed.

This test process takes 2 minutes.

.. tabularcolumns:: |>{\raggedright\arraybackslash}\Y{0.10}
                    |>{\raggedright\arraybackslash}\Y{0.70}
                    |>{\raggedright\arraybackslash}\Y{0.20}|

.. _tbl_2810_qc_fail:

.. list-table:: 2810A QC fail
    :class: longtable
    :header-rows: 1
    :align: center 

    * - Step #
      - Description
      - Signature
    * - 5.4.1
      - Place the 2810A module in the bubble-wrap anti-static bag.

        .. raw:: latex

          \vspace*{1ex}

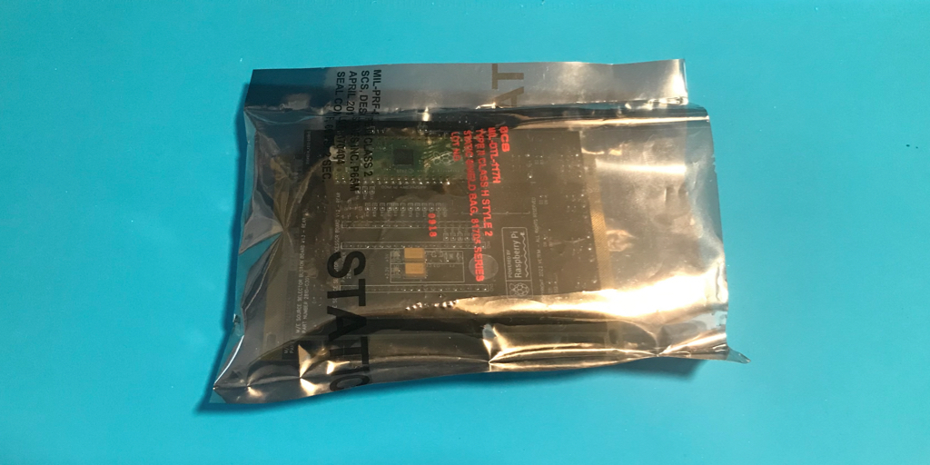
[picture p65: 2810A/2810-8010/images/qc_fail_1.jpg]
        
           
            2810A in anti-static bag.
      - 
        .. raw:: latex

          \includegraphics[align=t,scale=1]{../../images/doc_stamp.pdf}
    * - 5.4.2
      - Place 2810A in the "QC Fail bin", along with this document.

        .. raw:: latex

          \vspace*{1ex}

        
           
            2810A in QC Fail bin.
      - 
        .. raw:: latex

          \includegraphics[align=t,scale=1]{../../images/doc_stamp.pdf}

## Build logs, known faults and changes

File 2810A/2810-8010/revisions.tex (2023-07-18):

\newpage
{\Large Revision history }\par
\begin{savenotes}\sphinxatlongtablestart\begin{longtable}[c]{|>{\raggedright\arraybackslash}\Y{0.10}
|>{\raggedright\arraybackslash}\Y{0.20}
|>{\raggedright\arraybackslash}\Y{0.50}
|>{\raggedright\arraybackslash}\Y{0.20}|}
\sphinxthelongtablecaptionisattop
\caption{Document Revisions\strut}\label{\detokenize{revisions:id1}}\label{\detokenize{revisions:tbl-revisions}}\\*[\sphinxlongtablecapskipadjust]
\hline
\sphinxstyletheadfamily 
Version
&\sphinxstyletheadfamily 
Date
&\sphinxstyletheadfamily 
Change
&\sphinxstyletheadfamily 
Approver
\\
\hline
\endfirsthead

\multicolumn{4}{c}%
{\makebox[0pt]{\sphinxtablecontinued{\tablename\ \thetable{} \textendash{} continued from previous page}}}\\
\hline
\sphinxstyletheadfamily 
Version
&\sphinxstyletheadfamily 
Date
&\sphinxstyletheadfamily 
Change
&\sphinxstyletheadfamily 
Approver
\\
\hline
\endhead

\hline
\multicolumn{4}{r}{\makebox[0pt][r]{\sphinxtablecontinued{continues on next page}}}\\
\endfoot

\endlastfoot

0.1
&
2022\sphinxhyphen{}06\sphinxhyphen{}04
&
Initial draft for internal review
&
D. Slik
\\
\hline
0.2
&
2022\sphinxhyphen{}06\sphinxhyphen{}27
&
Added packaging section
&
D. Slik
\\
\hline
0.3
&
2022\sphinxhyphen{}08\sphinxhyphen{}16
&
Added RoHS declarations
&
D. Slik
\\
\hline
0.4
&
2022\sphinxhyphen{}09\sphinxhyphen{}05
&
Updateed to use assembly documentation template version 2
&
D. Slik
\\
\hline
\end{longtable}\sphinxatlongtableend\end{savenotes}

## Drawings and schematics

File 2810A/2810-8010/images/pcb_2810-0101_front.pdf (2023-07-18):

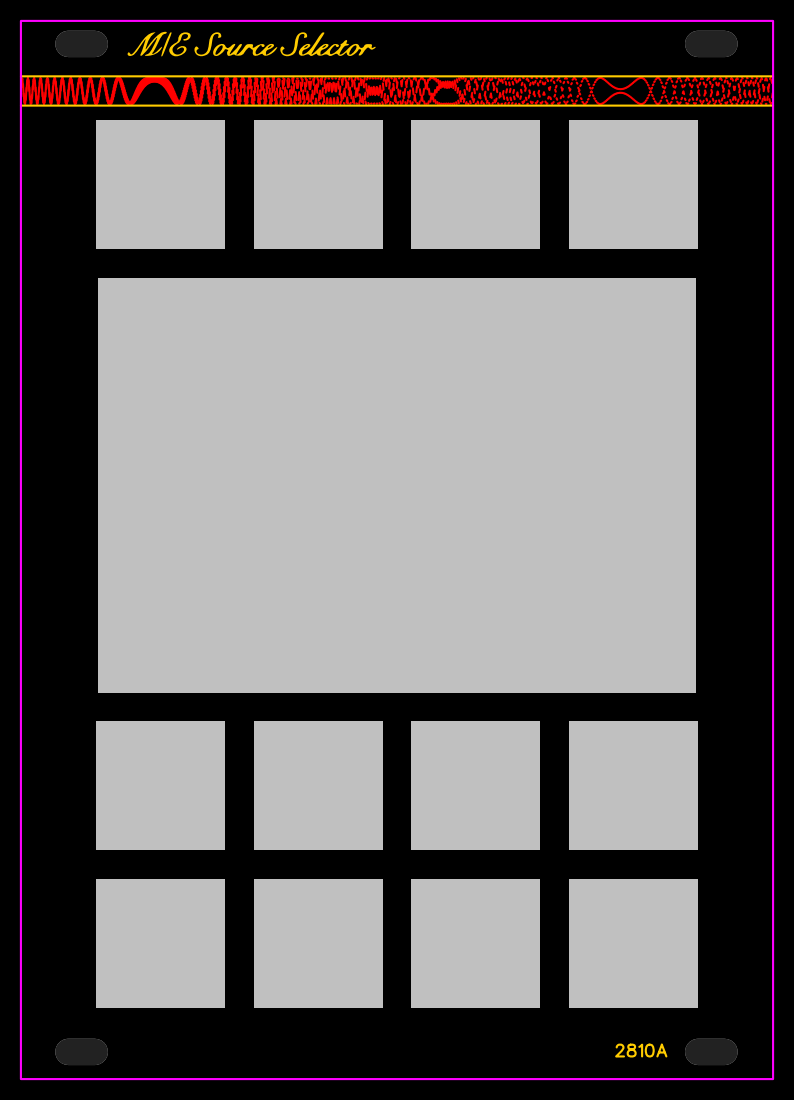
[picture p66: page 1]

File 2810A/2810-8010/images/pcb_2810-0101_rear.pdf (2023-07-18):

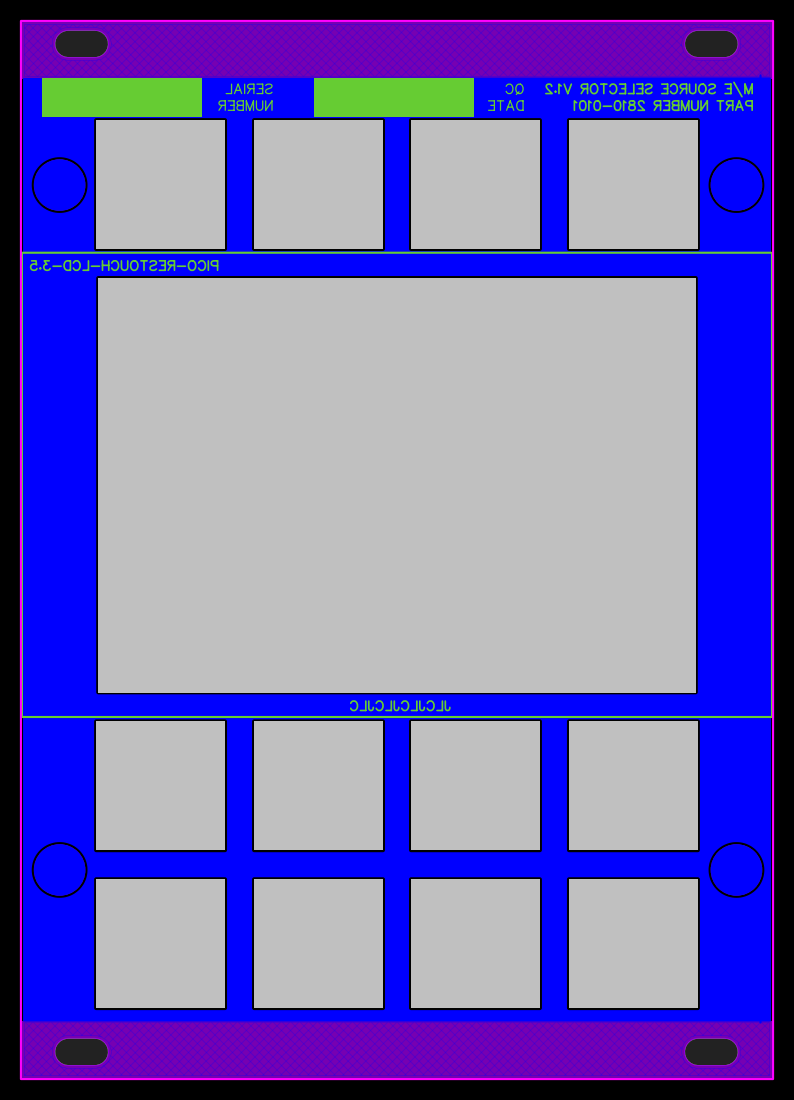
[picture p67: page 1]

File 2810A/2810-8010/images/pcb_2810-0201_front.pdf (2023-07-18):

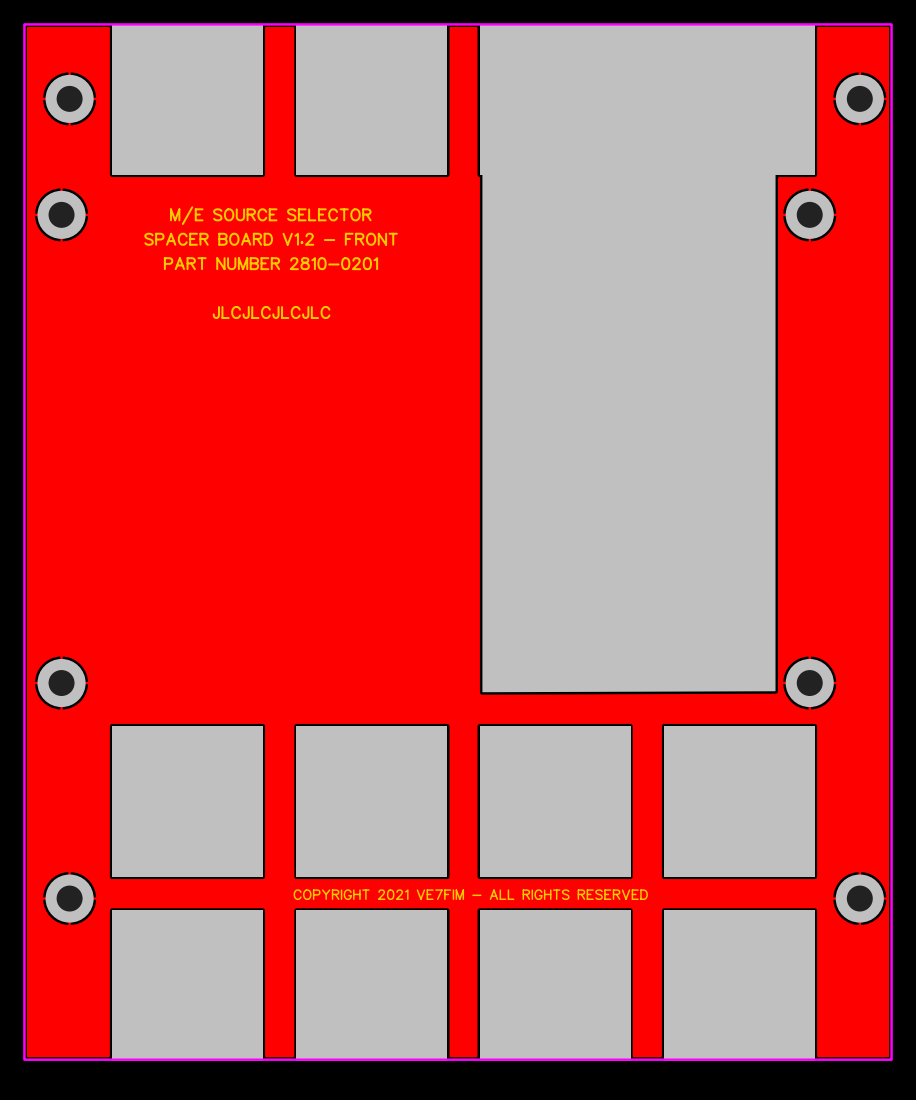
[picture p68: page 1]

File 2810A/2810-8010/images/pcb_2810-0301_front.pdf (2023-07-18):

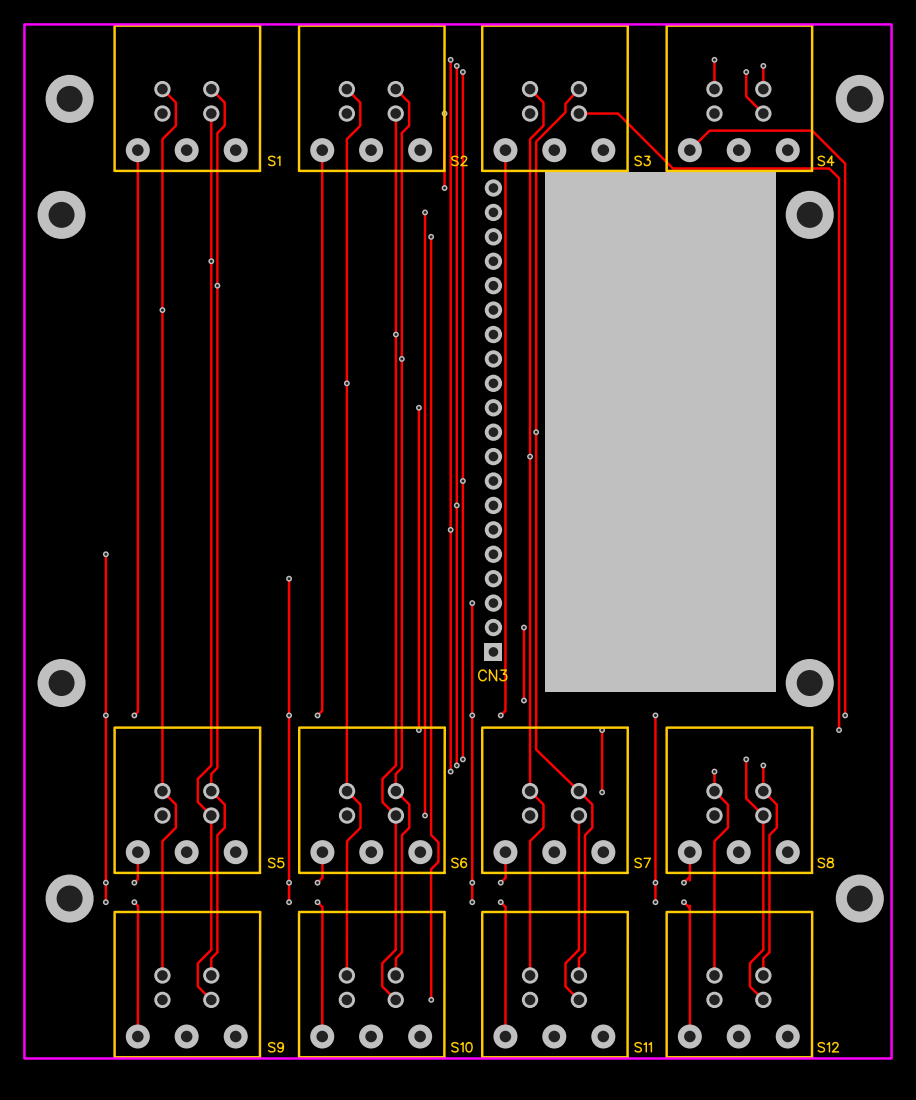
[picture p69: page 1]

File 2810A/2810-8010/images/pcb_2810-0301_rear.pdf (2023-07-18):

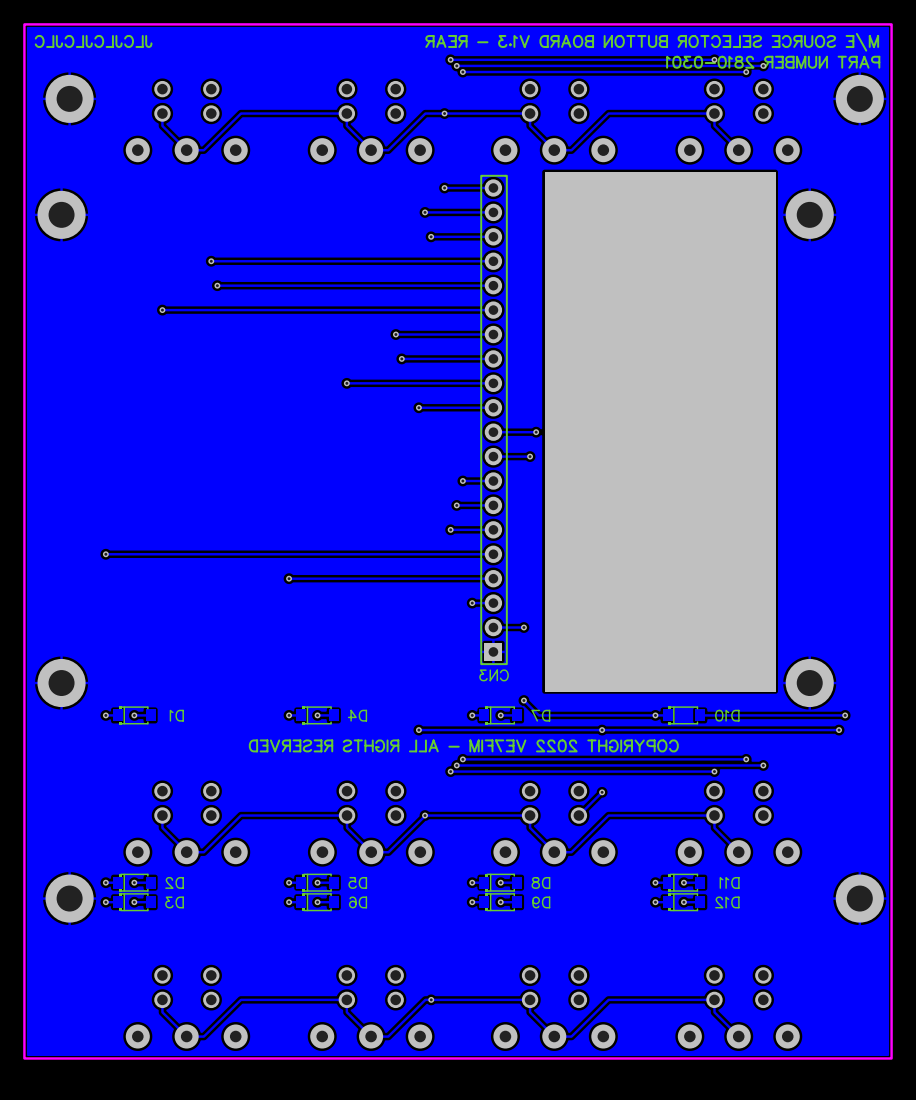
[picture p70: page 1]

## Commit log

2023-07-18 Added readme, switched license
2023-07-18 PCBs for 2810A
    [Drill_NPTH_Through.DRL, Drill_PTH_Through.DRL, Drill_PTH_Through_Via.DRL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]
2023-07-18 PCBs for 2811A
    [Drill_NPTH_Through.DRL, Drill_PTH_Through.DRL, Drill_PTH_Through_Via.DRL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]
2023-07-18 PCBs for 2820A
    [Drill_NPTH_Through.DRL, Drill_PTH_Through.DRL, Drill_PTH_Through_Via.DRL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]
2023-07-18 PCBs for 2821A
    [Drill_NPTH_Through.DRL, Drill_PTH_Through.DRL, Drill_PTH_Through_Via.DRL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]
2023-07-18 PCBs for 2850A
    [Drill_NPTH_Through.DRL, Drill_PTH_Through.DRL, Drill_PTH_Through_Via.DRL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]
2023-07-18 PCBs for 2851A
    [Drill_NPTH_Through.DRL, Drill_PTH_Through.DRL, Drill_PTH_Through_Via.DRL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]
2023-07-18 PCBs for 2860A
    [Drill_NPTH_Through.DRL, Drill_PTH_Through.DRL, Drill_PTH_Through_Via.DRL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]
2023-07-18 PCBs for 2880A
    [Drill_NPTH_Through.DRL, Drill_PTH_Through.DRL, Drill_PTH_Through_Via.DRL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]
2023-07-18 PCBs for 2890A
    [Drill_NPTH_Through.DRL, Drill_PTH_Through.DRL, Drill_PTH_Through_Via.DRL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]
